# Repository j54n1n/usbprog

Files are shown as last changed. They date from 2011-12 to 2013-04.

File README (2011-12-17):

usbprog is a developer kit for atmels avr controller

	its supports:
		- an ISP Interface (AVRISP mkII Klon)
		- a JTAG Interface (JTAGICE mkII Klon)
		- a seriell Interface (RS232 with an GNU/Linux kernelmodule to use it as /dev/ttyUSBx)

Folders:

avarice_corner
++++++++++++++
Server for the connection between GDB and the jtag interface of the target controller.

avrdude_corner
++++++++++++++
Here is a patched Version of avrdude for usbprog

avrupdate
+++++++++

board
+++++
Schematic, Layout, Partlist

firmware
++++++++
Actual firmware of usbprog

ownflashtool
++++++++++++
I used this tool only for testing

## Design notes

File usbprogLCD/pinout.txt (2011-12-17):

usbprog_lcd
===========

- connect an alphanumeric LCD with HD44780 controller to USBprog
- usbprog 3.0 required!

LCD signal    usbprog pin
-------------------------
GND           10
VCC           2
RS            8 (PB2)
R/W           6 (PB1)
E             4 (PB3)
DB4           3 (PB4)
DB5           1 (PB5)
DB6           9 (PB6)
DB7           7 (PB7)

LCD contrast voltage pin V0:

         VCC
          |
          |
         ---
         | |_
         | /
 V0 _____|/| 10k
         | |
         | |
         ---
          |
          |
         GND

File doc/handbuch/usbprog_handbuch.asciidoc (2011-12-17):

// vim: set sw=2 ts=2 ft=asciidoc spelllang=de_de spell:

USBprog Handbuch
================
:Author: http://www.embedded-projects.net/usbprog/
:Revision: 0.2
:Date: 13. Januar 2008

Im folgenden Handbuch wird die Inbetriebnahme und der Einsatz von USBprog beschrieben.

An dieser Stelle möchte ich mich bei den viele Helfern rund um USBprog bedanken.
Ohne der Community wäre das Projekt nicht das, was es mittlerweile ist. 

Die meisten Texte aus diesem Handbuch stammen von Benedikt Sauter. Es haben unteranderem
Texte für diese Handbuch geschrieben: Robert Schilling, Bernhard Walle und Sven Lütke.

*Kontakt*

Embedded Projects Shop

Inh. Dipl.-Inf. (FH) Benedikt Sauter

Kettengäßchen 6

D-86152 Augsburg

mailto:shop@embedded-projects.net[shop@embedded-projects.net],

http://www.embedded-projects.net[http://www.embedded-projects.net]

*Support*

Support gibt es im http://forum.embedded-projects.net/[Forum]
oder per E-Mail (mailto:sauter@ixbat.de[sauter@ixbat.de]).

*Lizenz*

Dieses Handbuch wurde unter der freien Lizenz GFDL veröffentlicht. Dies bedeutet
jeder hat das Recht den Text zu bearbeiten, muss ihn jedoch ebenfalls wieder
unter der freien Lizenz GFDL veröffentlichen.

Copyright © 2007-2008 mailto:sauter@ixbat.de[Benedikt Sauter], 
Robert Schilling, mailto:bernhard.walle@gmx.de[Bernhard Walle], Sven Lütke

  Permission is granted to copy, distribute and/or modify this document
  under the terms of the GNU Free Documentation License, Version 1.2
  or any later version published by the Free Software Foundation;
  with no Invariant Sections, no Front-Cover Texts, and no Back-Cover
  Texts.  A copy of the license is included in the section entitled "GNU
  Free Documentation License".

Einsatzgebiet und Funktionsumfang
---------------------------------

Was ist USBprog?
~~~~~~~~~~~~~~~~

usbprog ist ein freier Programmieradapter. Über USB kann man bequem verschiedene Firmwareversionen
aus einem "Firmware-Archiv" einspielen. Der Adapter kann aktuell für das Programmieren 
und Debuggen von AVR- und ARM-Prozessoren, als USB-zu-RS232-Wandler, als JTAG-Schnittstelle oder als 
einfacher I/O-Port (10 Leitungen) eingesetzt werden.

Wer braucht usbprog?
~~~~~~~~~~~~~~~~~~~~

Hardware- und Softwareentwickler, die unter Windows, Linux & Co. arbeiten.

Was ist das Besondere an dem Konzept von usbprog?
~~~~~~~~~~~~~~~~~~~~~~~~~~~~~~~~~~~~~~~~~~~~~~~~~

Mit der Zeit soll ein immer größerer Pool an Firmwareversionen enstehen. Idealerweise kann man dann 
als Besitzer von usbprog, wenn man einen neuen Baustein bekommt, mit dem man arbeiten soll, in den 
Online-Pool schauen und suchen, ob es eine passende Firmware zum Programmieren oder Ansteuern 
von diesem Baustein gibt.

Sollte es gerade keine passende Firmware für den benötigten Baustein geben, so sollte man nicht 
überstürzt hohe Einkaufspreise für Adapter auf sich nehmen, sondern zuerst lieber anfragen, 
ob es lohnenswert ist, hier eine neue Firmware für usbprog zu schreiben, um somit in den Firmware-Pool 
zu investieren. Oft ist dies relativ schnell geschehen, da man auf bestehenden Softwarewerkzeuge aufbauen 
kann. Wie im Falle vom AVRISP-mkII-Klon: Diesen kann man mit allen Anwendungen nutzen, die den originalen 
Adapter von Atmel unterstützen. Oder der Adapter für den OpenOCD: Es wurde ebenfalls binnen weniger Tage
entwickelt!

Da alles unter einer Open-Source-Lizenz steht, sollte das Projekt lange Zeit interessant bleiben!

Auszug aus der Firmwareliste
----------------------------

* AVR ISP Programmer (kompatibel zu AVRISP mkII)
* OpenOCD-Interface (ARM Debugging)
* Freier JTAG Adapter und Bibliothek 
* AT89 Programmer 
* SimplePort (10 I/O-Leitungen)
* USB-zu-RS232-Wandler (ohne Treiber!) 
* XSVF Player (Xilinx CPLD/FPGA)
* Logikanalysator

Montage und Aufbau der Hardware
-------------------------------

Die folgende Übersicht gibt einen groben Leitfaden für die Installation.

- Auspacken des Bausatzes (vormontierte Platine, 10-poliger Stecker, USB-Buchse, 2x4-polige Stiftleisten, 1x3-polige Stiftleiste, 3 Jumper)
- USBprog fertig montieren (löten)

Abhängig davon, ob ein bereits vorprogrammierter oder nicht-vorprogrammierter Adapter gekauft worden ist, 
gibt es zwei mögliche Wege:

- USBprog ist bereits vorprogrammiert
  . Benötigte Anwendung (z. B. AVR Studio für AVR-Mikrocontroller oder Yagarto für OpenOCD) installieren
  . USBprog Flashtool installieren
- USBprog ist noch nicht programmiert
  . VCC Jumper entfernen, falls externer AVR Programmierer keine Stromversorgung benötigt
  . Externen AVR Programmer anstecken
  . Reset Jumper stecken
  . usbprog_base.hex flashen
  . Fuse-Bits programmieren
  . Jumper entfernen
  . USBprog Tools installieren (inkl. Treiber)
  . Am PC anstecken -> Neues Gerät sollte erkannt werden (Treiber automatisch installieren)
  . Per Flashtool gewünschte Firmware einspielen

Dies war nur ein grober Leitfaden. In den weiteren Abschnitten werden die einzelnen Schritte
genauer beschrieben.

Löten der restlichen Bauteile
~~~~~~~~~~~~~~~~~~~~~~~~~~~~~

Der USBprog Adapter 3.0 ist anders als die vorherige Version bereits vormontiert. 
Die SMD-Bauteile sind bereits gelötet und nur die "groben" Bauteile müssen selbst angebracht werden. 

Der Adapter wurde so geplant, dass Anstelle der USB-B-Buchse auch ein USB-A-Stecker eingelötet werden kann.
Letzterer hat den Vorteil, dass USBprog in einem passendem Gehäuse als USB-Stick verwendet werden kann.

Folgende Schritte beim Löten sind somit zu erledigen:

* 10-polige Wannenbuchse einlöten
* USB-Buchse montieren und einlöten
* 2x4-polige Stiftleiste fixieren und einlöten
* 3-polige Stiftleiste fixieren und einlöten

In der Abbildung "USBprog Bausatz" sind nochmal alle Bauteile gezeigt.

.USBprog Bausatz
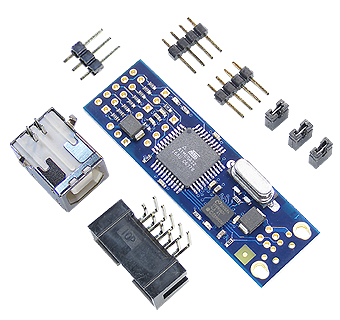
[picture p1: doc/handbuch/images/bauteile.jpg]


Nach den Lötarbeiten sollte USBprog nun wie folgt aussehen:

.USBprog fertig montiert
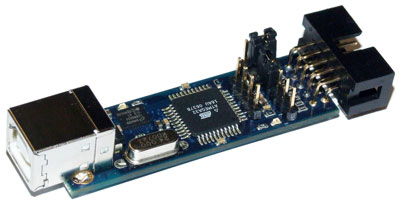
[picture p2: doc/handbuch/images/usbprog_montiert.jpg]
USBprog Bausatz


Anschlussmöglichkeiten und Stiftleisten von USBprog
~~~~~~~~~~~~~~~~~~~~~~~~~~~~~~~~~~~~~~~~~~~~~~~~~~~

.USBprog Übersicht
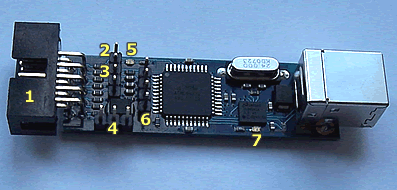
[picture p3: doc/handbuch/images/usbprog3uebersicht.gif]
USBprog Übersicht


. 8 IO-Ports (alternativ SPI-Port) + VCC und GND: PORTB vom ATmega 32
. Jumper kann als Schalter in einer Firmware verwendet werden: PA7 vom ATmega 32
. Reset Jumper Ansteuerung (gesteckt ansteuerbar vom ISP-Stecker)
. Einstellung der Spannungsversorgung (VCC)
. Aus der Firmware ansteuerbare LED: PA4 vom ATmega 32
. UART Anschluss + VCC und GND
. Power LED

Mit dem VCC Jumper kann eingestellt werden, wie der VCC-Pin am 10-poligen Stecker beschalten wird.
Es werden drei Konfigurationen angeboten.

. Ohne Verbindung
. 5 V direkt über USB
. 5 V per Schottky-Diode über USB

.VCC Konfiguration 1 (Ohne Verbindung)
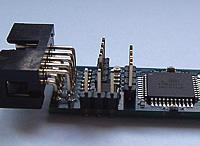
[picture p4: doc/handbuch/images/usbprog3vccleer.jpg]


.VCC Konfiguration 2 (5 V direkt über USB)
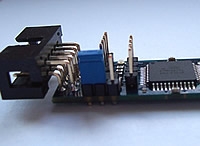
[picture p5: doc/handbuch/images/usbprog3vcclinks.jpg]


.VCC Konfiguration 3 (5 V per Schottky-Diode über USB)
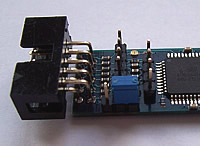
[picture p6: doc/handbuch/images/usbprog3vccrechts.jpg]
Konfiguration 3


Programmierung des Bootloaders
~~~~~~~~~~~~~~~~~~~~~~~~~~~~~~

Der USBprog wird ohne programmierten Bootloader von keinem Betriebssystem erkannt. Das hat den einfachen Grund, 
dass die Ansteuerung des USB-Bausteins in der Firmware des Bootloaders implementiert ist. Wenn der Bootloader
eben nicht im ATmega32 des USBprog ist, hat das Betriebssystem keine Chance, das Gerät zu erkennen.

Die Basis für USBprog ist daher der Bootloader, der es ermöglicht, später ohne externen AVR-Programmer
eine Firmware auf den USBprog aufzuspielen. Um den Bootloader auf den USBprog übertragen zu können,
wird ein externer AVR-Programmer benötigt. Im folgenden werden die bekanntesten Möglichkeiten beschrieben.

Die Datei usbprog_base.hex kann von der Internetseite heruntergeladen werden. 
Nun muss das erste und letzte Mal mit einem externen Programmierer der ATmega 32 auf der USBprog Platine programmiert werden. 
Dafür muss der Reset Jumper wie in der nachstehenden Abbildung gezeigt gesteckt werden. Jetzt kann das Programm normal eingespielt werden. Vielleicht verwundert die Dateigrösse von genau 32 KByte (als .bin). Dies kommt daher, dass der Bootloader am Ende vom Flash-Speicher geschrieben wird. Daher kann der Programmiervorgang etwas dauern.

.USBprog Reset Jumper für Programmierung des Bootloaders
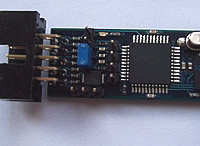
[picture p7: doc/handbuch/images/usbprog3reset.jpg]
USBprog Reset Jumper


Der Reset Jumper muss gesteckt sein, wenn der ATmega 32 extern programmiert werden soll.

Jetzt kann man sich mit einem normalen AVR-Programmiergerät mit dem USBprog verbinden. Die Belegung der 10-poligen ISP-Buchse entspricht der Standardbelegung von Atmel.

.USBprog Pinbelegung als AVR ISP-Buchse
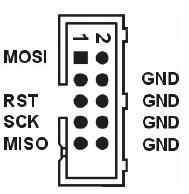
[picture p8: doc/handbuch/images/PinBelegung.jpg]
USBprog AVR ISP Buchse


*avrdude unter Linux und Windows*

Falls die Firmware mit einem AVRISP mkII (oder USBprog AVR-Programmer)
programmiert werden soll, muss als Parameter _-c avrispv2 -P usb_ angegeben werden.
Für ein einfaches Parallelportkabel reicht _-c bsd_.

* Firmware flashen: avrdude -p m32 -c avrispv2 -P usb -B 8 -U flash:w:usbprog_bootloader.hex
* lfuse programmieren: avrdude -p m32 -c avrispv2 -P usb -B 8 -U lfuse:w:0xe0
* hfuse programmieren: avrdude -p m32 -c avrispv2 -P usb -B 8 -U hfuse:w:0xd8

Wird ein einfaches Parallelportkabel verwendet, muss folgende Belegung gewählt werden:

.Parallelportkabel BSD (avrude -c bsd)
'--------------.---------------------------
Parallelport     Funktion
-------------------------------------------
Pin 7            AVR !Reset
Pin 8            AVR SCK (clock input)
Pin 9            AVR MOSI (instruction in)
Pin 10           AVR MISO (data out)
Pin 18           GND
-------------------------------------------

*AVR Studio*

Falls ein Programmiergerät zum Programmieren des Bootloaders des USBprog
eingesetzt wird, das vom AVR Studio unterstützt wird, können die Fuses wie in der folgenden
Abbildung gezeigt eingestellt werden. Als Zielprozessor muss der Typ "ATmega 32" angegeben werden.
Ebenso muss die ISP-Geschwindigkeit auf ca. 250 kHz gestellt werden,
um sicherzustellen, dass die ISP Schnittstelle mit max. 1/4 des CPU Taktes angesteuert wird.

.AVR Studio Fuse-Einstellung (Bootloader)
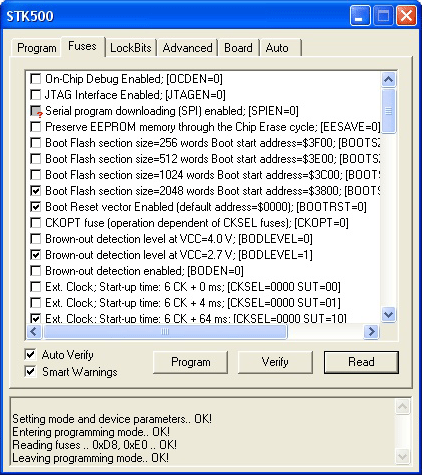
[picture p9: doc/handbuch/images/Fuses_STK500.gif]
AVR Studio Fuses


*PonyProg*

Wird ein PonyProg-kompatibles Programmiergerät für die Erstprogrammierung
des USBprog mit dem Bootloader verwendet, sieht die Fuse-Einstellung wie folgt aus:

.PonyProg Fuse Einstellung (Bootloader)
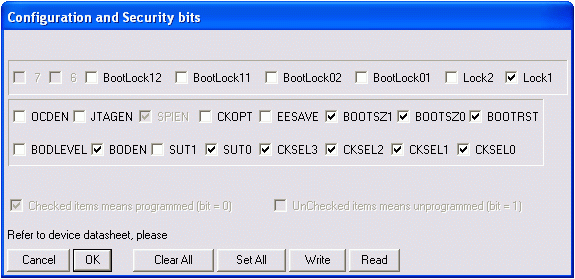
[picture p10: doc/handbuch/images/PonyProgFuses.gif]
PonyProg Fuses


*Tabelle*

.Fuse Bits
'-----.------------.------.--------------------------------------------------------
Nr.  	Fuse 	     Wert   Beschreibung 
-----------------------------------------------------------------------------------
1	 BODLEVEL    1      Brown-Out-Detection 
2	 BODEN	     0	    keine Brown-Out-Detection
3	 SUT0	     0 	    Startup-Time=6 CLK + 64 ms
4	 SUT1	     1	    Startup-Time=6 CLK + 64 ms
5	 CKSEL3..0   0000   externer Takt
6	 CKOPT	     1	    externer Takt
7	 OCDEN	     1	    On-Chip-Debug disable - wichtig wegen Port C (USBN9604)
8	 JTAGEN	     1	    JTAG aus
9	 SPIEN	     0	    SPI an
10	 EESAVE	     1	    Chip Erase löscht auch EEPROM
11	 BOOTSZ1..0  00	    Boot start address = $3800
12	 BOOTRST     0	    Boot Reset
-----------------------------------------------------------------------------------

Erster Funktionscheck
~~~~~~~~~~~~~~~~~~~~~

Nach dem Flashen des Bootloader und dem Einstellen der FUSE-Bits
kann USBprog bereits vom Betriebssystem erkannt werden.

Es empfiehlt sich, die Jumper in folgende Grundstellung zu bringen:

. Reset-Jumper entfernen. Der Jumper wird nur für das Programmieren des Bootloaders benötigt.
. Bootloader-Jumper entfernen. Nach dem Programmieren des Bootloaders befindet sich noch keine Firmware auf dem USBprog
und es wird automatisch der Bootloader gestartet.
. VCC-Jumper entfernen. Hiermit kann gesteuert werden, wie die nach außen geführte VCC-Leitung beschalten werden soll,
also ob die Zielschaltung über USBprog versorgt werden soll. Um sicherzustellen, dass es keinen Kurzschluss
gibt, sollte der VCC-Pin keinen Kontakt haben.

Mit dem Auge kann geprüft werden, ob der Bootloader starten kann. Dies kann am Blinkrhythmus der Status-LED
gesehen werden. Die LED blinkt im Rhythmus: kurz an - kurz aus - kurz an - lang aus.

Wenn die LED entsprechend blinkt, bedeutet dies nur, dass der ATmega 32 korrekt arbeitet. Ob die
USB-Schnittstelle korrekt arbeitet kann nur mit einem Computer überprüft werden.

Blinkt die LED trotz Einspielen des Bootloaders und Einstellen der Fuse-Bits nicht,
kann mit einem Oszilloskop oder Logikanalysator festgestellt werden, ob die Schaltung denn irgendetwas macht,
oder ob ein größeres Problem vorliegt.  Am einfachsten misst man dafür die
Frequenz am Taktausgang des USB-Bausteins, welcher als Taktquelle für den
ATmega 32 dient und an dieser Seite auch einfacher gemessen werden kann (da der
USB-Baustein von unten angelötet wurde und man daher nicht direkt an die
Pads kommt).

.Takteingang ATmega 32 (Pad 4 von oben gezählt am ATmega 32)
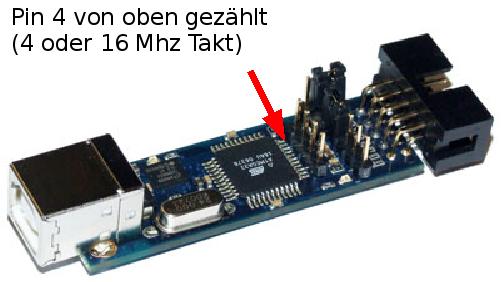
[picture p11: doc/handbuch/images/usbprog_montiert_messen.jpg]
Taktsignal


Befindet sich kein Bootloader im ATmega 32 oder ist die Kommunikation zwischen dem USB-Baustein und
dem ATmega 32 gestört, sollten dort 4 MHz anliegen. Ist der Bootloader aktiv so kann dies anhand der
anliegenden 16 MHz festgestellt werden. Das Umschalten der Taktgeschwindigkeit von 4 MHz auf 16 MHz klappt
nur dann, wenn die Verbindung zwischen USB-Baustein und ATmega 32 in Ordnung ist und der Bootloader
korrekt gestartet wurde.

*GNU/Linux*

Mit Hilfe des Kommandos lsusb aus den usbutils (über die Paketverwaltung muss ggf. das Paket _usbutils_ nachinstalliert
werden) kann geprüft werden, ob USBprog mit dem Bootloader vom Betriebssystem erkannt wird.

------------------------------------------
big:/home/bene$ lsusb 
...
Bus 002 Device 035: ID 1781:0c62  
...
------------------------------------------

Dies ist die Kennung der Bootloaders (0x1781 = Hersteller-ID, 0x0c62 = Produktnummer)

*Windows*

In Windows sollte der beim Einstecken eines neuen Gerätes typische Klang hörbar
sein, und der Treiberinstallationsassistent nach dem Ort des Treibers fragen.
An dieser Stelle sollte man abbrechen, falls noch nicht die USBprog-Tools
installiert wurden.

USBprog Flashtool
-----------------

Mit dem USBprog-Tool kann die Firmware des USBprog-Geräts einfach gewechselt werden. Es unterstützt

* das Herunterladen der Firmware von einem Online-Pool,
* einen Offline-Modus (Cache) zum Betrieb an PCs ohne Internet,
* das Hochladen von lokalen Firmwaredateien zum Testen,
* mehrere USBprog-Geräte an einem PC und
* das Anzeigen von Informationen über eine Firmware, inkl. der Pinbelegung.

Von USBprog gibt es sowohl eine GUI-Version als auch eine Kommandozeilen-Version. Die Kommandozeilen-Version 
verfügt über einen interaktiven Modus (wie eine Shell) und einen Batch-Modus, kann daher problemlos in Skripte, 
Makefiles o.ä. integriert werden.

Beide Versionen verwenden die gleichen Funktionen, um auf das Gerät zuzugreifen und um den Firmware-Cache zu verwalten. 
Dies wurde damit realisiert, dass diese Funktionen in einer Bibliothek gekapselt sind. Somit wird die Konsistenz beider 
Versionen gewahrt und die Entwicklung vereinfacht.

Sowohl die GUI-Version als auch die Kommandozeilen-Version laufen unter Microsoft Windows und Linux. 
Eine Portierung auf anderen Unix-artige Betriebssysteme sollte sehr einfach möglich sein, wenn auch den Autoren die Zeit fehlt, dies zu testen.

Da ein Bild bekanntlich mehr als tausend Worte sagt, hier ein Screenshot sowohl der GUI- als auch der Kommandozeilen-Version, um einen Eindruck der Applikation zu bekommen.
GUI-Version (unter Linux)

.USBprog GUI 
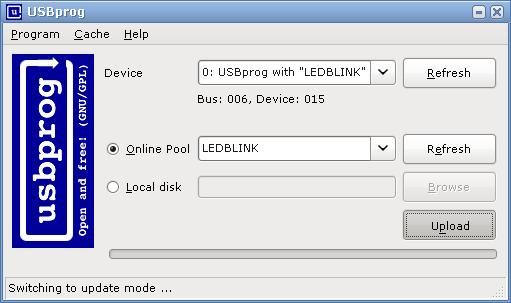
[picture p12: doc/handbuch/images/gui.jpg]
GUI


Kommandozeilenversion (unter Linux)

.USBprog Konsole
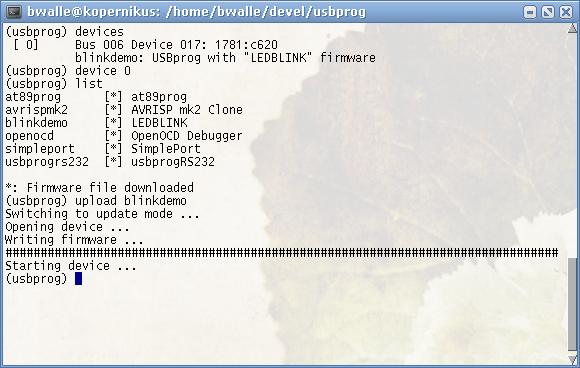
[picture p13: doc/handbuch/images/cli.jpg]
Konsole


Installation unter GNU/Linux
~~~~~~~~~~~~~~~~~~~~~~~~~~~~

Linux ist nicht gleich Linux. Das bedeutet die Installation ist stark abhängig von
der eingesetzen Distribution.

Installation des Programms
^^^^^^^^^^^^^^^^^^^^^^^^^^

Installation unter openSUSE und Fedora
++++++++++++++++++++++++++++++++++++++

Binärpakete für openSUSE und Fedora findet man im openSUSE-Buildservice im Repository "electronics".
Die URL lautet: http://download.opensuse.org/repositories/electronics/. Dort
findet man für verschiedene openSUSE- und und Fedora-Versionen jeweils ein Paketrepository.
Dies kann nun mit YaST bzw. zypper (openSUSE) oder und yum (Fedora) hinzugefügt
werden. Danach kann das entsprechende Paket installiert werden.

Beispiel für zypper unter openSUSE 10.3

-----------------------------------------------------------------------------------------
$ zypper ar -r \
 http://download.opensuse.org/repositories/electronics/openSUSE_10.3/electronics.repo
$ zypper ref
$ zypper install usbprog usbprog-gui
-----------------------------------------------------------------------------------------

Natürlich kann man auch einfach die RPM-Pakete manuell herunterladen und mit
rpm auf der Kommandozeile installieren. Außer den usbprog-Paketen (`usbprog`
für die Bibliothek und das Kommandozeilenprogramm, `usbprog-gui` für die
grafische Oberfläche und `usbprog-devel` zum Entwickeln eigener Programme auf
Basis der Bibliothek) sind keine Pakete aus dem Repository notwendig.

Wohl aber kann es nötig sein, andere Pakete aus der Distribution
nachzuinstallieren. Dies hängt mit der Auswahl der bereits installierten Pakete
ab, rpm bringt aber selbstverständlich eine Fehlermeldung, falls benötigte
Pakete nicht vorhanden sind. Die oben erwählten Paketverwaltungsprogramme
zypper und yum übernehmen dies automatisch und sollten daher bevorzugt
verwendet werden.

Installation unter Debian oder Ubuntu
+++++++++++++++++++++++++++++++++++++

TDB

Installation aus den Quellen heraus
+++++++++++++++++++++++++++++++++++

Falls keine Binärpakete vorhanden sind, kann auf jeder Distribution die
Installation aus dem Quellcode erfolgen.  Zunächst sollte sichergestellt
werden, dass das System folgende Abhängigkeiten erfüllt:

* libusb zum Zugriff auf das Gerät,
* libxml zum Parsen der Firmwarebeschreibungsdatei,
* libcurl zum Downloaden der Firmware,
* readline zum einfachen Editieren der Kommandozeile (optional),
* wxWidgets, falls die GUI-Version kompiliert werden soll und natürlich
* ein hinreichend neuer C\+\+-Compiler wie den g\+\+.

Nachdem dies sichergestellt wurde, erfolgt die Installation ganz üblich mit:

. Auspacken des Tarballs und Wechseln in das Verzeichnis,
. Ausführen von ./configure,
. make zum Kompilieren und schließlich
. make install zum Installieren der Dateien (als Administrator).

Zugriff auf USBprog als Benutzer
^^^^^^^^^^^^^^^^^^^^^^^^^^^^^^^^

Standardmäßig kann nur der Administrator unbeschränkt auf USB-Geräte zugreifen.
Damit dies auch dem einfachen Benutzer möglich wird, müssen udev und HAL
entsprechend konfiguriert werden, die jeweiligen Dateien unter /dev/bus/usb
auch für normale Benutzer schreibbar zu machen.

openSUSE
++++++++

Unter openSUSE reicht das Anlegen einer Datei /etc/hal/fdi/policy/20customized mit folgendem Inhalt:
-------------------------------------------------------------------------
<?xml version="1.0" encoding="utf-8"?>
 <deviceinfo version="0.2">
  <!-- USBprog in update mode or various demos -->
   <device>
     <match key="info.bus" string="usb_device">
       <match key="usb_device.vendor_id" int="0x1781">
         <match key="usb_device.product_id" int="0x0c62">
           <merge key="resmgr.class" type="string">scanner</merge>
         </match>
       </match>
     </match>
   </device>
  <!-- Atmel AVR ISP MKII -->
   <device>
     <match key="info.bus" string="usb_device">
       <match key="usb_device.vendor_id" int="0x03eb">
         <match key="usb_device.product_id" int="0x2104">
           <merge key="resmgr.class" type="string">scanner</merge>
         </match>
       </match>
     </match>
   </device>
 </deviceinfo>
-------------------------------------------------------------------------

Damit werden USBprog-Geräte wie Scanner behandelt, was entsprechend bedeutet,
dass der gerade (direkt, nicht über SSH) eingeloggte Benutzer auf das Gerät
zugreifen darf.

Andere Distributionen
+++++++++++++++++++++

Eine Möglichkeit ist dies über das udev System zu machen. Dafür müssen folgende
Schritte als root vollzogen werden:

* Neue Gruppe anlegen: _addgroup usbprog_
* Benutzer der Gruppe zuweisen: _adduser benutzer usbprog_ (unbedingt den Benutzer danach ein- und ausloggen)
* Öffnen und erweitern der Datei: /etc/udev/rules.d/80-usbprog.rules
* Neustarten von udev: /etc/init.d/udev restart

-------------------------------------------------------------------------------
ATTRS{idVendor}=="1781", ATTRS{idProduct}=="0c62", GROUP="usbprog", MODE="0660"
-------------------------------------------------------------------------------

Voraussetzung ist natürlich, dass udev installiert ist. In Debian geht dies per _apt-get install udev_.

Jetzt sollte der Zugriff mit jedem Benutzer in der Gruppe usbprog funktionieren. 

Installation unter Windows
~~~~~~~~~~~~~~~~~~~~~~~~~~

Die USBprog-Software läuft unter Windows 2000 und XP. Die DOS-basierten Windows-Versionen 95, 98 und ME werden nicht unterstützt.
Da ein Installer verwendet wird, ist die Installation unter Windows denkbar einfach:

. Laden Sie die Datei aktuelle USBprog-Version herunter.
. Führen Sie die Installationsdatei aus und folgen Sie den Anweisungen. Beachten Sie, dass das Treiberpacket zwingend notwendig ist.
. Beim Anstecken des USBprog sollte ihn Windows im “Updatemodus” erkennen und beginnt mit der Plug-&-Play-Treiberinstallation.
. Wählen Sie bei der Treiberinstallation die Option Software automatisch installieren.
. Nun kann USBprog mit Hilfe des Flashtools aktualisiert werden.

Achtung: 
	
Wechseln in den Update-Modus!
Unter Windows sollte vor dem Wechseln immer manuell in den Update-Modus gebracht werden! Mehr dazu gibt es im Kapitel der Bootloader.

Installation unter MacOS
~~~~~~~~~~~~~~~~~~~~~~~~~

folgt (bitte im Forum nachfragen)

Bootloader (Konzept und Bedienungshinweise)
-------------------------------------------

Der Bootloader bietet die Plattform für das einfache Austauschen der Firmware.
Da es mit der ersten Version des Bootloaders unter Windows immer wieder
Probleme gab, wurde der Bootloader weiterentwickelt.

.USBprog Bootloader
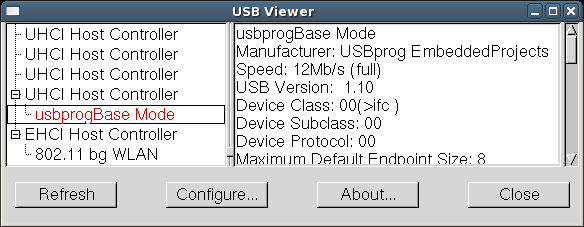
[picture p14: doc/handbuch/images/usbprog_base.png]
USBprog Bootloader


Ursprünglich sollte der Bootloader einfach bequem per PC-Programm aktiviert werden können. Unter GNU/Linux klappt das auch einwandfrei. Mit Windows gibt es leider viele Probleme. Das liegt wohl am Treiberstack von Windows. Unter GNU/Linux kann man beispielsweise mit der Bibliothek libusb ohne extra Treiberinstallation auf jedes angeschlossene USB-Gerät zugreifen. In Windows muss man, wenn man mit der Bibliothek libusb arbeitet, dennoch einen Treiber für jedes Gerät unter der libusb installieren. Dies ist eine beliebte Quelle für Fehler. Oft erkennt Windows nicht, welchen Treiber es laden muss, wenn während des Betriebs die Firmware und somit die Bezeichnung für das USB-Gerät gewechselt hat. Aus diesem Grund kann man jetzt den Bootloader manuell per Jumper starten. Dadurch kommt es zu diesem Problem nicht mehr, dass während des Betriebs eines Geräts die Kennung wechselt und Windows einen Treiber umladen muss. Im nächsten Abschnitt wird erklärt, wie der Bootloader verwendet wird.

.USBprog Bootloader Jumper (Bootloader Start-Jumper)
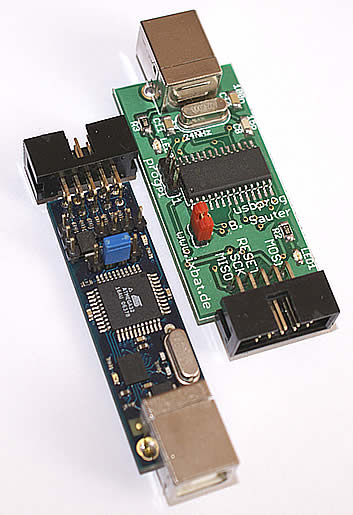
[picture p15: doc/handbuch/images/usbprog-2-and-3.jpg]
USBprog Bootloader Jumper


Der Bootloader kann jetzt mittels eines Jumpers gestartet werden. Ist beim Anstecken von USBprog ein Jumper zwischen TX und RX, wird der Bootloader gestartet. Wenn der Bootloader aktiv ist, blinkt die Leuchtdiode in einem bestimmten Rhythmus:  lang aus - kurz an - kurz aus - kurz an - kurz aus - lang aus.

Nach dem der Bootloader gestartet wurde, kann entweder mit dem grafischen oder mit dem Konsolenprogramm die Firmware gewechselt werden. Der Jumper sollte danach wieder entfernt werden, da sonst immer erst der Bootloader und nicht die frisch eingespielte Firmware startet. 

*Linux:*

Unter Linux kann der Bootloader weiterhin ohne den Jumper, also per USB, gestartet werden.

*Windows:*

Mit einigen Windowsinstallationen kann ebenfalls ohne Jumper, also per USB, der Bootloader gestartet werden (mittels des Flashtools). Aber bei vielen Windowsversionen bereitet dies nur Probleme. Bei diesen Versionen sollte deshalb immer so vorgegangen werden:

* erst Jumper setzen
* dann USBprog anstecken
* mit dem Flashtool eine Firmware auswählen und übertragen
* USBprog abstecken
* Jumper entfernen
* USBprog anstecken

.Hinweis UART-Anschluss und Bootloader
**************************************************************************************************
Die Leitungen TX und RX können dennoch weiterhin in Firmwares (wie z. B. im USB-zu-RS232-Wandler) 
verwendet werden. Beim Starten sind die beiden Leitungen als UART aktiv, das heißt mit dem Setzen 
des Jumpers baut man sich sozusagen eine Nullmodemverbindung. Der Bootloader überträgt ein 
bestimmtes Zeichen und prüft, ob er das auch wieder empfangen hat. Wenn dies der Fall ist, wird der 
Bootloadermodus aktiviert.
**************************************************************************************************

Firmware wechseln 
-----------------

Nach der Installation sollte das Gerät zunächst getestet werden. Hierzu bietet sich die “blinkdemo” Firmware an. Die Bedienung der GUI-Version sollte hinreichend selbsterklärend sein. Gestartet wird die Software unter Windows über das entsprechende Icon, unter Linux über die Programmdatei usbprog-gui.
Kommandozeilenversion

. Starten Sie die Kommandozeilenversion in einem Terminal mit dem Aufruf von usbprog.
. Das Programm lädt nun online eine Indexdatei herunter. Lassen Sie sich mit list eine Liste aller verfügbaren Firmwaredateien anzeigen.
. Laden Sie mit download blinkdemo die oben erwähnte “blinkdemo” Firmware herunter.
. Zeigen Sie sich mit devices alle verfügbaren USBprog-Geräte an. Mindestens ein Gerät sollte in der Liste enthalten sein. Falls das USBprog-Device bereits im Updatemodus ist, sollte dies in der Liste bereits mit einem Stern markiert sein. Andernfalls geben Sie manuell mit device 0 an, dass das erste Gerät als Updategerät verwendet werden soll.
. Laden Sie nun mit upload blinkdemo die “blinkdemo” Firmware auf das Gerät. Die Firmware sollte automatisch starten.

*Hilfe*

Das Kommandozeilenprogramm gibt mit dem Kommando help eine Liste aller verfügbaren Kommandos aus. Mit helpcmd Kommando kann man sich spezifische Hilfe zu einem Kommando ausgeben lassen.

Unter Linux sind zu beiden Programmen (also usbprog und usbprog-gui) Manpages installiert. Diese erhalten ebenfalls eine Kurzzusammenfassung der entsprechenden Befehle und Optionen.

Beliebte Fehlerquellen
----------------------

* Schlechte Lötstellen an der USB-Buchse
* Falsche Konfiguration der FUSE-Bits
* Firmware falsch in den Flash des Mikrocontrollers übertragen
* altes Flashtool mit neuem Bootloader
* falsche ISP-Geschwindigkeit eingestellt (max. 1/4 des CPU Taktes)
* 24 MHz Grundtonquarz
* Reset Jumper fälschlicherweise gesetzt oder nicht gesetzt

Anwendungen mit USBprog
-----------------------

Im folgenden sind die wichtigsten Firmwareversionen hier beschrieben. Da dieses Handbuch nicht immer
auf dem neusten Stand ist, empfiehlt es sich bei Problemen auf den Internetseiten von Embedded Projects
mögliche Hilfen zu suchen.

AVR ISP Programmer (STK500 kompatibel)
~~~~~~~~~~~~~~~~~~~~~~~~~~~~~~~~~~~~~~

Der AVR ISP Programmer wurde nach den freigegeben Datenblättern von Atmel entwickelt.
Daher kann er mit allen Anwendungen die den AVRISP mkII unterstützen genutzt werden.

Die bekanntesten Anwendungen sind:

* AVR Studio 4 (Windows)
* avrdude (GNU/Linux, Windows, MacOS)
* http://www.hpinfotech.ro/html/download.htm[CodeVisionAVR]

Im folgenden wird kurz erklärt was bei der Installation und Verwendung des AVR Studios
und avrdude zu beachten ist.

AVR Studio 4
^^^^^^^^^^^^

Das AVR Studio liefert eigene Treiber für den originalen AVR ISP Programmer mit.
Bei der Installation muss jedoch explizit angegeben werden, dass diese auch
installiert werden. Ist das AVR Studio bereits installiert, kann nachträglich
über die Systemsteuerung (Software -> Reparieren) der Treiber aktiviert werden.

Steckt man den USBprog mit der AVR Programmer Firmware an, so sollte Windows
automatisch den AVR Studio Treiber (Jungo) finden und aktivieren.

avrdude unter Windows
^^^^^^^^^^^^^^^^^^^^^

Das bekannte Programm avrdude aus der Linux-Welt kann ebenfalls in Windows genutzt werden.
Es befindet sich im Archiv von WinAVR. Das bedeutet, dass zuerst WinAVR aus dem Internet
heruntergeladen und installiert werden muss.

*Verwendung des AVR Studio Treibers*

Nachdem WinAVR Installiert ist, muss man dafür sorgen, das Windows einen Treiber für USBprog
mit dem AVR Programmer hat. Entweder verwendet man den originalen AVR Studio Treiber, dafür
muss man aber das AVR Studio wie im Absatz "AVR Studio 4" beschrieben installieren, oder man
installiert einen freien libusb-Treiber, der bereits im WinAVR Paket mitgeliefert wird.

*Verwendung des freien libusb-Treibers*

Alternativ zum originalen Treiber kann auch der freie libusb Treiber installiert werden. Wenn
der Windows-Assistent sich öffnet, muss gewählt werden, dass der Pfad zum Treiber manuell angegeben wird.
Die Treiberdateien befinden sich nach der Installation von WinAVR im Verzeichnis `c:\WinAVR\utils\libusb`.

avrdude unter GNU/Linux
^^^^^^^^^^^^^^^^^^^^^^^

Entweder kann avrdude über die Paketverwaltung installiert werden oder es wird der klassische
Linux Installationsprozess über den Quellcode gewählt.

Installation per APT (Debian, Ubuntu und Derivate) (als root ausführen)
+++++++++++++++++++++++++++++++++++++++++++++++++++++++++++++++++++++++

--------------------------------------------------------------------------
rechner:/root# apt-get install avrdude
Reading package lists... Done
Building dependency tree... Done
Suggested packages:
  avrdude-doc
The following NEW packages will be installed:
  avrdude
0 upgraded, 1 newly installed, 0 to remove and 47 not upgraded.
Need to get 0B/154kB of archives.
After unpacking 700kB of additional disk space will be used.
Selecting previously deselected package avrdude.
(Reading database ... 66442 files and directories currently installed.)
Unpacking avrdude (from .../avrdude_5.2-2_i386.deb) ...
Setting up avrdude (5.2-2) ...
--------------------------------------------------------------------------

Klassische Linux Installation

Für die Installation muss das neuste Quelltextarchiv zuvor heruntergeladen werden.
Die aktuelle Version kann von http://download.savannah.gnu.org/releases/avrdude/
heruntergeladen werden.

--------------------------------------------------------------------------
sauter:/root# cd /usr/src/
sauter:/usr/src# wget -q http://download.savannah.gnu.org/releases/avrdude/avrdude-5.5.tar.gz
sauter:/usr/src# tar xzf avrdude-5.5.tar.gz 
sauter:/usr/src# cd avrdude-5.5
sauter:/usr/src/avrdude-5.5# ./configure 
....
config.status: creating doc/Makefile
config.status: creating windows/Makefile
config.status: creating avrdude.spec
config.status: creating Makefile
config.status: creating avrdude.conf.tmp
config.status: creating ac_cfg.h
config.status: executing depfiles commands
sauter:/usr/src/avrdude-5.5# 
--------------------------------------------------------------------------

An dieser Stelle kann es zu Fehler kommen, wenn die Bibliothek libusb
nicht installiert ist. Auf einem Debian-basierten System können
per APT die fehlenden Komponenten nachinstalliert werden. Ebenso werden
die Programme bison, flex und g++ für die Übersetzung des Quelltextes benötigt.

------------------------------------------------------------------------------------
rechner:/usr/src/avrdude-5.5# apt-get install libusb-0.1-4 libusb-dev bison flex g++
------------------------------------------------------------------------------------

Der letzte Befehl muss zwingend als root ausgeführt werden.

--------------------------------------------------------------------------
sauter:/usr/src/avrdude-5.5# make
...
sauter:/usr/src/avrdude-5.5# make install 
--------------------------------------------------------------------------

avrdude Bedienhinweise
^^^^^^^^^^^^^^^^^^^^^^

Ein Aufruf um die Signatur eines ATmega 32 auszulesen sieht wie folgt aus:
-----------------------------------
avrdude -p m32 -c avrispv2 -P usb
-----------------------------------

Beliebte Fehlerquellen bei AVR ISP Programmer
^^^^^^^^^^^^^^^^^^^^^^^^^^^^^^^^^^^^^^^^^^^^^

* VCC-Jumper falsch gesteckt
* Reset-Jumper gesteckt obwohl er entfernt sein muss
* Falsche ISP-Geschwindigkeit (max. 1/4 des CPU-Takts):
  . Angabe der richtigen ISP-Geschwindigkeit mit avrdude mit dem Parameter -B 8 (125 kHz) oder -B 1 (1MHz)
  . Angabe der richtigen ISP-Geschwindigkeit mit dem AVR Studio 4 über das "Register Board" (und "Write" nicht vergessen)

OpenOCD ARM7/ARM9 Debugger
~~~~~~~~~~~~~~~~~~~~~~~~~~

Mit der OpenOCD-Firmware für den USBprog-Adapter lassen sich viele ARM-basierte Mikrocontroller im eingebauten 
Zustand (in-circuit) programmieren. Der Adapter ermöglicht Echtzeitdebugging, das Setzen von Breakpoints und 
Ausführen von Einzelschritten, also die ganze Funktionspalette, welche zur erfolgreichen Anwendungsentwicklung 
und zum effizienten Debugging benötigt werden. Angesteuert wird er über OpenOCD von Dominic Rath.

NEU: Im Testing-Zweig von Debian Sarge ist mittlerweile OpenOCD samt USBprog-Unterstützung integriert, d. h.
es kann einfach über die Paketverwaltung installiert werden!

Dieser Adapter ist relativ langsam! Aber die Geschwindigkeit reicht für die meisten einfachen Programmier- und 
Debugsessions völlig aus! Ein Singlestep auf der Telnetkonsole geht fast ohne Verzögerung. 

OpenOCD unter Linux
^^^^^^^^^^^^^^^^^^^

Debian (Testing)
++++++++++++++++

* `apt-get install openocd`

Aus dem Quelltext
+++++++++++++++++

* Quelltextarchiv herunterladen mit Subversion:
  `svn checkout http://svn.berlios.de/svnroot/repos/openocd/trunk`
* Kompilierung vorbereiten: `./configure --enable-usbprog`
* Kompilieren: `make`
* Installieren in das Dateisystem: `make install`

OpenOCD unter Windows 
^^^^^^^^^^^^^^^^^^^^^

Für Windows pflegt Michael Fischer eine Installationversion von OpenOCD. Diese ist über die Homepage http://www.yagarto.de/ erreichbar. Da USBprog noch relativ frisch ist, gibt es erstmal hier auf meiner Seite ausschließlich eine Yagarto OpenOCD USBprog Version. Die Datei muss einfach heruntergeladen und installiert werden.

Entweder kann man anschließend openocd von einer Shell aus starten oder in eine Entwicklungsumgebung (z. B. Eclipse) integrieren.
 
Arbeiten mit dem OpenOCD Debugger
^^^^^^^^^^^^^^^^^^^^^^^^^^^^^^^^^

*GNU/Linux*

Vor etwas längerer Zeit habe ich mal ein kleines Demo hier zusammengeschrieben. 
Ich denke mal es sollte als Leitfaden ausreichend sein. LPC2103(ARM7) mit OpenOCD unter Linux entwickeln

*Windows*

Da ich selber aus der Linux Ecke komme verweise ich direkt auf die Seiten von Michael Fischer. 
Hier wird beschrieben wie man unter Windows mit OpenOCD und dem GCC entwickeln kann: http://www.yagarto.de/howto.html

SimplePort
~~~~~~~~~~

Mit dieser Firmware können ganz einfach die 10 nach außen geführten Leitungen als Ein- und Ausgabeleitungen verwendet werden. Dazu gibt es eine kleine Bibliotheken in C, Python und Java die unter Windows, Linux und in MacOS einsetzbar sind.

Für erste Tests kann man die Leitung 11 als Ausgang verwenden. Hierbei handelt es sich um die LED. So könnte ein C-Beispiel (C99) aussehen:

-----------------------------------------------------------
  struct simpleport *sp_handle;

  sp_handle = simpleport_open();
  if (!sp_handle)
      return;
  
  simpleport_set_pin_dir(sp_handle, 11, 1);

  for (int i = 0; i < 4; i++) {
    simpleport_set_pin(sp_handle, 11, 1); // LED an
    sleep(1);
    simpleport_set_pin(sp_handle, 11, 0); // LED aus
    sleep(1);
  }

  simpleport_close(sp_handle);
-----------------------------------------------------------

Im Downloadbereich gibt es Beispiele, in denen gezeigt wird, wie die Bibliotheken in den verschiedenen Sprachen eingesetzt werden können.

Die verschiedenen Ansteuerungen aus den einzelnen Sprachen wie Java und Python wurden mit SWIG realisiert. Jederzeit können ohne großen Aufwand weitere Anbindungen erzeugt werden.  SWIG kann aktuell Anbindungen für die folgenden Sprachen erzeugen: Allegro CL, C#, Chicken, Guile, Java, Modula-3, Mzscheme, OCAML, Perl, PHP, Python, Ruby, Tcl.

Anschlussbelegung
^^^^^^^^^^^^^^^^^
10-polige Stecker

'-----'-------------'----------
Pin    Bezeichnung   Aufrufname
-------------------------------
1      IO1	     1
2      VCC	     
3      IO2	     2 
4      IO3	     3 
5      IO4	     4 
6      IO5	     5 
7      IO6	     6 
8      IO7	     7 
9      IO8	     8
10     GND	     
1-0    IO9  (JP3     9
1-1    IO10 (JP3)    10
LED    IO11          11
-------------------------------

Auf der Platine befindet sich zusätzlich eine rote LED. Diese kann, wenn IO11 als Ausgang konfiguriert ist, angesteuert werden.

Bibliothek in C
^^^^^^^^^^^^^^^

Verbindung mit SimplePort aufbauen:

_struct simpleport* simpleport_open();_

Verbindung beenden: 

_void simpleport_close(struct simpleport *simpleport);_

Datenrichtung der Signale definieren (IO 1 .. IO 8), 1 = Ausgang, 0 = Eingang:

_void simpleport_set_direction(struct simpleport *simpleport, unsigned char direction);_

Bsp.: IO 1 - IO 4 = Taster und IO 5 - IO 8 = LED:
(als Hexzahl ist das: 0x0F)

Mit der Funktion können nur die Datenrichtungen für IO 1 bis IO 8 angegeben werden. Für IO 9 bis IO 11 
müssen diese mit der Funktion

_void simpleport_set_pin_dir(struct simpleport *simpleport,int pin, int dir);_

einzeln angegeben werden.

Datenrichtung einer einzelnen Leitung (auch IO 9 bis IO 11), 1=Ausgang, 0=Eingang:

_void simpleport_set_pin_dir(struct simpleport *simpleport,int pin, int dir);_

Port setzen (IO 1 bis IO 8):

_void simpleport_set_port(struct simpleport *simpleport, unsigned char value);_

Port lesen (IO 1 bis IO 8): 

_unsigned char simpleport_get_port(struct simpleport *simpleport);_

Einzelne Leitung setzen (IO 1 bis IO 11):

_void simpleport_set_pin(struct simpleport *simpleport, int pin, int value);_

Eine einzelne Leitung lesen (IO 1 bis IO 11):

_int simpleport_get_pin(struct simpleport *simpleport, int pin);_

Beispiel in C
^^^^^^^^^^^^^

--------------------------------------------------------------
#include <stdio.h>
#include <stdlib.h>
#include "simpleport.h"
  
int main(int argc, char *argv)
{
  struct simpleport *sp_handle;

  sp_handle = simpleport_open();
  
  if (!sp_handle) {
    fprintf(stderr, "unable to open device\n");
    return EXIT_ERROR;
  }
  
  simpleport_set_direction(sp_handle, 0xFF);
  
  while (1) {
    simpleport_set_port(sp_handle, 0xFF);
    simpleport_set_port(sp_handle, 0x00);
  }

  simpleport_close(sp_handle);

  return EXIT_SUCCESS;
}
--------------------------------------------------------------    

Beispiel in Java 
^^^^^^^^^^^^^^^^

--------------------------------------------------------------
class Demo
{
  public static void main(String[] args) {
    try {
      // tell the system to load the shared library into memory
      System.load("/lib/_simpleport.so");
      // the functions of '_simpleport.so' are accessed over the java-class
      // 'simpleport', that was created by SWIG.
      // 'simpleport_open()' returns a instance of 'SWIGTYPE_p_simpleport' if
      // a suitable hardware was found.
  
      SWIGTYPE_p_simpleport sp_handle = simpleport.simpleport_open();
      // set the port-direction to 'write'
      simpleport.simpleport_set_direction(sp_handle, (short) 0xFF);
      System.out.println("... blink!");
  
      // periodically set entire port to '00000000' and '11111111'
      while (true){
        simpleport.simpleport_set_port(sp_handle, (short)0xFF, (short)0xFF);
        Thread.sleep(1000);
        simpleport.simpleport_set_port(sp_handle, (short)0x00, (short)0xFF);
        Thread.sleep(1000);
      }
    } catch (Exception e) {
      e.printStackTrace();
    }
  }
}
--------------------------------------------------------------    

Beispiel in Python 
^^^^^^^^^^^^^^^^^^
--------------------------------------------------------------    
import simpleport
import time
  
if __name__ == "__main__":
    # call simpleport_open() to retrive a handle
    sp_handle = simpleport.simpleport_open()
  
    # periodacally set entire port to '11111111' and '00000000'
    while 1:
        simpleport.simpleport_set_port(sp_handle, 0xFF, 0xFF)
        time.sleep(1)
        simpleport.simpleport_set_port(sp_handle, 0x00, 0xFF)
        time.sleep(1)
  
    # close handle (never reached in this case)
    simpleport.simpleport_close(sphand)
--------------------------------------------------------------        

SimplePort RS232
~~~~~~~~~~~~~~~~

Mit SimplePortRS232 kann können einfach und bequem die IO-Pins von USBprog
über ein Terminal oder Bibliotheken für die serielle Schnittstelle angesteuert werden.

Das Gerät meldet sich in Windows als virtueller Comport und in GNU/Linux
als /dev/ttyACM0 an. Jetzt kann mit jeder Programmiersprache die ein
Interface für die serielle Schnittstelle anbietet gearbeitet werden.

Die Durchnummerierung der einzelnen Pins sieht wie folgt aus:

'-----'-------------'----------
Pin    Bezeichnung   Aufrufname
-------------------------------
1      IO1	     1
2      VCC	     
3      IO2	     2 
4      IO3	     3 
5      IO4	     4 
6      IO5	     5 
7      IO6	     6 
8      IO7	     7 
9      IO8	     8
10     GND	     
LED    IO11          B
-------------------------------

Kommandos für die Ansteuerung der Leitungen
^^^^^^^^^^^^^^^^^^^^^^^^^^^^^^^^^^^^^^^^^^^

Die Kommandos werden als ASCII-Zeichen übertragen. Das hat den Vorteil,
das die Funktionalität bereits mit einem einfachen Terminal überprüft werden kann.

*Datenrichtung einer einzelnen Leitung definieren*

Kommando: d<Aufrufname><Richtung>\*

* Aufrufname - (siehe Tabelle Pin/Bezeichnung/Aufrufname)
* Richtung - 1=Ausgang, 0=Eingang (mit internen Pullups)

Rückgabewert: keiner

Beispiel: dB1\* (Status LED als Ausgang), d10\* (IO1 als Eingang)

*Signale einer Ausgangsleitung setzen*

Kommando: p<Aufrufname><Wert>\*

* Aufrufname - (siehe Tabelle Pin/Bezeichnung/Aufrufname)
* Wert - 1 = 5V (high) , 0 = GND (low)

Rückgabewert: keiner

Beispiel Aufruf: pB1\* (Status LED an), pB0\* (Status LED aus)

*Signal an einer Eingansleitung lesen*

Kommando: i<Aufrufname>\*

* Aufrufname - (siehe Tabelle Pin/Bezeichnung/Aufrufname)

Rückgabewert: 2 Bytes abholen 

Als Rückgabewert müssen für die Funktion immer 2 Werte sofort
nach dem Ausführen des Kommandos abgeholt werden.
Die Antwort ist wie folgt zu lesen: i0 = 0V (low), i1 = 5V (high).

Beispiel Aufruf: i1\* (Abfrage Signal IO1)
Beispiel Antwort: i0 (Signale hatte den Wert low), i1 (Signal hatte den Wert high)

*Ersten 8 IO Leitungen auf einmal abfragen*

Kommando: g\*

Sollen zu einem Zeitpunkt mehrere Leitungen abgefragt werden,
um beispielsweise bei mehreren angeschlossenen Tastern eine Tastenkombination
zu einem Zeitpunkt zu ermitteln, kann dies mit der aktuellen Funktion geschehen.
Es werden beim Aufruf des Kommandos die Werte zum gleichen Zeitpunkt gemessen.

Rückgabewert: 8 Bytes  abholen 

Das Ergebnis ist eine Reihe von acht 0 und 1 Werten. Die ganz linke 
Zahl entspricht IO1 und ganz rechts IO8. Ist entsprechend eine 1 gesetzt 
war ein High am Signal angelegt, bei einer 0 entsprechend ein Low.

Beispiel Aufruf: g\* (IO1 - IO8 zu einem Zeitpunkt abfragen)
Beispiel Antwort: 10001000 (IO1 und IO5 waren high, der Rest low)

Beispiel in Python
^^^^^^^^^^^^^^^^^^

Das Paket serial für Python muss zuvor installiert werden. In Debian
reich ein einfaches _apt-get install python-serial_.

------------------------------------------------------
import serial
import time

ser = serial.Serial('/dev/ttyACM0', 19200, timeout=1)

ser.write("*")
ser.write("*dB1*")

while(1):
  ser.write("pB0*")
  time.sleep(1)
  ser.write("pB1*")
  time.sleep(1)
------------------------------------------------------

Einsatz in C#
^^^^^^^^^^^^^
-------------------------------------

using System;
using System.Collections.Generic;
using System.Text;
using System.IO.Ports;
using System.Threading;

namespace Test1 {
    class Program {	
        static void Main(string[] args) {			
		// open comport: name (COM16) depends on your system
		SerialPort USBProg = new SerialPort("COM16", 9600, 
						Parity.None, 8, StopBits.One);
		USBProg.Open();
			
		//set direction of Pin 11 (B)
		USBProg.Write("dB1*");

		char[] buffer = new char[255];
		for (int i = 0; i < 5; i++) {
			//disable LED
			USBProg.Write("pB0*");
			Console.Write("Answer: ");
			Console.WriteLine(USBProg.ReadExisting());
			Thread.Sleep(500);
			//enable LED
			USBProg.Write("pB1*");
			//sensorStream.Read(buffer,0,2);
			Console.Write("Answer: ");
			Console.WriteLine(USBProg.ReadExisting());
			Thread.Sleep(500);
		}
		//close comport
		USBProg.Close();
			
		//keep console open
		Console.Read();
        }
    }
} 
-------------------------------------

TDB

USB-zu-RS232-Wandler
~~~~~~~~~~~~~~~~~~~~

Mit dieser Firmware kann man USBprog als einfachen RS232-Wandler in allen bekannten Betriebssystemen nutzen. 
Er arbeitet mit den Standardtreibern vom Betriebssystem. 

Um ein RS232-Gerät ansteuern zu können, muss man sich nur einen Adapter von JP2 auf einen entsprechenden Stecker (evtl. 9 polig SUB-D) bauen. 

Status
^^^^^^

* Mit einer festeingestellten Baudrate (fest in der Firmware) von 9600 8N1 getestet und einsatzfähig unter Linux und Windows XP.
* Dass man zwischen verschiedenen Baudraten hin- und herschalten kann ist nicht mehr viel Aufwand. Wenn das jemand dringend braucht, schreibt einfach eine Mail, dann kann ich das dann schnell machen.

Linux
^^^^^
cdc-acm als Modul oder fest im Kernel (`/dev/ttyACMx`)

MacOS
^^^^^
Das Gerät sollte als `/dev/cu.usbmodem***` erscheinen. Mit MacOS wurde noch nicht getestet, aber es sollte eigentlich funktionieren. Ansonsten bitte als Bug im Forum oder per E-Mail melden!

AT89 Programmer
~~~~~~~~~~~~~~~

Mit der at89prog-Firmware kann mit dem USBprog-Adapter der AT89S8252 programmiert, gelöscht und zurückgesetzt werden. 
Falls Bedarf an anderen Controllern der AT89-Familie besteht, bitte melden! Zu der Firmware gibt 
es ein kleines Konsolenprogramm, über das man den Adapter ansteuern kann. Wie dies genau zu verwenden ist, 
ist in dem Abschnitt "Hilfe für at89prog" beschrieben.

Status
^^^^^^

Die Firmware wurde mit dem AT89S8252 auf Windows und Linux erfolgreich
getestet.  Da es noch wenig Feedback von Benutzern gibt, kann der aktuelle
Status als "Beta-Status" bezeichnet werden.  Aktuell kann man mit der Firmware
eine .bin-Datei in den Flashspeicher übertragen, den Flash löschen und den AT89
zurücksetzen. Bei Bedarf an weiteren Funktionen einfach melden.  Die Struktur
steht, d. h. alles andere sollte schnell programmiert sein.

*GNU/Linux*

* Programm löschen: `./at89prog -e`
* Programm herunterladen: `./at89prog -u /home/user/test1.BIN`
* CPU Reset: `./at89prog -r`

*Windows*
* Programm löschen `at89prog.exe -e`
* Programm heraufladen `at89prog.exe -u c:\test1.BIN`
* CPU Reset: `at89prog.exe -r`

JTAG-Adapter
~~~~~~~~~~~~

Der universale JTAG-Adapter dient als Basis für die JTAG-Kommunikation. Die Bibliothek für den USB-JTAG-Adapter kann einfach in andere Projekte integriert werden. 

----------------------------------------------------------------------------------------------------------------
/* low level functions */
  void usbprog_jtag_read_tdo(struct usbprog_jtag *usbprog_jtag, char * buffer, int size);
  void usbprog_jtag_write_tdi(struct usbprog_jtag *usbprog_jtag, char * buffer, int size);
  void usbprog_jtag_write_and_read(struct usbprog_jtag *usbprog_jtag, char * buffer, int size);
  void usbprog_jtag_write_tms(struct usbprog_jtag *usbprog_jtag, char tms_scan);
  
/* single io function! An emulated JTAG connection is very slow!!! */
  void usbprog_jtag_set_direction(struct usbprog_jtag *usbprog_jtag, unsigned char direction);
  void usbprog_jtag_write_slice(struct usbprog_jtag *usbprog_jtag, unsigned char value);
  unsigned char usbprog_jtag_get_port(struct usbprog_jtag *usbprog_jtag);
  void usbprog_jtag_set_bit(struct usbprog_jtag *usbprog_jtag, int bit, int value);
  int usbprog_jtag_get_bit(struct usbprog_jtag *usbprog_jtag, int bit);

/* basic jtag tap functions */
  void usbprog_jtag_tap_goto_reset(struct usbprog_jtag *usbprog_jtag);
  void usbprog_jtag_tap_goto_capture_dr(struct usbprog_jtag *usbprog_jtag);
  void usbprog_jtag_tap_goto_capture_ir(struct usbprog_jtag *usbprog_jtag);
  
  void usbprog_jtag_tap_shift_register(struct usbprog_jtag *usbprog_jtag, char * in, char *out, int size);
----------------------------------------------------------------------------------------------------------------

XSVF-Player (Xilinx CPLDs und FPGAs programmieren)
~~~~~~~~~~~~~~~~~~~~~~~~~~~~~~~~~~~~~~~~~~~~~~~~~~

XSVF-Dateien stellen ein standardisiertes Format dar, um prinzipiell beliebige JTAG-Operationen zu beschreiben. Mit dieser Firmware für USBprog ist es möglich, solche XSVF-Dateien "abzuspielen", d. h. die enthaltenen JTAG-Operationen über den USBprog-Adapter auszuführen. Damit kann man beispielsweise CPLDs, FPGAs oder Mikrocontroller mit JTAG-Schnittstelle programmieren, löschen, testen usw. Voraussetzung dafür ist, dass man eine Software hat, die entsprechende XSVF-Dateien für das Target-Device erstellen kann.

*Status*

Der XSVF-Player funktioniert für den Fall, dass keine einzelne XSVF-Instruktion länger als 64 Bytes ist. Getestet wurde unter Linux (openSUSE 10.3 x86_64, Debian Sarge) mit einem Xilinx XC9572 CPLD sowie mit einem XC9572XL CPLD.

Anschlussbelegung 
^^^^^^^^^^^^^^^^^

. TDI
. VCC
. leer
. leer
. TMS
. leer
. TCK
. leer
. TDO
. GND

XSVF-Player unter Linux
^^^^^^^^^^^^^^^^^^^^^^^

Quelltextarchiv herunterladen mit Subversion:

--------------------------------------------------------------------------
svn checkout http://svn.berlios.de/svnroot/repos/usbprog/trunk/usbprogXSVF
--------------------------------------------------------------------------

Kommandozeilen-Tool kompilieren:

--------------------------------------------------------------------------
cd lib
make
--------------------------------------------------------------------------

Benutzung:

--------------------------------------------------------------------------
./xsvfplayer <XSVF-Dateiname>
--------------------------------------------------------------------------

XSVF-Dateien erstellen mit Xilinx ISE 9.2i WebPack
^^^^^^^^^^^^^^^^^^^^^^^^^^^^^^^^^^^^^^^^^^^^^^^^^^

Um XSVF-Dateien zu erstellen, mit denen ein Xilinx CPLD oder FPGA konfiguriert werden kann, kann man folgendermaßen vorgehen:

In der ISE-Projektansicht die Top-Entity auswählen und dann "Implement Design" → "Optional Implementation Tools" → "Generate SVF/XSVF/STAPL File" ausführen. Es öffnet sich ein neues Fenster, dort "Prepare a Boundary-Scan File" aktivieren und als Format "XSVF" auswählen. Auf "Finish" klicken. Dann der zu erzeugenden XSVF-Datei einen Namen geben und im nächsten Fenster "OK" klicken. In dem sich danach öffnenden Fenster ("Add Device") die Datei mit gleichem Namen wie die Top-Entity und Endung .jed im Projektordner auswählen. Anschließend im Hauptfenster Rechtsklick auf das CPLD- oder FPGA-Symbol in der JTAG-Chain und auf "Program" klicken, mit "Ok" bestätigen. Zum Schluss auf "Output" → "XSVF File" → "Stop Writing to XSVF File" und fertig ist das XSVF.

Alternativ zum "Program"-Schritt kann man natürlich auch beliebige andere JTAG-Operationen ausführen und in der XSVF-Datei aufzeichnen.

Interessante und hilfreiche Linkadressen:

* http://www.ethernut.de/en/xsvfexec/index.html[Fertige Routinen]
* http://www.xilinx.com/bvdocs/appnotes/xapp058.pdf[Beschreibung des XSVF Formats]
* http://www.xilinx.com/bvdocs/publications/ds300.pdf[Platform Cable USB]

Logik Analsator (250 kHz, 8 Signale, Trigger)
~~~~~~~~~~~~~~~~~~~~~~~~~~~~~~~~~~~~~~~~~~~~~

* 8 Kanäle
* Online-Modus (Daten werden direkt während der Messung übertragen)
* Speicher-Modus (es werden intern bis zu 1000 Messungen aufgezeichnet)
* Snapshot-Modus (für langsame gezielte Aufzeichnungen z. B. Counter, Logiktests, etc.)
* einstellbare Abtastrate von 5 μs bis 100 ms (max. 250 kHz)
* einstellbare Trigger (Flanke an einer Leitung, Muster auf allen Leitungen)
* einfache Konsolenanwendung zum Aufzeichnen für Linux und Windows
* als Ausgabeformat werden vcd-Dateien erzeugt. Diese kann man mit vielen Tools bearbeiten, z. B. GTKWave)

.GTKWave
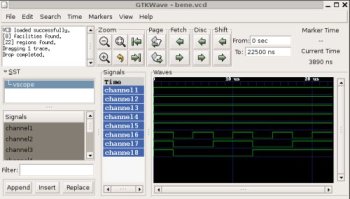
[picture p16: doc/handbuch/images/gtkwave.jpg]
GTKWave


Das Gerät wurde nicht als Profi-Logikanalysator, sondern für einfache und relativ langsame Messungen (bis 250 kHz) geplant. Interessant ist dieses Gerät für Bastler, die gerne mit kleinen Mikrocontrollern arbeiten und ab und an gerne in eine UART, SPI oder I2C Verbindung schauen möchte, oder einfach nur für Versuche oder den Schulunterricht.

Das Projekt besteht aus drei Teilen:

. Der _Hardware,_ die Bestandteil dieses Projektes ist (die Pläne dazu stehen im Downloadbereich zur Verfügung).
. Dem Programm _logic2vcd,_ um Messungen auf dem Gerät zu starten und zu steuern (gehört ebenfalls zu diesem Projekt). Dieses Programm erzeugt sogenannte .vcd-Dateien.
. _GTKWave,_ das zum Analysieren analysiert werden kann. GTKWave ist nicht Bestandteil dieses Projektes aber ebenfalls ein Open-Source-Projekt. Beide Programme gibt es für Linux und Windows.

Status
^^^^^^

Der Logikadapter wurde ausgiebig getestet. Bis jetzt sind keine Fehler bekannt. Da ihn aber noch einfach zu wenige getestet haben würde ich ihn als Beta einstufen

Anschlussbelegung
^^^^^^^^^^^^^^^^^

. Kanal 6
. VCC
. Kanal 5
. Kanal 4
. Kanal 1
. Kanal 3
. Kanal 8
. Kanal 2
. Kanal 7
. GND

Links
^^^^^

GTKWave: http://home.nc.rr.com/gtkwave[Homepage], http://www.dspia.com/gtkwave.html[Download].

Aufzeichnung von Messungen mit logic2vcd
^^^^^^^^^^^^^^^^^^^^^^^^^^^^^^^^^^^^^^^^

Das Programm logic2vcd dient der Steuerung der Messung mit Hilfe der Hardware. Man startet das Programm mit den entsprechenden Kommandozeilenargumenten, und bekommt als Resultat eine .vcd-Datei. Dieses Format kommt aus der Hardware-Entwicklung. Es dient normalerweise dazu um Logikschaltungen nach einer Simulation analysieren zu können. Der Vorteil dieses Dateiformates ist, dass es bereits einige Programme zum be- und verarbeiten gibt (u. a. GTKWave).

Einfache Online Messung:

-----------------------------------------------------
./logic2vcd -f messung.vcd -R online -s 1ms -n 1000
-----------------------------------------------------

Im Detail bedeutet dies:
----------------------------------------------------------------------
    -f Name der Datei in die die Werte geschrieben werden sollen
    -R (Recordtype) Aufnahmemodus = online
    -s Abtastrate (jede Millisekunde wird ein neuer Wert gelesen )
    -n Anzahl der Messungen
----------------------------------------------------------------------

Bei der Online-Messung werden so schnell wie möglich die Daten von der Hardware abgeholt, so dass es im Analysator zu keinem Stau kommt. Kommt es jedoch zwischenzeitlich zu kurzen Unterbrechungen, gehen Messdaten verloren. Dieses passiert bei hohen Abtastraten häufiger. Wenn es um hundertprozentige Genauigkeit geht, muss man auf den sogenannten internen Modus wechseln (siehe unten).

Online Messung mit Start-Trigger:

Bei der einfachen Messung beginnt die Aufzeichnung mit dem Starten des Kommandos. Da man so jedoch schwer den Bereich erwischt, den man wirklich aufzeichnen möchte, kann man einen Start-Trigger definieren. Erst wenn das Signal - wie im Trigger definiert - erkannt wird, beginnt die Aufzeichnung mit den entsprechenden Parametern.

------------------------------------------------------------------------
./logic2vcd -f messung.vcd -R online -s 1ms -n 1000 -T edge -c 1 -t 1
------------------------------------------------------------------------

Im Detail bedeutet dies:

----------------------------------------------------------------------------------------------
    -T Art des Triggers, entweder kann man die Flanke eines Kanals beobachten (edge)
        oder man kann den ganzen Port mit einem Muster vergleichen (pattern)
    -c Kanalnummer (1-8) funktioniert nur beim Edge-Trigger
    -t Der zu vergleichende Wert
        * bei Edge=1 für einen Übergang von low - high und eine 0 für high - low
        * bei Pattern das Hexmuster für den Port, wenn port 1,2 und 8 high sein sollen,
          dann muss als Wert 193 (Hex: C1, Binär: 1100 0001) angegeben werden
    -i  Wenn man bestimmte Kanäle beim Pattern Trigger ignorieren will, kann man
        diese hier angeben, genau gleich wie bei -t. Wenn man Kanal 1-4
        ignorieren möchte, muss man entsprechend 240 (Hex: 0xf0 und Binär 11110000) angeben.
----------------------------------------------------------------------------------------------

Die restlichen Parameter steuern wie auch bei der einfachen Messung die Aufzeichnung, die ab der erkannten Triggerbedingung startet.

Genauere interne Messung mit Start-Trigger: 

Im internen Modus werden maximal 1000 Messwerte in der Hardware aufgezeichnet. Danach stoppt die Messung und man kann die Messwerte abholen. 1000 Messwerte ist nicht gerade viel, aber dank der Trigger kann man sich gut an die entsprechenden Stelle in der Messung hinarbeiten.

Datenanalyse mit GTKWave
^^^^^^^^^^^^^^^^^^^^^^^^

Mit GTKWave kann man einfach Messungen analysieren. Gestartet wird das Programm direkt mit dem Dateinamen der Messung als Argument:

----------------------------
gtkwave messung.vcd
----------------------------

Als erstes muss auf vscope geklickt werden, um die Kanäle im Feld _Signals_ einzublenden. Anschließend kann man alle Kanäle maskieren, und muss sie dann nur noch einfügen. Wenn man oben auf die Lupe klickt wird die komplette Messung in dem Fenster angezeigt. Jetzt kann man sich mit den restlichen Knöpfen an die entsprechende Stelle hinarbeiten. 

Eigene Firmware entwickeln
--------------------------

Hier soll gezeigt werden, wie eigene Firmwares entwickelt werden können.

Schritt für Schritt 
~~~~~~~~~~~~~~~~~~~

. Herunterladen `skeleton`
. entpacken

USBprog für Entwickler
~~~~~~~~~~~~~~~~~~~~~~

Alle Quelltexte befinden sich im Versionsverwaltungssystem _Subversion_ bei Berlios. Berlios bietet für Open-Source Anwendungen eine Entwicklerplattform an.

Anonymous SVN Access via SVN

This project's BerliOS Developer SVN repository can be checked out through anonymous (svnserve) SVN with the following instruction set.

---------------------------------------------------------------------
svn checkout svn://svn.berlios.de/usbprog/trunk
---------------------------------------------------------------------

Anonymous SVN Access via HTTP

This project's BerliOS Developer SVN repository can be checked out through anonymous HTTP with the following instruction set.

---------------------------------------------------------------------
svn checkout http://svn.berlios.de/svnroot/repos/usbprog/trunk
---------------------------------------------------------------------

Developer SVN Access via SSH

Only project developers can access the SVN tree via this method. SSH2 must be installed on your client machine. Substitute developername with the proper value. Enter your site password when prompted.

---------------------------------------------------------------------
svn checkout \
svn+ssh://developername@svn.berlios.de/svnroot/repos/usbprog/trunk
---------------------------------------------------------------------

Developer SVN Access via HTTPS

Only project developers can access the SVN tree via this method. Substitute developername with the proper value. Enter your site password when prompted.

---------------------------------------------------------------------
svn checkout \
https://developername@svn.berlios.de/svnroot/repos/usbprog/trunk 
---------------------------------------------------------------------

Appendix A: Schaltplan
----------------------

Zu beachten ist, dass es zwei Platinen gibt. Die sogenannte Version 2.0 und 3.0. Alle Firmwares sind auf beiden 
einsetzbar. Der größte Unterschied ist, dass auf der Version 3.0 an der 10-poligen Buchse der komplette 
Port B anliegt. Die Reihenfolge der Pins ist leider etwas durcheinander, aber das ist dafür das er eben kompatibel 
zur Version 2.0 ist. Damit müssen wir wohl lange leben müssen. Mir ist klar, dass das nicht sehr schön ist, aber es 
ist fair den Leuten gegenüber, die Version 2.0 haben.

.Schaltplan USBprog 3.0
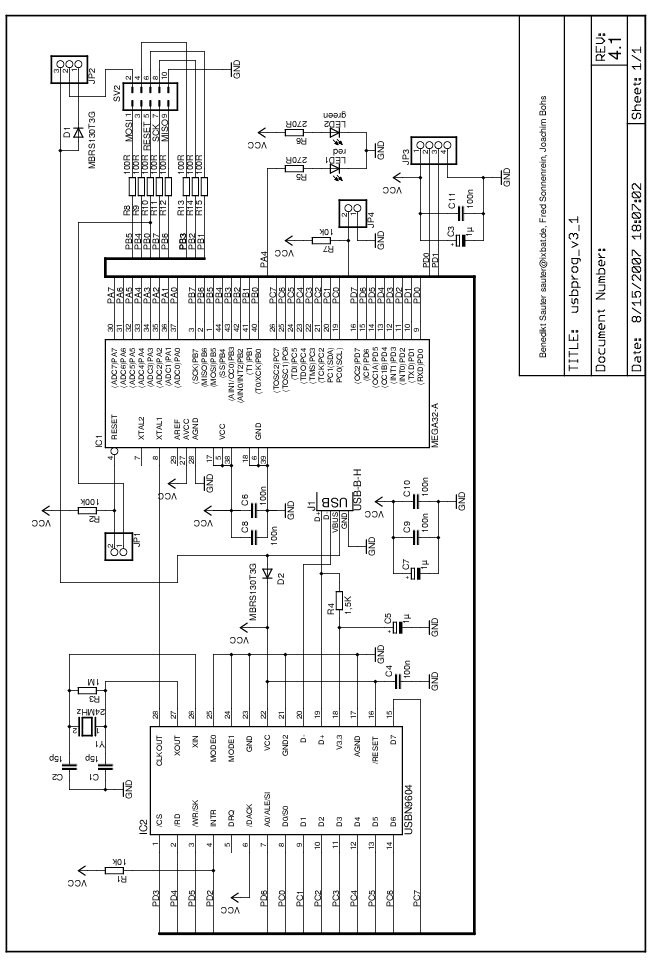
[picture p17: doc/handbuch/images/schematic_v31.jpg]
Schaltplan


Appendix B: Lizenzen
----------------------

Im folgenden sind die Lizenzen für alle Quelltexte rund um USBprog
und die Dokumentationen mit abgedruckt.

-----------------------------------------------------------------------------
                    GNU GENERAL PUBLIC LICENSE
                       Version 3, 29 June 2007

 Copyright (C) 2007 Free Software Foundation, Inc. <http://fsf.org/>
 Everyone is permitted to copy and distribute verbatim copies
 of this license document, but changing it is not allowed.

                            Preamble

  The GNU General Public License is a free, copyleft license for
software and other kinds of works.

  The licenses for most software and other practical works are designed
to take away your freedom to share and change the works.  By contrast,
the GNU General Public License is intended to guarantee your freedom to
share and change all versions of a program--to make sure it remains free
software for all its users.  We, the Free Software Foundation, use the
GNU General Public License for most of our software; it applies also to
any other work released this way by its authors.  You can apply it to
your programs, too.

  When we speak of free software, we are referring to freedom, not
price.  Our General Public Licenses are designed to make sure that you
have the freedom to distribute copies of free software (and charge for
them if you wish), that you receive source code or can get it if you
want it, that you can change the software or use pieces of it in new
free programs, and that you know you can do these things.

  To protect your rights, we need to prevent others from denying you
these rights or asking you to surrender the rights.  Therefore, you have
certain responsibilities if you distribute copies of the software, or if
you modify it: responsibilities to respect the freedom of others.

  For example, if you distribute copies of such a program, whether
gratis or for a fee, you must pass on to the recipients the same
freedoms that you received.  You must make sure that they, too, receive
or can get the source code.  And you must show them these terms so they
know their rights.

  Developers that use the GNU GPL protect your rights with two steps:
(1) assert copyright on the software, and (2) offer you this License
giving you legal permission to copy, distribute and/or modify it.

  For the developers' and authors' protection, the GPL clearly explains
that there is no warranty for this free software.  For both users' and
authors' sake, the GPL requires that modified versions be marked as
changed, so that their problems will not be attributed erroneously to
authors of previous versions.

  Some devices are designed to deny users access to install or run
modified versions of the software inside them, although the manufacturer
can do so.  This is fundamentally incompatible with the aim of
protecting users' freedom to change the software.  The systematic
pattern of such abuse occurs in the area of products for individuals to
use, which is precisely where it is most unacceptable.  Therefore, we
have designed this version of the GPL to prohibit the practice for those
products.  If such problems arise substantially in other domains, we
stand ready to extend this provision to those domains in future versions
of the GPL, as needed to protect the freedom of users.

  Finally, every program is threatened constantly by software patents.
States should not allow patents to restrict development and use of
software on general-purpose computers, but in those that do, we wish to
avoid the special danger that patents applied to a free program could
make it effectively proprietary.  To prevent this, the GPL assures that
patents cannot be used to render the program non-free.

  The precise terms and conditions for copying, distribution and
modification follow.

                       TERMS AND CONDITIONS

  0. Definitions.

  "This License" refers to version 3 of the GNU General Public License.

  "Copyright" also means copyright-like laws that apply to other kinds of
works, such as semiconductor masks.

  "The Program" refers to any copyrightable work licensed under this
License.  Each licensee is addressed as "you".  "Licensees" and
"recipients" may be individuals or organizations.

  To "modify" a work means to copy from or adapt all or part of the work
in a fashion requiring copyright permission, other than the making of an
exact copy.  The resulting work is called a "modified version" of the
earlier work or a work "based on" the earlier work.

  A "covered work" means either the unmodified Program or a work based
on the Program.

  To "propagate" a work means to do anything with it that, without
permission, would make you directly or secondarily liable for
infringement under applicable copyright law, except executing it on a
computer or modifying a private copy.  Propagation includes copying,
distribution (with or without modification), making available to the
public, and in some countries other activities as well.

  To "convey" a work means any kind of propagation that enables other
parties to make or receive copies.  Mere interaction with a user through
a computer network, with no transfer of a copy, is not conveying.

  An interactive user interface displays "Appropriate Legal Notices"
to the extent that it includes a convenient and prominently visible
feature that (1) displays an appropriate copyright notice, and (2)
tells the user that there is no warranty for the work (except to the
extent that warranties are provided), that licensees may convey the
work under this License, and how to view a copy of this License.  If
the interface presents a list of user commands or options, such as a
menu, a prominent item in the list meets this criterion.

  1. Source Code.

  The "source code" for a work means the preferred form of the work
for making modifications to it.  "Object code" means any non-source
form of a work.

  A "Standard Interface" means an interface that either is an official
standard defined by a recognized standards body, or, in the case of
interfaces specified for a particular programming language, one that
is widely used among developers working in that language.

  The "System Libraries" of an executable work include anything, other
than the work as a whole, that (a) is included in the normal form of
packaging a Major Component, but which is not part of that Major
Component, and (b) serves only to enable use of the work with that
Major Component, or to implement a Standard Interface for which an
implementation is available to the public in source code form.  A
"Major Component", in this context, means a major essential component
(kernel, window system, and so on) of the specific operating system
(if any) on which the executable work runs, or a compiler used to
produce the work, or an object code interpreter used to run it.

  The "Corresponding Source" for a work in object code form means all
the source code needed to generate, install, and (for an executable
work) run the object code and to modify the work, including scripts to
control those activities.  However, it does not include the work's
System Libraries, or general-purpose tools or generally available free
programs which are used unmodified in performing those activities but
which are not part of the work.  For example, Corresponding Source
includes interface definition files associated with source files for
the work, and the source code for shared libraries and dynamically
linked subprograms that the work is specifically designed to require,
such as by intimate data communication or control flow between those
subprograms and other parts of the work.

  The Corresponding Source need not include anything that users
can regenerate automatically from other parts of the Corresponding
Source.

  The Corresponding Source for a work in source code form is that
same work.

  2. Basic Permissions.

  All rights granted under this License are granted for the term of
copyright on the Program, and are irrevocable provided the stated
conditions are met.  This License explicitly affirms your unlimited
permission to run the unmodified Program.  The output from running a
covered work is covered by this License only if the output, given its
content, constitutes a covered work.  This License acknowledges your
rights of fair use or other equivalent, as provided by copyright law.

  You may make, run and propagate covered works that you do not
convey, without conditions so long as your license otherwise remains
in force.  You may convey covered works to others for the sole purpose
of having them make modifications exclusively for you, or provide you
with facilities for running those works, provided that you comply with
the terms of this License in conveying all material for which you do
not control copyright.  Those thus making or running the covered works
for you must do so exclusively on your behalf, under your direction
and control, on terms that prohibit them from making any copies of
your copyrighted material outside their relationship with you.

  Conveying under any other circumstances is permitted solely under
the conditions stated below.  Sublicensing is not allowed; section 10
makes it unnecessary.

  3. Protecting Users' Legal Rights From Anti-Circumvention Law.

  No covered work shall be deemed part of an effective technological
measure under any applicable law fulfilling obligations under article
11 of the WIPO copyright treaty adopted on 20 December 1996, or
similar laws prohibiting or restricting circumvention of such
measures.

  When you convey a covered work, you waive any legal power to forbid
circumvention of technological measures to the extent such circumvention
is effected by exercising rights under this License with respect to
the covered work, and you disclaim any intention to limit operation or
modification of the work as a means of enforcing, against the work's
users, your or third parties' legal rights to forbid circumvention of
technological measures.

  4. Conveying Verbatim Copies.

  You may convey verbatim copies of the Program's source code as you
receive it, in any medium, provided that you conspicuously and
appropriately publish on each copy an appropriate copyright notice;
keep intact all notices stating that this License and any
non-permissive terms added in accord with section 7 apply to the code;
keep intact all notices of the absence of any warranty; and give all
recipients a copy of this License along with the Program.

  You may charge any price or no price for each copy that you convey,
and you may offer support or warranty protection for a fee.

  5. Conveying Modified Source Versions.

  You may convey a work based on the Program, or the modifications to
produce it from the Program, in the form of source code under the
terms of section 4, provided that you also meet all of these conditions:

    a) The work must carry prominent notices stating that you modified
    it, and giving a relevant date.

    b) The work must carry prominent notices stating that it is
    released under this License and any conditions added under section
    7.  This requirement modifies the requirement in section 4 to
    "keep intact all notices".

    c) You must license the entire work, as a whole, under this
    License to anyone who comes into possession of a copy.  This
    License will therefore apply, along with any applicable section 7
    additional terms, to the whole of the work, and all its parts,
    regardless of how they are packaged.  This License gives no
    permission to license the work in any other way, but it does not
    invalidate such permission if you have separately received it.

    d) If the work has interactive user interfaces, each must display
    Appropriate Legal Notices; however, if the Program has interactive
    interfaces that do not display Appropriate Legal Notices, your
    work need not make them do so.

  A compilation of a covered work with other separate and independent
works, which are not by their nature extensions of the covered work,
and which are not combined with it such as to form a larger program,
in or on a volume of a storage or distribution medium, is called an
"aggregate" if the compilation and its resulting copyright are not
used to limit the access or legal rights of the compilation's users
beyond what the individual works permit.  Inclusion of a covered work
in an aggregate does not cause this License to apply to the other
parts of the aggregate.

  6. Conveying Non-Source Forms.

  You may convey a covered work in object code form under the terms
of sections 4 and 5, provided that you also convey the
machine-readable Corresponding Source under the terms of this License,
in one of these ways:

    a) Convey the object code in, or embodied in, a physical product
    (including a physical distribution medium), accompanied by the
    Corresponding Source fixed on a durable physical medium
    customarily used for software interchange.

    b) Convey the object code in, or embodied in, a physical product
    (including a physical distribution medium), accompanied by a
    written offer, valid for at least three years and valid for as
    long as you offer spare parts or customer support for that product
    model, to give anyone who possesses the object code either (1) a
    copy of the Corresponding Source for all the software in the
    product that is covered by this License, on a durable physical
    medium customarily used for software interchange, for a price no
    more than your reasonable cost of physically performing this
    conveying of source, or (2) access to copy the
    Corresponding Source from a network server at no charge.

    c) Convey individual copies of the object code with a copy of the
    written offer to provide the Corresponding Source.  This
    alternative is allowed only occasionally and noncommercially, and
    only if you received the object code with such an offer, in accord
    with subsection 6b.

    d) Convey the object code by offering access from a designated
    place (gratis or for a charge), and offer equivalent access to the
    Corresponding Source in the same way through the same place at no
    further charge.  You need not require recipients to copy the
    Corresponding Source along with the object code.  If the place to
    copy the object code is a network server, the Corresponding Source
    may be on a different server (operated by you or a third party)
    that supports equivalent copying facilities, provided you maintain
    clear directions next to the object code saying where to find the
    Corresponding Source.  Regardless of what server hosts the
    Corresponding Source, you remain obligated to ensure that it is
    available for as long as needed to satisfy these requirements.

    e) Convey the object code using peer-to-peer transmission, provided
    you inform other peers where the object code and Corresponding
    Source of the work are being offered to the general public at no
    charge under subsection 6d.

  A separable portion of the object code, whose source code is excluded
from the Corresponding Source as a System Library, need not be
included in conveying the object code work.

  A "User Product" is either (1) a "consumer product", which means any
tangible personal property which is normally used for personal, family,
or household purposes, or (2) anything designed or sold for incorporation
into a dwelling.  In determining whether a product is a consumer product,
doubtful cases shall be resolved in favor of coverage.  For a particular
product received by a particular user, "normally used" refers to a
typical or common use of that class of product, regardless of the status
of the particular user or of the way in which the particular user
actually uses, or expects or is expected to use, the product.  A product
is a consumer product regardless of whether the product has substantial
commercial, industrial or non-consumer uses, unless such uses represent
the only significant mode of use of the product.

  "Installation Information" for a User Product means any methods,
procedures, authorization keys, or other information required to install
and execute modified versions of a covered work in that User Product from
a modified version of its Corresponding Source.  The information must
suffice to ensure that the continued functioning of the modified object
code is in no case prevented or interfered with solely because
modification has been made.

  If you convey an object code work under this section in, or with, or
specifically for use in, a User Product, and the conveying occurs as
part of a transaction in which the right of possession and use of the
User Product is transferred to the recipient in perpetuity or for a
fixed term (regardless of how the transaction is characterized), the
Corresponding Source conveyed under this section must be accompanied
by the Installation Information.  But this requirement does not apply
if neither you nor any third party retains the ability to install
modified object code on the User Product (for example, the work has
been installed in ROM).

  The requirement to provide Installation Information does not include a
requirement to continue to provide support service, warranty, or updates
for a work that has been modified or installed by the recipient, or for
the User Product in which it has been modified or installed.  Access to a
network may be denied when the modification itself materially and
adversely affects the operation of the network or violates the rules and
protocols for communication across the network.

  Corresponding Source conveyed, and Installation Information provided,
in accord with this section must be in a format that is publicly
documented (and with an implementation available to the public in
source code form), and must require no special password or key for
unpacking, reading or copying.

  7. Additional Terms.

  "Additional permissions" are terms that supplement the terms of this
License by making exceptions from one or more of its conditions.
Additional permissions that are applicable to the entire Program shall
be treated as though they were included in this License, to the extent
that they are valid under applicable law.  If additional permissions
apply only to part of the Program, that part may be used separately
under those permissions, but the entire Program remains governed by
this License without regard to the additional permissions.

  When you convey a copy of a covered work, you may at your option
remove any additional permissions from that copy, or from any part of
it.  (Additional permissions may be written to require their own
removal in certain cases when you modify the work.)  You may place
additional permissions on material, added by you to a covered work,
for which you have or can give appropriate copyright permission.

  Notwithstanding any other provision of this License, for material you
add to a covered work, you may (if authorized by the copyright holders of
that material) supplement the terms of this License with terms:

    a) Disclaiming warranty or limiting liability differently from the
    terms of sections 15 and 16 of this License; or

    b) Requiring preservation of specified reasonable legal notices or
    author attributions in that material or in the Appropriate Legal
    Notices displayed by works containing it; or

    c) Prohibiting misrepresentation of the origin of that material, or
    requiring that modified versions of such material be marked in
    reasonable ways as different from the original version; or

    d) Limiting the use for publicity purposes of names of licensors or
    authors of the material; or

    e) Declining to grant rights under trademark law for use of some
    trade names, trademarks, or service marks; or

    f) Requiring indemnification of licensors and authors of that
    material by anyone who conveys the material (or modified versions of
    it) with contractual assumptions of liability to the recipient, for
    any liability that these contractual assumptions directly impose on
    those licensors and authors.

  All other non-permissive additional terms are considered "further
restrictions" within the meaning of section 10.  If the Program as you
received it, or any part of it, contains a notice stating that it is
governed by this License along with a term that is a further
restriction, you may remove that term.  If a license document contains
a further restriction but permits relicensing or conveying under this
License, you may add to a covered work material governed by the terms
of that license document, provided that the further restriction does
not survive such relicensing or conveying.

  If you add terms to a covered work in accord with this section, you
must place, in the relevant source files, a statement of the
additional terms that apply to those files, or a notice indicating
where to find the applicable terms.

  Additional terms, permissive or non-permissive, may be stated in the
form of a separately written license, or stated as exceptions;
the above requirements apply either way.

  8. Termination.

  You may not propagate or modify a covered work except as expressly
provided under this License.  Any attempt otherwise to propagate or
modify it is void, and will automatically terminate your rights under
this License (including any patent licenses granted under the third
paragraph of section 11).

  However, if you cease all violation of this License, then your
license from a particular copyright holder is reinstated (a)
provisionally, unless and until the copyright holder explicitly and
finally terminates your license, and (b) permanently, if the copyright
holder fails to notify you of the violation by some reasonable means
prior to 60 days after the cessation.

  Moreover, your license from a particular copyright holder is
reinstated permanently if the copyright holder notifies you of the
violation by some reasonable means, this is the first time you have
received notice of violation of this License (for any work) from that
copyright holder, and you cure the violation prior to 30 days after
your receipt of the notice.

  Termination of your rights under this section does not terminate the
licenses of parties who have received copies or rights from you under
this License.  If your rights have been terminated and not permanently
reinstated, you do not qualify to receive new licenses for the same
material under section 10.

  9. Acceptance Not Required for Having Copies.

  You are not required to accept this License in order to receive or
run a copy of the Program.  Ancillary propagation of a covered work
occurring solely as a consequence of using peer-to-peer transmission
to receive a copy likewise does not require acceptance.  However,
nothing other than this License grants you permission to propagate or
modify any covered work.  These actions infringe copyright if you do
not accept this License.  Therefore, by modifying or propagating a
covered work, you indicate your acceptance of this License to do so.

  10. Automatic Licensing of Downstream Recipients.

  Each time you convey a covered work, the recipient automatically
receives a license from the original licensors, to run, modify and
propagate that work, subject to this License.  You are not responsible
for enforcing compliance by third parties with this License.

  An "entity transaction" is a transaction transferring control of an
organization, or substantially all assets of one, or subdividing an
organization, or merging organizations.  If propagation of a covered
work results from an entity transaction, each party to that
transaction who receives a copy of the work also receives whatever
licenses to the work the party's predecessor in interest had or could
give under the previous paragraph, plus a right to possession of the
Corresponding Source of the work from the predecessor in interest, if
the predecessor has it or can get it with reasonable efforts.

  You may not impose any further restrictions on the exercise of the
rights granted or affirmed under this License.  For example, you may
not impose a license fee, royalty, or other charge for exercise of
rights granted under this License, and you may not initiate litigation
(including a cross-claim or counterclaim in a lawsuit) alleging that
any patent claim is infringed by making, using, selling, offering for
sale, or importing the Program or any portion of it.

  11. Patents.

  A "contributor" is a copyright holder who authorizes use under this
License of the Program or a work on which the Program is based.  The
work thus licensed is called the contributor's "contributor version".

  A contributor's "essential patent claims" are all patent claims
owned or controlled by the contributor, whether already acquired or
hereafter acquired, that would be infringed by some manner, permitted
by this License, of making, using, or selling its contributor version,
but do not include claims that would be infringed only as a
consequence of further modification of the contributor version.  For
purposes of this definition, "control" includes the right to grant
patent sublicenses in a manner consistent with the requirements of
this License.

  Each contributor grants you a non-exclusive, worldwide, royalty-free
patent license under the contributor's essential patent claims, to
make, use, sell, offer for sale, import and otherwise run, modify and
propagate the contents of its contributor version.

  In the following three paragraphs, a "patent license" is any express
agreement or commitment, however denominated, not to enforce a patent
(such as an express permission to practice a patent or covenant not to
sue for patent infringement).  To "grant" such a patent license to a
party means to make such an agreement or commitment not to enforce a
patent against the party.

  If you convey a covered work, knowingly relying on a patent license,
and the Corresponding Source of the work is not available for anyone
to copy, free of charge and under the terms of this License, through a
publicly available network server or other readily accessible means,
then you must either (1) cause the Corresponding Source to be so
available, or (2) arrange to deprive yourself of the benefit of the
patent license for this particular work, or (3) arrange, in a manner
consistent with the requirements of this License, to extend the patent
license to downstream recipients.  "Knowingly relying" means you have
actual knowledge that, but for the patent license, your conveying the
covered work in a country, or your recipient's use of the covered work
in a country, would infringe one or more identifiable patents in that
country that you have reason to believe are valid.

  If, pursuant to or in connection with a single transaction or
arrangement, you convey, or propagate by procuring conveyance of, a
covered work, and grant a patent license to some of the parties
receiving the covered work authorizing them to use, propagate, modify
or convey a specific copy of the covered work, then the patent license
you grant is automatically extended to all recipients of the covered
work and works based on it.

  A patent license is "discriminatory" if it does not include within
the scope of its coverage, prohibits the exercise of, or is
conditioned on the non-exercise of one or more of the rights that are
specifically granted under this License.  You may not convey a covered
work if you are a party to an arrangement with a third party that is
in the business of distributing software, under which you make payment
to the third party based on the extent of your activity of conveying
the work, and under which the third party grants, to any of the
parties who would receive the covered work from you, a discriminatory
patent license (a) in connection with copies of the covered work
conveyed by you (or copies made from those copies), or (b) primarily
for and in connection with specific products or compilations that
contain the covered work, unless you entered into that arrangement,
or that patent license was granted, prior to 28 March 2007.

  Nothing in this License shall be construed as excluding or limiting
any implied license or other defenses to infringement that may
otherwise be available to you under applicable patent law.

  12. No Surrender of Others' Freedom.

  If conditions are imposed on you (whether by court order, agreement or
otherwise) that contradict the conditions of this License, they do not
excuse you from the conditions of this License.  If you cannot convey a
covered work so as to satisfy simultaneously your obligations under this
License and any other pertinent obligations, then as a consequence you may
not convey it at all.  For example, if you agree to terms that obligate you
to collect a royalty for further conveying from those to whom you convey
the Program, the only way you could satisfy both those terms and this
License would be to refrain entirely from conveying the Program.

  13. Use with the GNU Affero General Public License.

  Notwithstanding any other provision of this License, you have
permission to link or combine any covered work with a work licensed
under version 3 of the GNU Affero General Public License into a single
combined work, and to convey the resulting work.  The terms of this
License will continue to apply to the part which is the covered work,
but the special requirements of the GNU Affero General Public License,
section 13, concerning interaction through a network will apply to the
combination as such.

  14. Revised Versions of this License.

  The Free Software Foundation may publish revised and/or new versions of
the GNU General Public License from time to time.  Such new versions will
be similar in spirit to the present version, but may differ in detail to
address new problems or concerns.

  Each version is given a distinguishing version number.  If the
Program specifies that a certain numbered version of the GNU General
Public License "or any later version" applies to it, you have the
option of following the terms and conditions either of that numbered
version or of any later version published by the Free Software
Foundation.  If the Program does not specify a version number of the
GNU General Public License, you may choose any version ever published
by the Free Software Foundation.

  If the Program specifies that a proxy can decide which future
versions of the GNU General Public License can be used, that proxy's
public statement of acceptance of a version permanently authorizes you
to choose that version for the Program.

  Later license versions may give you additional or different
permissions.  However, no additional obligations are imposed on any
author or copyright holder as a result of your choosing to follow a
later version.

  15. Disclaimer of Warranty.

  THERE IS NO WARRANTY FOR THE PROGRAM, TO THE EXTENT PERMITTED BY
APPLICABLE LAW.  EXCEPT WHEN OTHERWISE STATED IN WRITING THE COPYRIGHT
HOLDERS AND/OR OTHER PARTIES PROVIDE THE PROGRAM "AS IS" WITHOUT WARRANTY
OF ANY KIND, EITHER EXPRESSED OR IMPLIED, INCLUDING, BUT NOT LIMITED TO,
THE IMPLIED WARRANTIES OF MERCHANTABILITY AND FITNESS FOR A PARTICULAR
PURPOSE.  THE ENTIRE RISK AS TO THE QUALITY AND PERFORMANCE OF THE PROGRAM
IS WITH YOU.  SHOULD THE PROGRAM PROVE DEFECTIVE, YOU ASSUME THE COST OF
ALL NECESSARY SERVICING, REPAIR OR CORRECTION.

  16. Limitation of Liability.

  IN NO EVENT UNLESS REQUIRED BY APPLICABLE LAW OR AGREED TO IN WRITING
WILL ANY COPYRIGHT HOLDER, OR ANY OTHER PARTY WHO MODIFIES AND/OR CONVEYS
THE PROGRAM AS PERMITTED ABOVE, BE LIABLE TO YOU FOR DAMAGES, INCLUDING ANY
GENERAL, SPECIAL, INCIDENTAL OR CONSEQUENTIAL DAMAGES ARISING OUT OF THE
USE OR INABILITY TO USE THE PROGRAM (INCLUDING BUT NOT LIMITED TO LOSS OF
DATA OR DATA BEING RENDERED INACCURATE OR LOSSES SUSTAINED BY YOU OR THIRD
PARTIES OR A FAILURE OF THE PROGRAM TO OPERATE WITH ANY OTHER PROGRAMS),
EVEN IF SUCH HOLDER OR OTHER PARTY HAS BEEN ADVISED OF THE POSSIBILITY OF
SUCH DAMAGES.

  17. Interpretation of Sections 15 and 16.

  If the disclaimer of warranty and limitation of liability provided
above cannot be given local legal effect according to their terms,
reviewing courts shall apply local law that most closely approximates
an absolute waiver of all civil liability in connection with the
Program, unless a warranty or assumption of liability accompanies a
copy of the Program in return for a fee.

                     END OF TERMS AND CONDITIONS

            How to Apply These Terms to Your New Programs

  If you develop a new program, and you want it to be of the greatest
possible use to the public, the best way to achieve this is to make it
free software which everyone can redistribute and change under these terms.

  To do so, attach the following notices to the program.  It is safest
to attach them to the start of each source file to most effectively
state the exclusion of warranty; and each file should have at least
the "copyright" line and a pointer to where the full notice is found.

    <one line to give the program's name and a brief idea of what it does.>
    Copyright (C) <year>  <name of author>

    This program is free software: you can redistribute it and/or modify
    it under the terms of the GNU General Public License as published by
    the Free Software Foundation, either version 3 of the License, or
    (at your option) any later version.

    This program is distributed in the hope that it will be useful,
    but WITHOUT ANY WARRANTY; without even the implied warranty of
    MERCHANTABILITY or FITNESS FOR A PARTICULAR PURPOSE.  See the
    GNU General Public License for more details.

    You should have received a copy of the GNU General Public License
    along with this program.  If not, see <http://www.gnu.org/licenses/>.

Also add information on how to contact you by electronic and paper mail.

  If the program does terminal interaction, make it output a short
notice like this when it starts in an interactive mode:

    <program>  Copyright (C) <year>  <name of author>
    This program comes with ABSOLUTELY NO WARRANTY; for details type `show w'.
    This is free software, and you are welcome to redistribute it
    under certain conditions; type `show c' for details.

The hypothetical commands `show w' and `show c' should show the appropriate
parts of the General Public License.  Of course, your program's commands
might be different; for a GUI interface, you would use an "about box".

  You should also get your employer (if you work as a programmer) or school,
if any, to sign a "copyright disclaimer" for the program, if necessary.
For more information on this, and how to apply and follow the GNU GPL, see
<http://www.gnu.org/licenses/>.

  The GNU General Public License does not permit incorporating your program
into proprietary programs.  If your program is a subroutine library, you
may consider it more useful to permit linking proprietary applications with
the library.  If this is what you want to do, use the GNU Lesser General
Public License instead of this License.  But first, please read
<http://www.gnu.org/philosophy/why-not-lgpl.html>.

-----------------------------------------------------------------------------

-----------------------------------------------------------------------------
		GNU Free Documentation License
		  Version 1.2, November 2002

 Copyright (C) 2000,2001,2002  Free Software Foundation, Inc.
     51 Franklin St, Fifth Floor, Boston, MA  02110-1301  USA
 Everyone is permitted to copy and distribute verbatim copies
 of this license document, but changing it is not allowed.

0. PREAMBLE

The purpose of this License is to make a manual, textbook, or other
functional and useful document "free" in the sense of freedom: to
assure everyone the effective freedom to copy and redistribute it,
with or without modifying it, either commercially or noncommercially.
Secondarily, this License preserves for the author and publisher a way
to get credit for their work, while not being considered responsible
for modifications made by others.

This License is a kind of "copyleft", which means that derivative
works of the document must themselves be free in the same sense.  It
complements the GNU General Public License, which is a copyleft
license designed for free software.

We have designed this License in order to use it for manuals for free
software, because free software needs free documentation: a free
program should come with manuals providing the same freedoms that the
software does.  But this License is not limited to software manuals;
it can be used for any textual work, regardless of subject matter or
whether it is published as a printed book.  We recommend this License
principally for works whose purpose is instruction or reference.
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

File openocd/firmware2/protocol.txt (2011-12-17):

USBprog JTAG Interface
======================
:Author: Benedikt Sauter
:Email: sauter@ixbat.de

Operating Mode
--------------

To get the best performance for a JTAG connection over USB its necessary to create a 
special protocol. The problem is USB transfer packets only every millisecond. 
But in a millisecond max. 1023 Bytes can be transfered (with USB 1.1). On the other 
hand to this packet oriented bus, JTAG implementations are often work with bit slices 
for a JTAG TAP. To get a optimal connection for a JTAG device over USB a special 
buffer for command packets are created. In a buffer many small operations 
can be collected , transfered to USBprog, handled from USBprog to the JTAG interfaces 
and send back a batch of responses back.

Execute JTAG commands means now, create a JTAG command buffer, fill buffers width commands, 
if buffer is full enough or its necessary the packets transfered to USBprog.
All scan results are send back in a grouped packet.

USB Interface
-------------

* Endpoint Number 2 for outgoing packets (from pc to USBprog)
* Endpoint Number 0x82 for incomung packets (from USBprog to pc)
* Vendor Requests at Endpoint Number 0 for configuration

Send- or receive packets should be max. 320 Bytes large. With
this limit USBprog reaches the best performance.

Hardware Interface
------------------

Connect TDI of USBprog to TDI of the first JTAG TAP. If you use USBprog
in a JTAG chain TDO of the first device after USBprog must connected
to the next device's TDI signal (and so on). Last TDO of the JTAG chain
must be connect to TDO of USBprog.

JTAG transfer commands
----------------------

Following commands can be used to transfer JTAG chains from OpenOCD
or another JTAG chain generator with USBprog into the target.

Packets for transfer buffer are shown in the next table. The typical
packet structure is 

-----------------------------------------------------------------
[CMD][LEN (opt.)][DATAX...0 (opt.)] -> [RESPONSE_DATAX...0 (opt.)]
-----------------------------------------------------------------

* CMD is a command from table commands 
* LEN is Byte or Bit length for a data out, in or in and out packet
* DATAX....0 data out, in or in and out Bytes
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

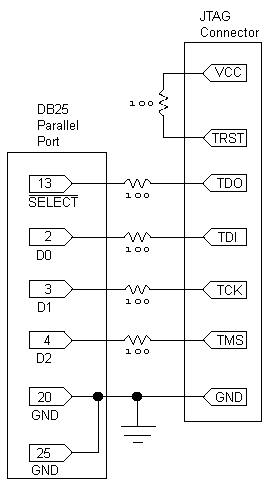
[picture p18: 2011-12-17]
usbprogJTAG/openwince/website/iPAQ-3600/images/interface.png

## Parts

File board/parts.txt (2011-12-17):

Stueckliste/Partlist usbprog

Part     Value          Device          Package      notice

C6       100n           C-EUC1206       C1206        (gelb markiert, yellow marked)
C8       15p            C-EUC1206       C1206        (blau markiert, blue marked) 
C9       15p            C-EUC1206       C1206        (blau markiert, blue marked)
C10      100n           C-EUC1206       C1206        (gelb markiert, yellow marked) 
C11      1µ             C-EUC1206       C1206        
IC1      MEGA32-A       MEGA32-A        TQFP44       
JP1      3 Pins         JP2E            JP2          
JP2      2 Pins         JP1E            JP1          jumper         1
LED1     (green)        LEDCHIP-LED0805 CHIP-LED0805 (schwarz markiert, black marked) 
LED2     (red)          LEDCHIP-LED0805 CHIP-LED0805 
M1       USBN9604       USBN9604        SO28-3       
Q1       24MHz          XTAL/S          QS          
R1       1M             R-EU_R1206      R1206        (1004) 
R2       270            R-EU_M1206      M1206        (2700) 
R3       270            R-EU_M1206      M1206        (2700)	 
R4       1,5K           R-EU_M1206      M1206        (1501) 
R5       100K           R-EU_R1206      R1206        (1003) 
R6       10k            R-EU_R1206      R1206        (1002) 
SV2                     ML10L           ML10L 
X1       USB Buchse B   PN61729         PN61729

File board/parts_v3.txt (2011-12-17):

Stueckliste/Partlist usbprog

Part     Value          Device          Package      notice

C6       100n           C-EUC1206       C1206        (gelb markiert, yellow marked)
C8       15p            C-EUC1206       C1206        (blau markiert, blue marked) 
C9       15p            C-EUC1206       C1206        (blau markiert, blue marked)
C10      100n           C-EUC1206       C1206        (gelb markiert, yellow marked) 
C11      1µ             C-EUC1206       C1206        
IC1      MEGA32-A       MEGA32-A        TQFP44       
JP1      3 Pins         JP2E            JP2          
JP2      2 Pins         JP1E            JP1          jumper         1
LED1     (green)        LEDCHIP-LED0805 CHIP-LED0805 (schwarz markiert, black marked) 
LED2     (red)          LEDCHIP-LED0805 CHIP-LED0805 
M1       USBN9604       USBN9604        SO28-3       
Q1       24MHz          XTAL/S          QS          
R1       1M             R-EU_R1206      R1206        (1004) 
R2       270            R-EU_M1206      M1206        (2700) 
R3       270            R-EU_M1206      M1206        (2700)	 
R4       1,5K           R-EU_M1206      M1206        (1501) 
R5       100K           R-EU_R1206      R1206        (1003) 
R6       10k            R-EU_R1206      R1206        (1002) 
SV2                     ML10L           ML10L 
X1       USB Buchse B   PN61729         PN61729      

> 3:TMBYV 10-40 1 0,30 0,30 Schottky 40V 1A
> MELF(SMD)

Der Typ TMBYV 10-40 hat das richtige Gehäuse für uns.

Kondensator nehmen: Best.Nr. 115-08R001 (neuen Kondensatoren)

Denk an die Dioden! Du kannst auch die MBRS120T3 von CSD
Best.Nr. 11151 verwenden (passen auch auf die Pads).

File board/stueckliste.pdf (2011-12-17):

Tabelle1

Seite 1

Item | Qty | Reference | VALUE | PCB DECAL | Part Name
1 | 1 | SV2 | WANNE_5X2_2.54MM | CON_WANNE_5X2_2.54MM | CON_HEADER5X2
2 | 1 | JP2 | Pinhead,3x1,RM2.54mm | CON_PINHEAD_3X1_2.54MM | CON_HEADER_3X1,Pinhead,3x1,RM2.54mm
3 | 1 | J1
4 | 1 | Y1 | 24MHz | Y_HC49/4HSMX | CRYSTAL_HC49SMD,24MHz
5 | 5 | C4 C6 C8-10 | 100n | 0603_C | C_KER,100n
6 | 1 | C24 | 100n | 0603_C | C_KER,100n,10%
7 | 2 | C1-2 | 15p | 0603_C | C_KER,15p
8 | 3 | C3 C5 C7 | 1u | 0603_C | C_KER,1u
9 | 1 | LED1 | LED,green | D_LED_0603 | D_LED,LED,green
10 | 1 | LED2 | LED,red | D_LED_0603 | D_LED,LED,red
11 | 2 | D1-2 | MBRS130T3G | | D_MBRS130T3G,MBRS130T3G
12 | 2 | JP1 JP4 | PINHEAD_2X1_2.54MM | CON_PINHEAD_2X1_2.54MM | HEADER_2X1
13 | 1 | JP3 | PINHEAD_4X1_2.54MM | CON_PINHEAD_4X1_2.54MM | HEADER_4X1
14 | 1 | REF1 | PASSER | PASSER_DOT_1MM | PASSER,PASSER
15 | 8 | R8-15 | 100R | 0603_R | R,100R
16 | 3 | R1-2 R7 | 10k | 0603_R | R,10k
17 | 1 | R3 | 1M | 0603_R | R,1M
18 | 1 | R4 | 1k5 | 0603_R | R,1k5
19 | 2 | R5-6 | 274R | 0603_R | R,274R,1%
20 | 1 | IC1 | ATmega32L-AU | | U_ATMEGA32-AU/MU,ATmega32L-AU
21 | 1 | IC2 | USBN9604SLB | U_USB9604SLB | U_USBN9604SLB,USBN9604SLB
Lumberg 241102 | CON_USBCON_B_LUMBERG-241102 | CON_USBCON_B_THT_LUMBERG_241102,Lumberg 241102

D_DO-214AA/SMB

U_QFP_VQ44_12X12_0.8MM

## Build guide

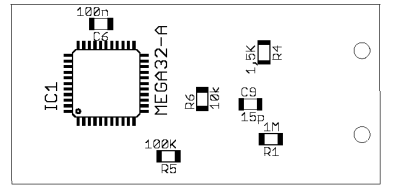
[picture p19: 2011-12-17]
board/bottom_print.png

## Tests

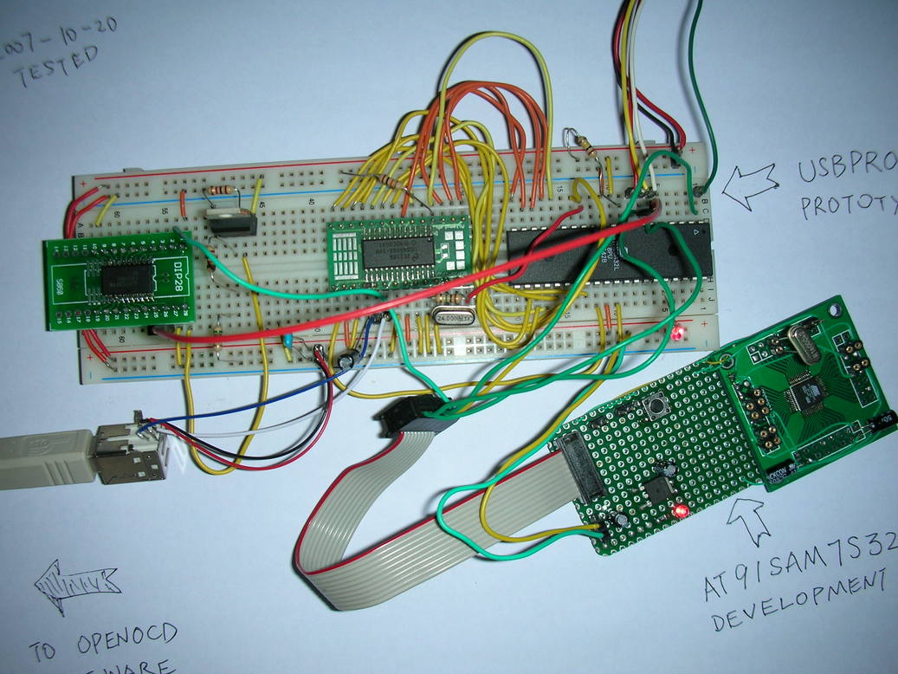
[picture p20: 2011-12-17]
misc/selfmade_usbprog/test0.jpg

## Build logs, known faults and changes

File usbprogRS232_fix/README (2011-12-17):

Read More

http://www.embedded-projects.net/index.php?page_id=160

This is a part of the project:

http://www.embedded-projects.net/usbprog

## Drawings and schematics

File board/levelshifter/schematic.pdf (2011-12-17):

A

A

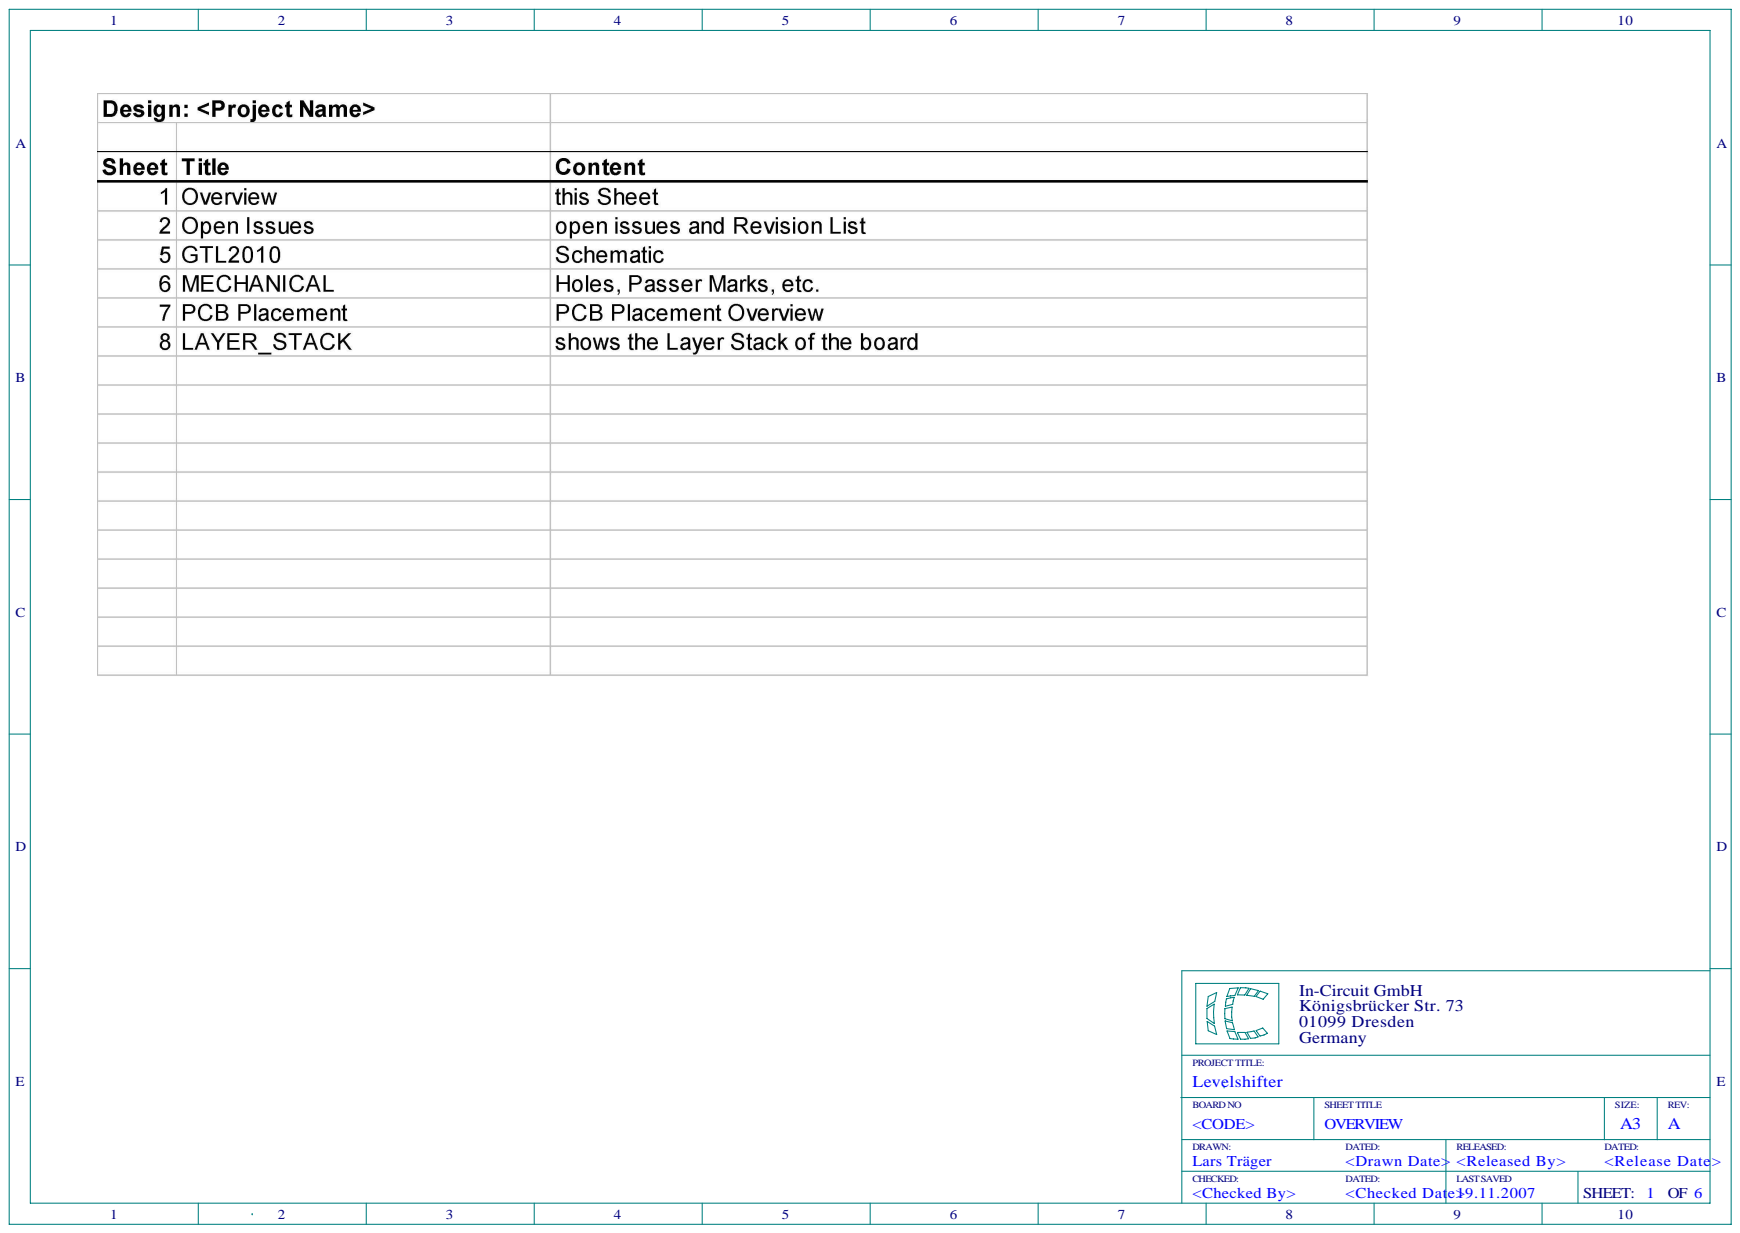
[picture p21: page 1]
Levelshifter; PROJECT TITLE:

In-Circuit GmbH
Königsbrücker Str. 73
01099 Dresden
Germany

BOARD NO <CODE> | SHEET TITLE OVERVIEW | SIZE: A3 | REV: A

DRAWN: DATED: Lars Träger <Drawn Date> <Released By> | RELEASED: DATED: <Release Date>

CHECKED: DATED: <Checked By> <Checked Date> | LAST SAVED 19.11.2007 | SHEET: OF

A

A

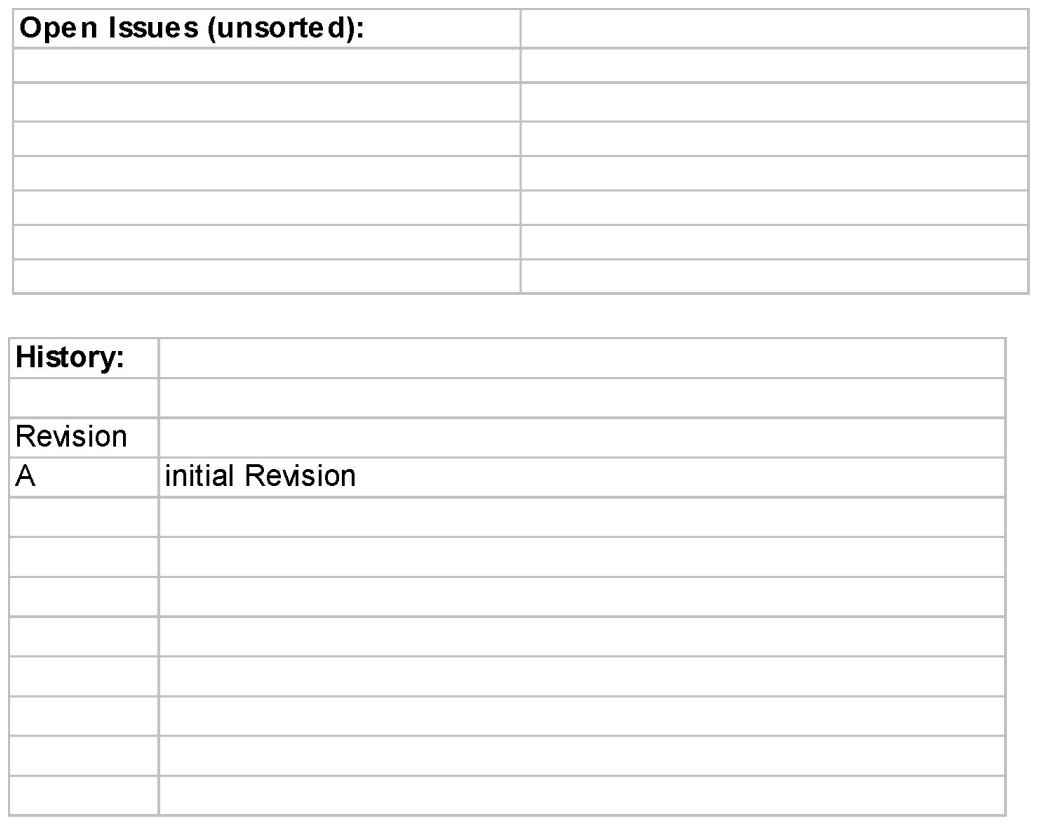
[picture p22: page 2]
Levelshifter; PROJECT TITLE:

In-Circuit GmbH
Königsbrücker Str. 73
D-01099 Dresden
Germany

BOARD NO <CODE> | SHEET TITLE OPEN_ISSUES | SIZE: A3 | REV: A

DRAWN: DATED: Lars Träger <Drawn Date> <Released By> | RELEASED: DATED: <Release Date>

A
A

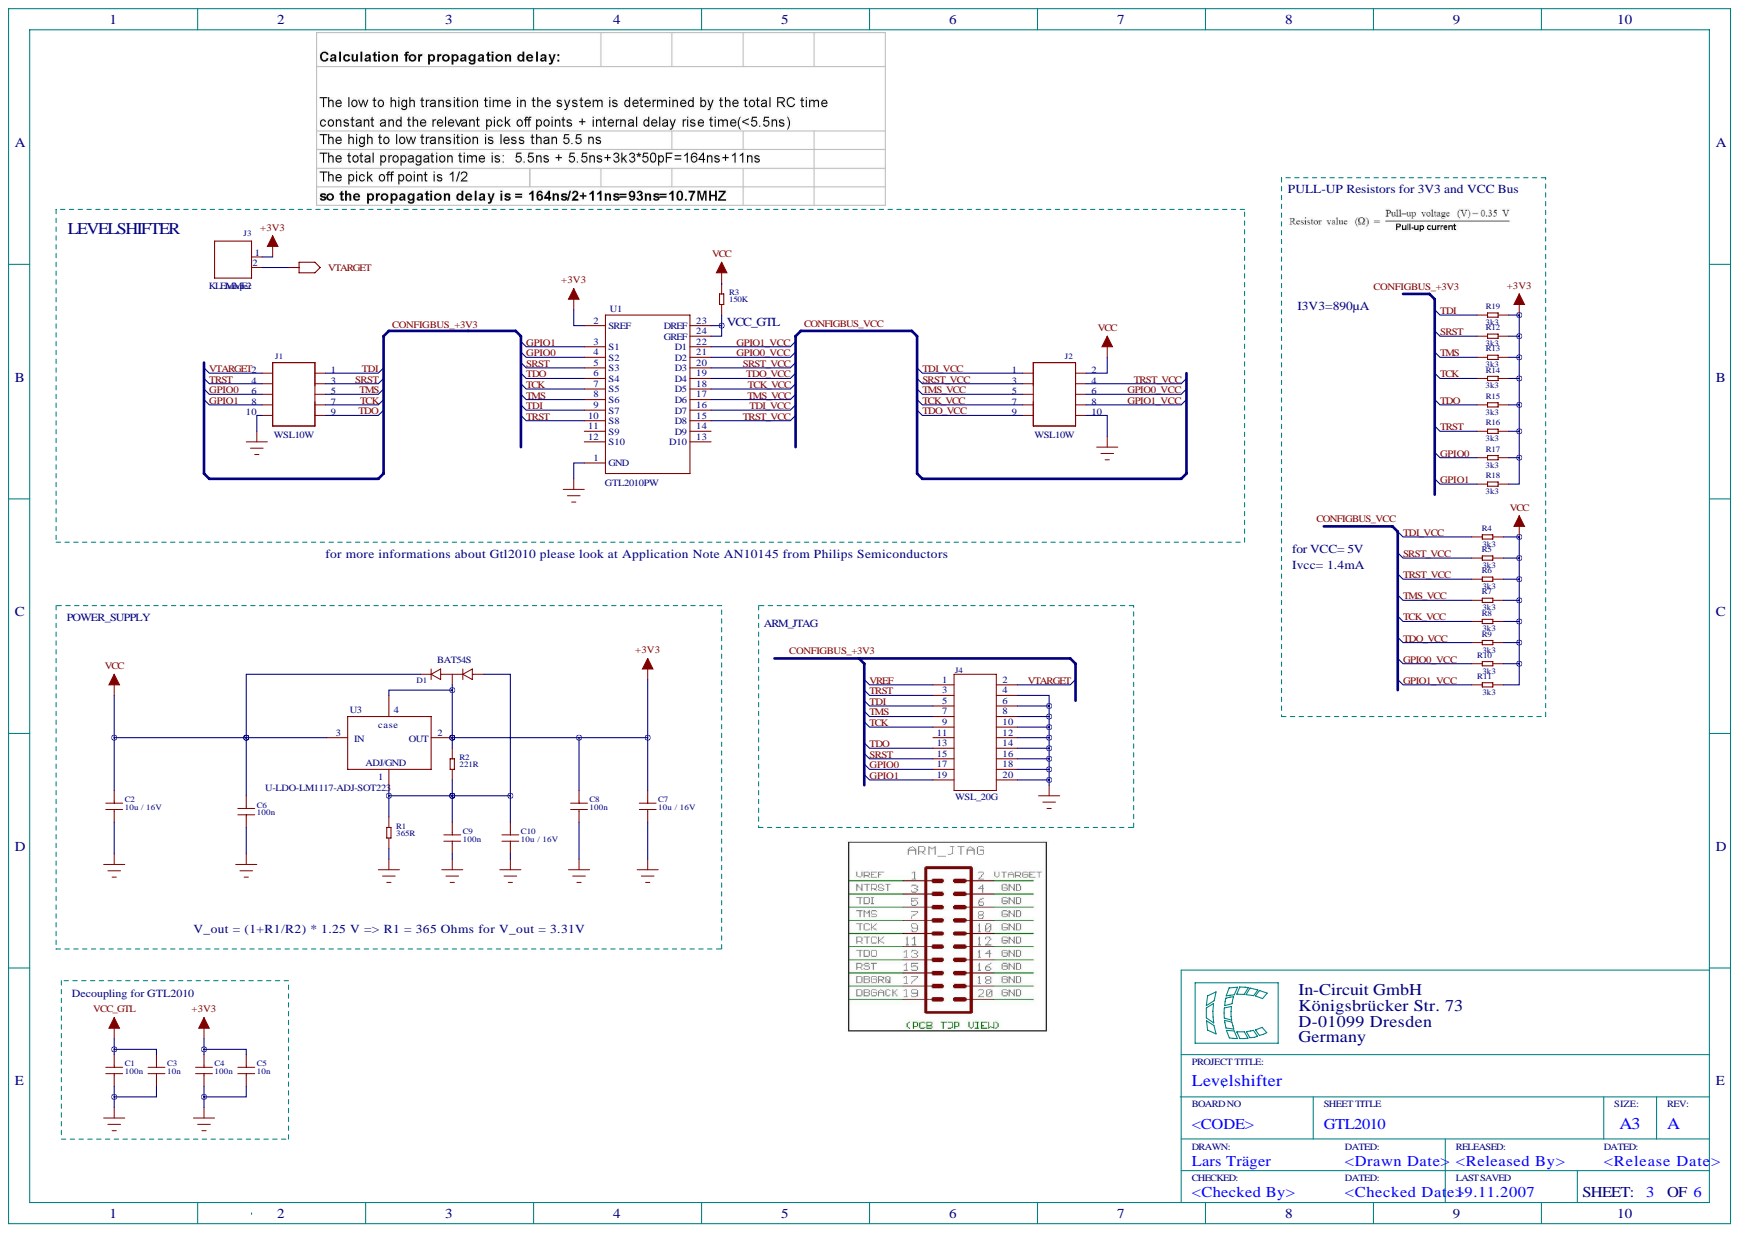
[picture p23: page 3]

PULL-UP Resistors for 3V3 and VCC Bus

Ivcc= 1.4mA for more informations about Gtl2010 please look at Application Note AN10145 from Philips Semiconductors

BOARD NO <CODE> | SHEET TITLE GTL2010 | SIZE: A3 | REV: A

DRAWN: DATED: Lars Träger <Drawn Date> <Released By> | RELEASED: DATED: <Release Date>

A

A

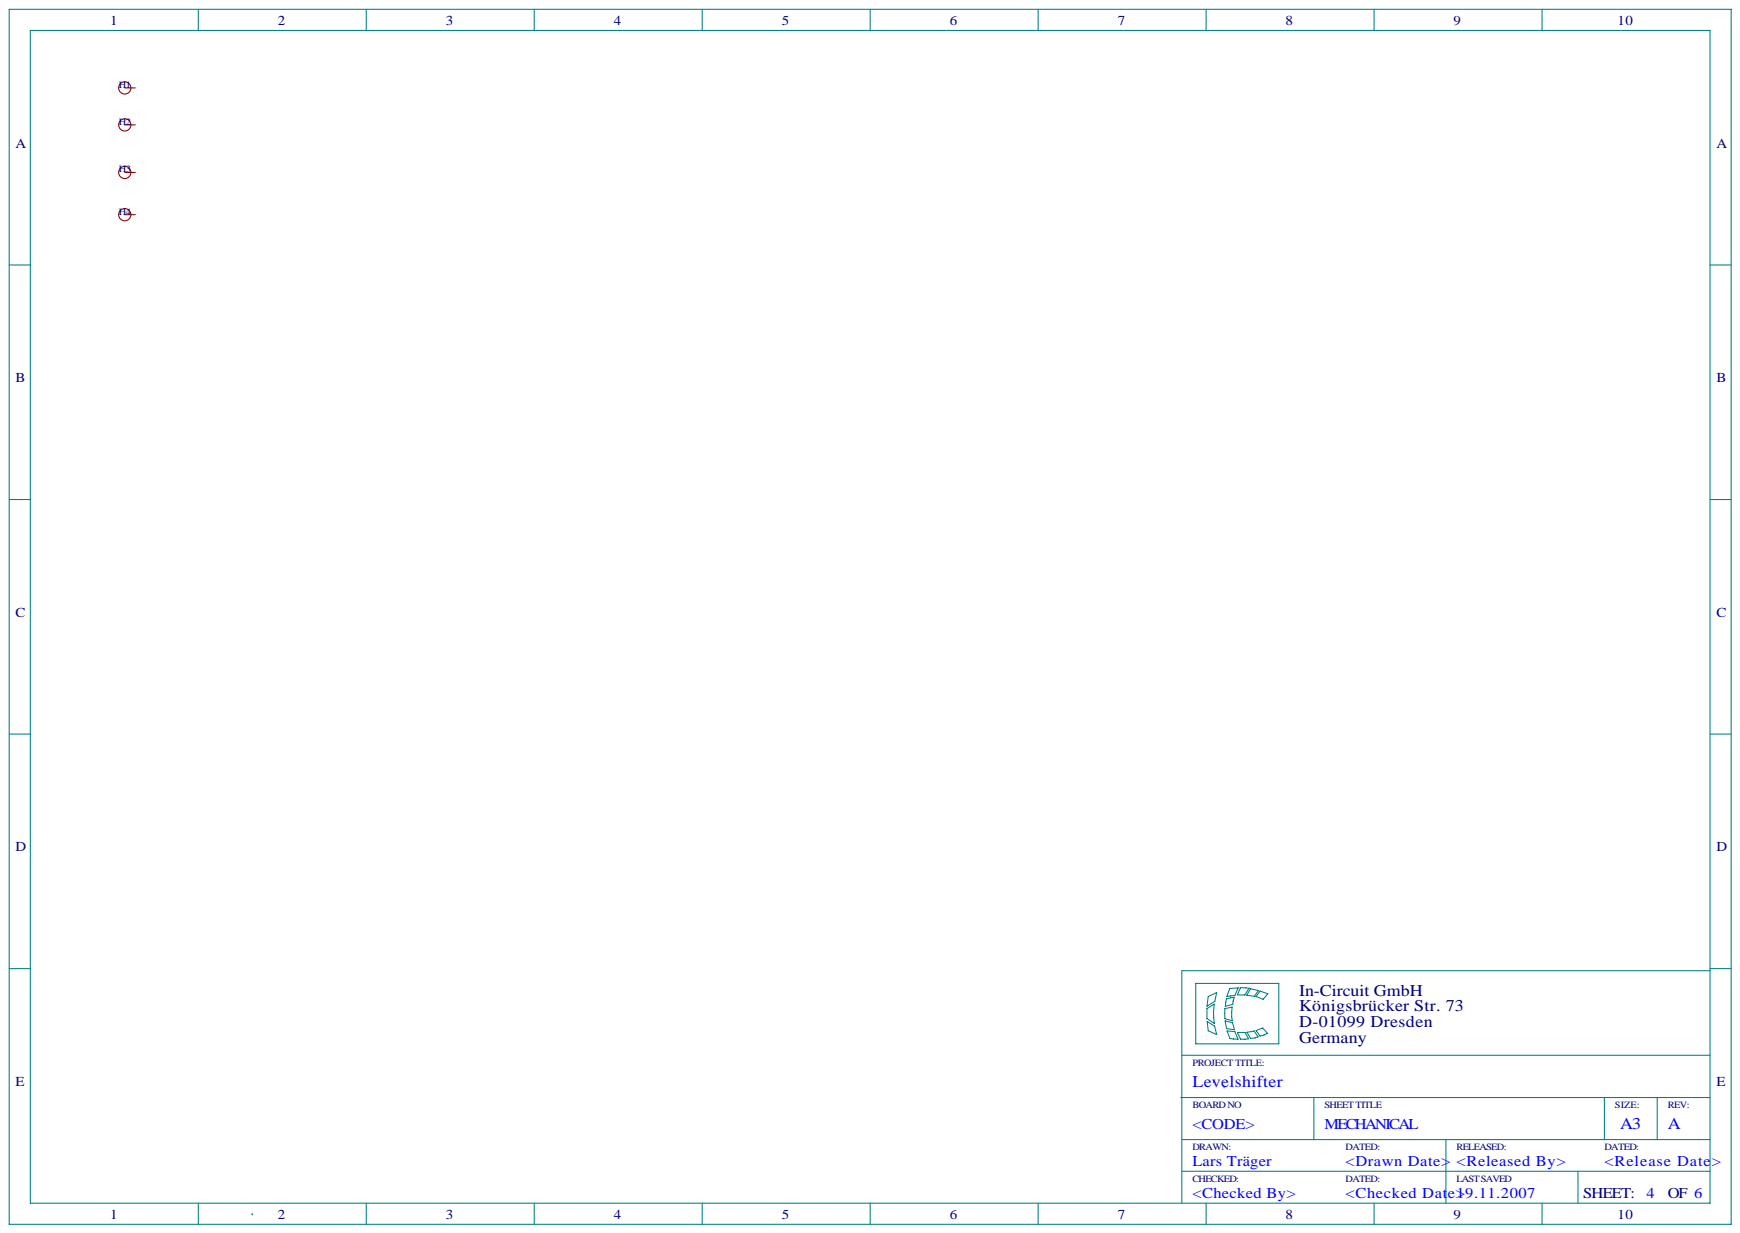
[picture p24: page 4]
Levelshifter; PROJECT TITLE:

In-Circuit GmbH
Königsbrücker Str. 73
D-01099 Dresden
Germany

BOARD NO <CODE> | SHEET TITLE MECHANICAL | SIZE: A3 | REV: A

DRAWN: DATED: Lars Träger <Drawn Date> <Released By> | RELEASED: DATED: <Release Date>

A

A

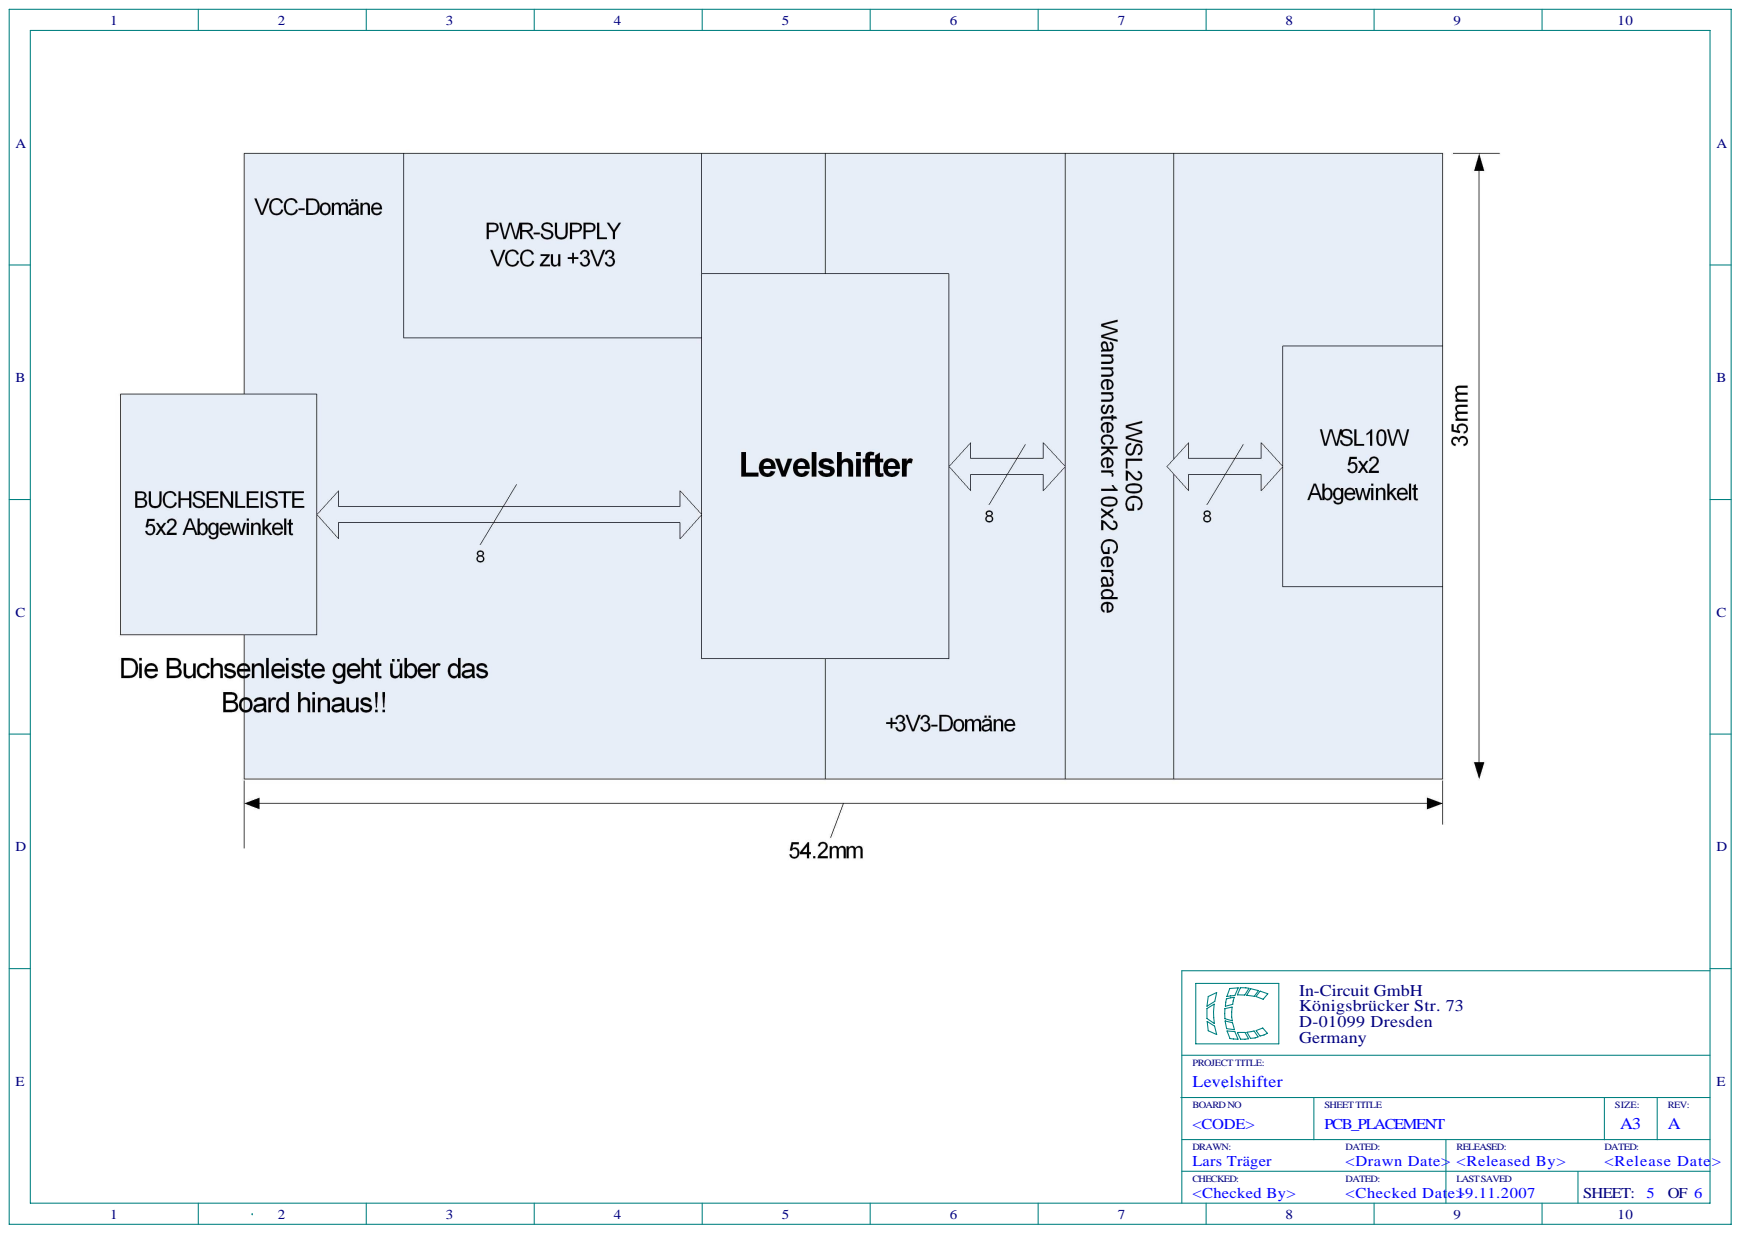
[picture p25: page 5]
Levelshifter; PROJECT TITLE:

In-Circuit GmbH
Königsbrücker Str. 73
D-01099 Dresden
Germany

BOARD NO <CODE> | SHEET TITLE PCB_PLACEMENT | SIZE: A3 | REV: A

DRAWN: DATED: Lars Träger <Drawn Date> <Released By> | RELEASED: DATED: <Release Date>

A

A

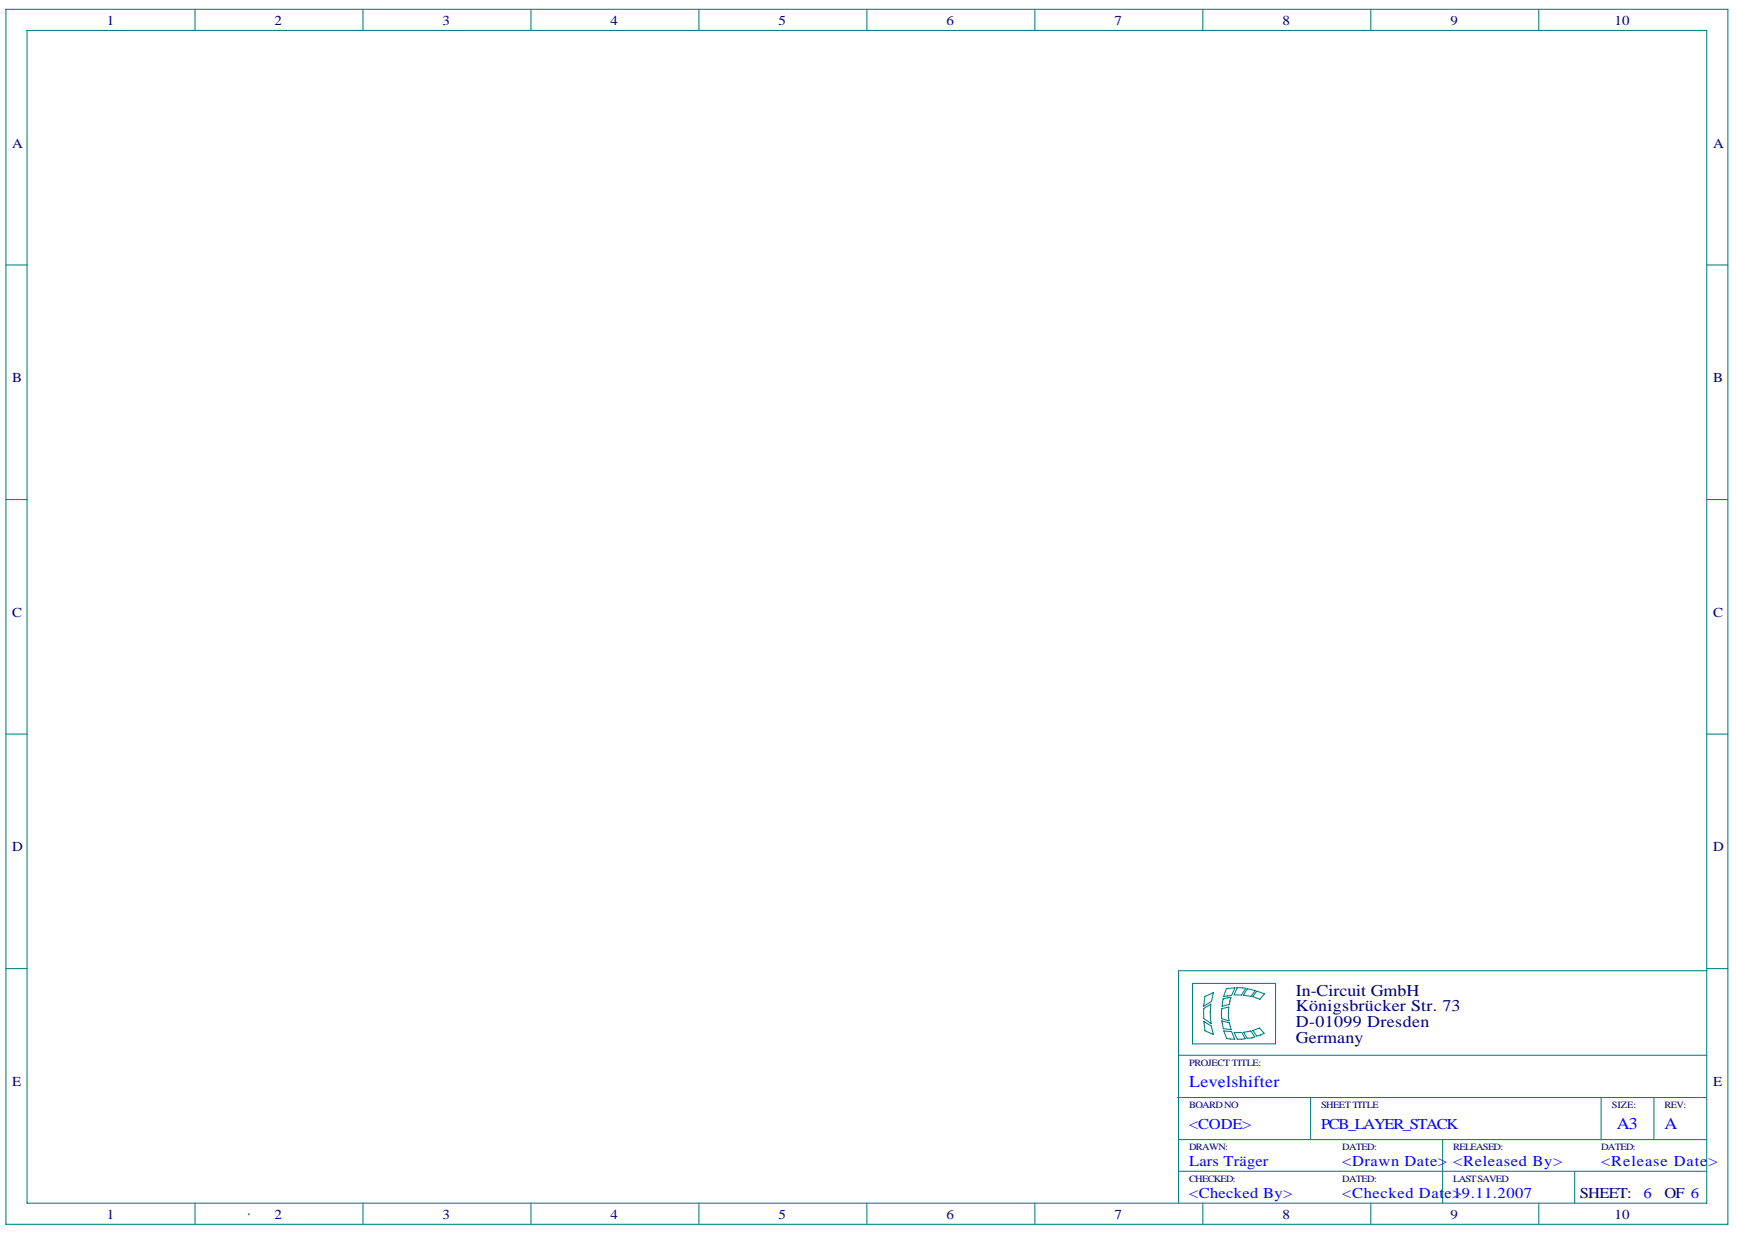
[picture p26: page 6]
Levelshifter; PROJECT TITLE:

In-Circuit GmbH
Königsbrücker Str. 73
D-01099 Dresden
Germany

BOARD NO <CODE> | SHEET TITLE PCB_LAYER_STACK | SIZE: A3 | REV: A

DRAWN: DATED: Lars Träger <Drawn Date> <Released By> | RELEASED: DATED: <Release Date>

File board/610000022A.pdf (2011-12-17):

A

A

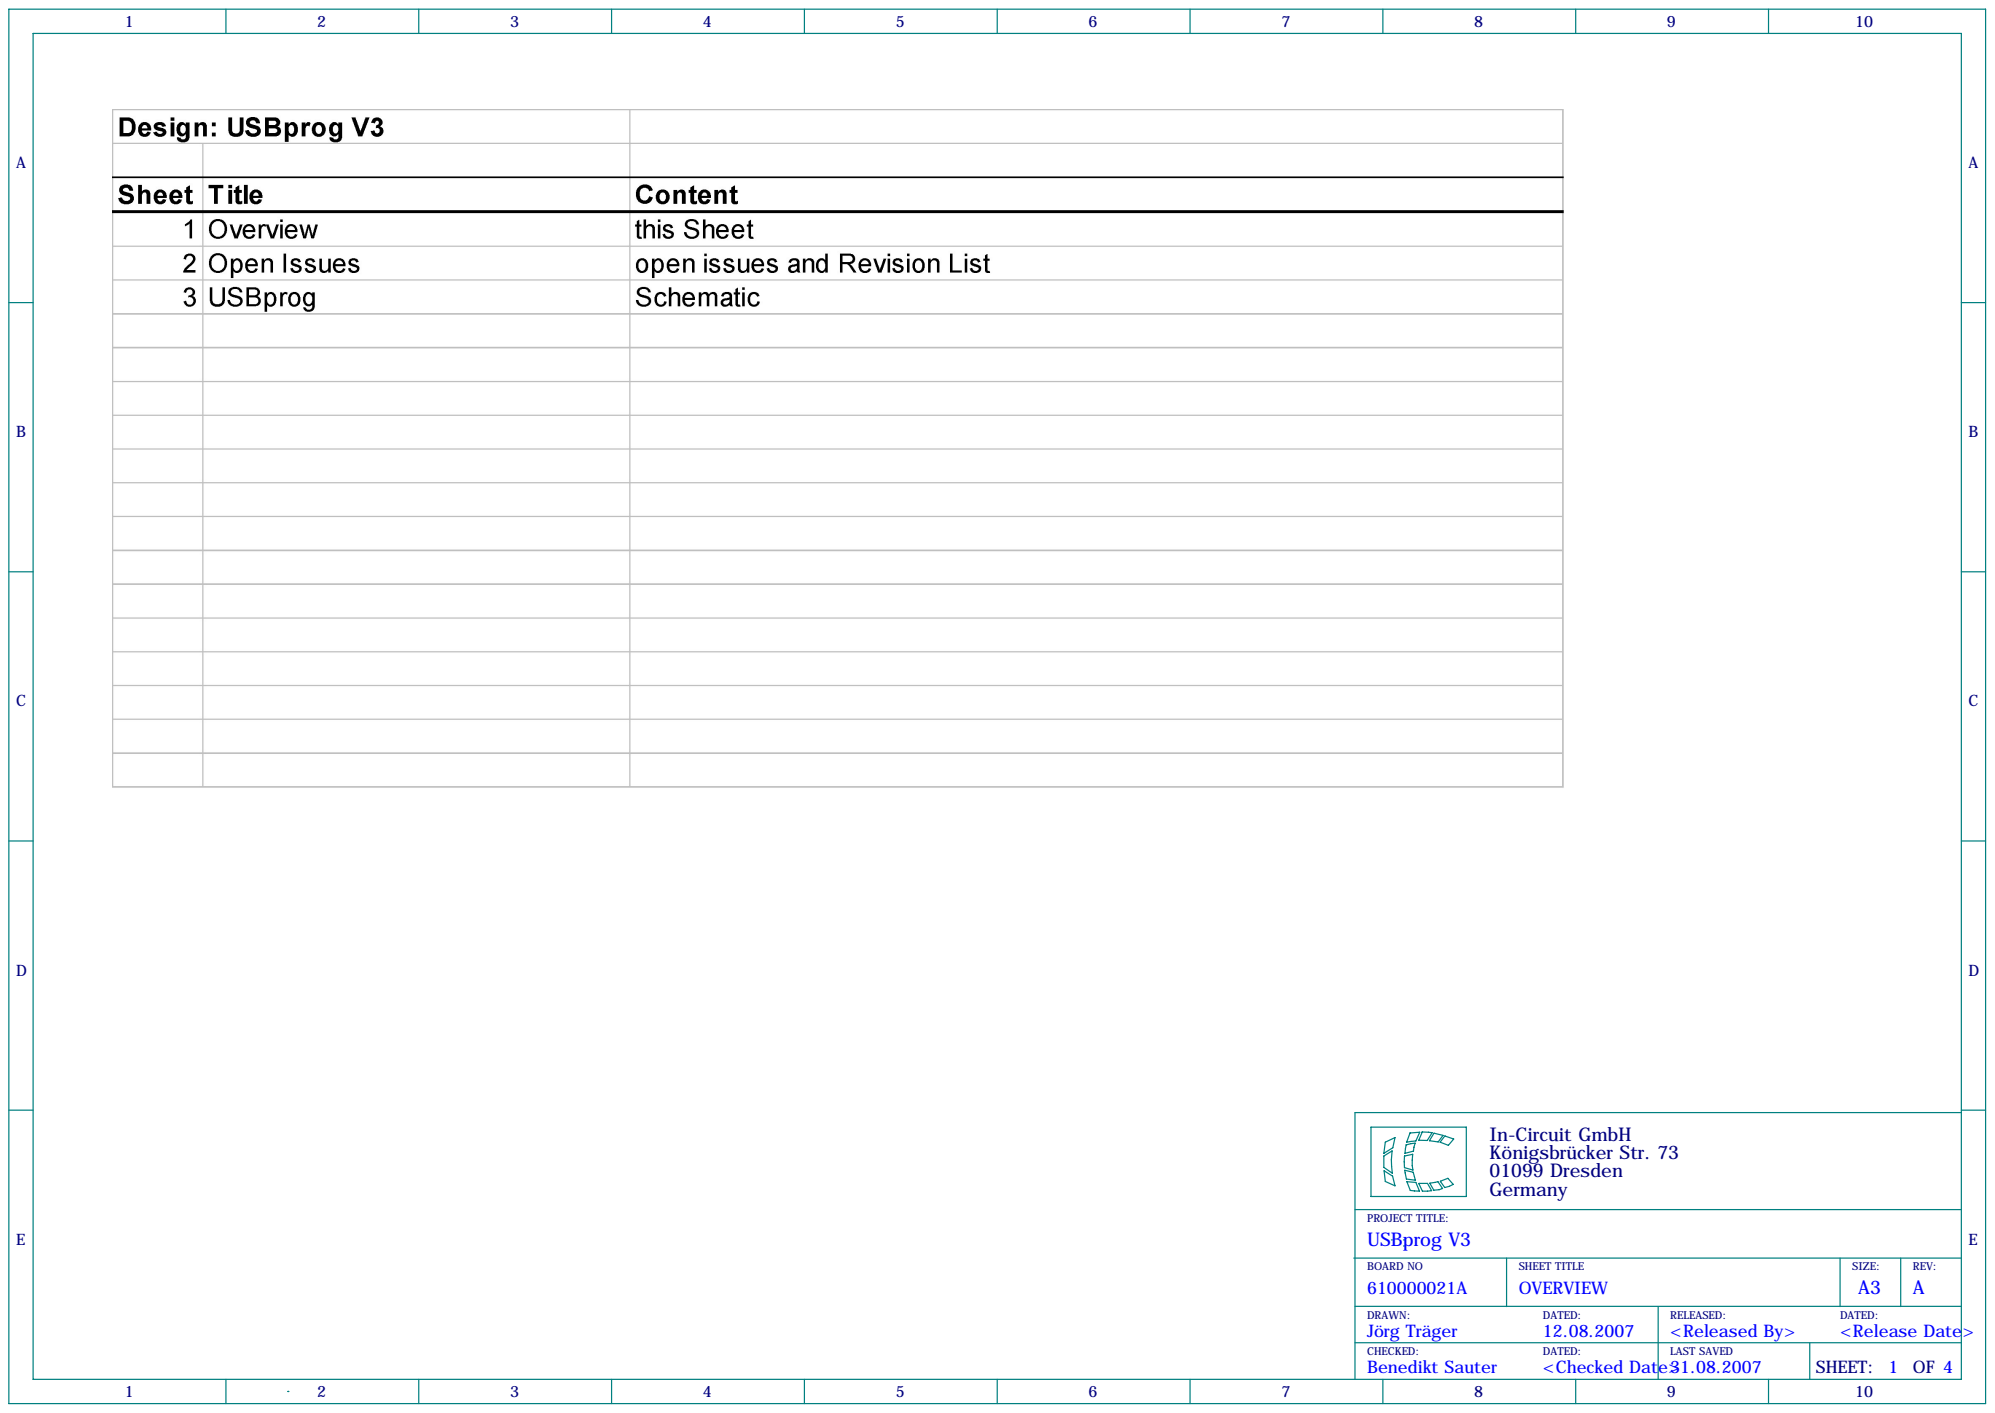
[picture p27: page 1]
USBprog V3; PROJECT TITLE:

In-Circuit GmbH
Königsbrücker Str. 73
01099 Dresden
Germany

BOARD NO 610000021A | SHEET TITLE OVERVIEW | SIZE: A3 | REV: A

DRAWN: DATED: Jörg Träger 12.08.2007 | RELEASED: DATED: <Released By> <Release Date>

CHECKED: DATED: Benedikt Sauter <Checked Date> | LAST SAVED 31.08.2007 | SHEET: OF

A

A

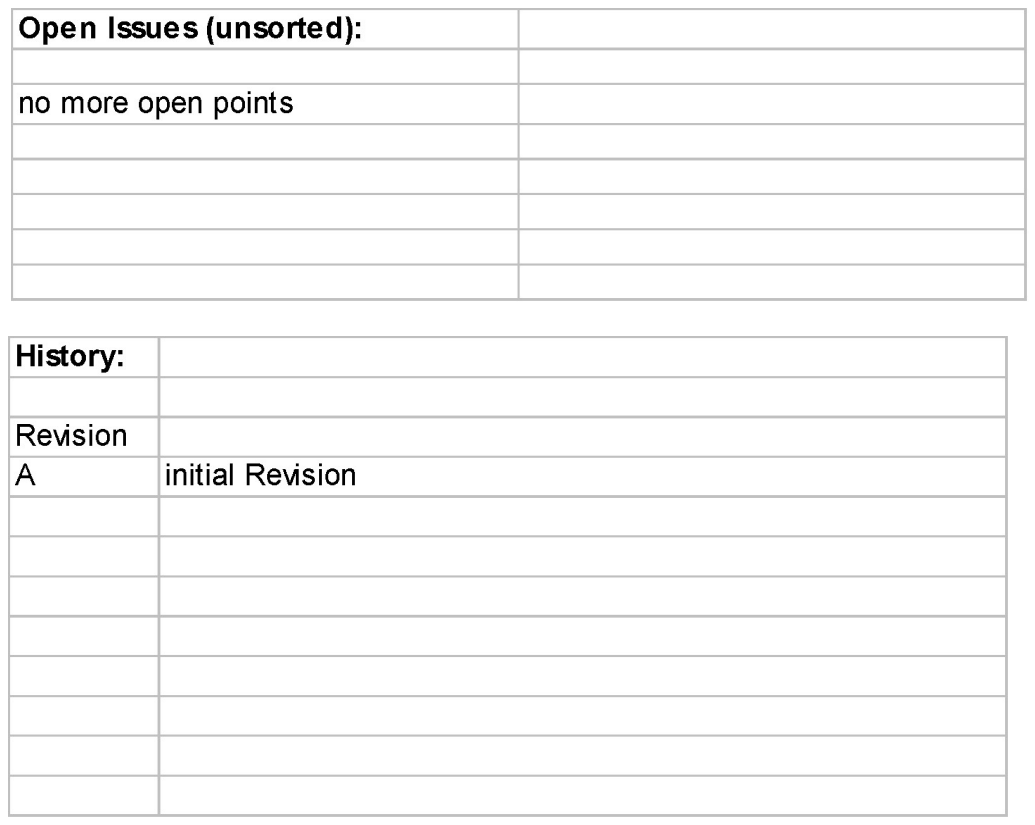
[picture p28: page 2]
OPEN_ISSUES; USBprog V3; BOARD NO; SIZE:; REV:; PROJECT TITLE:; SHEET TITLE

In-Circuit GmbH
Königsbrücker Str. 73
D-01099 Dresden
Germany

A

A

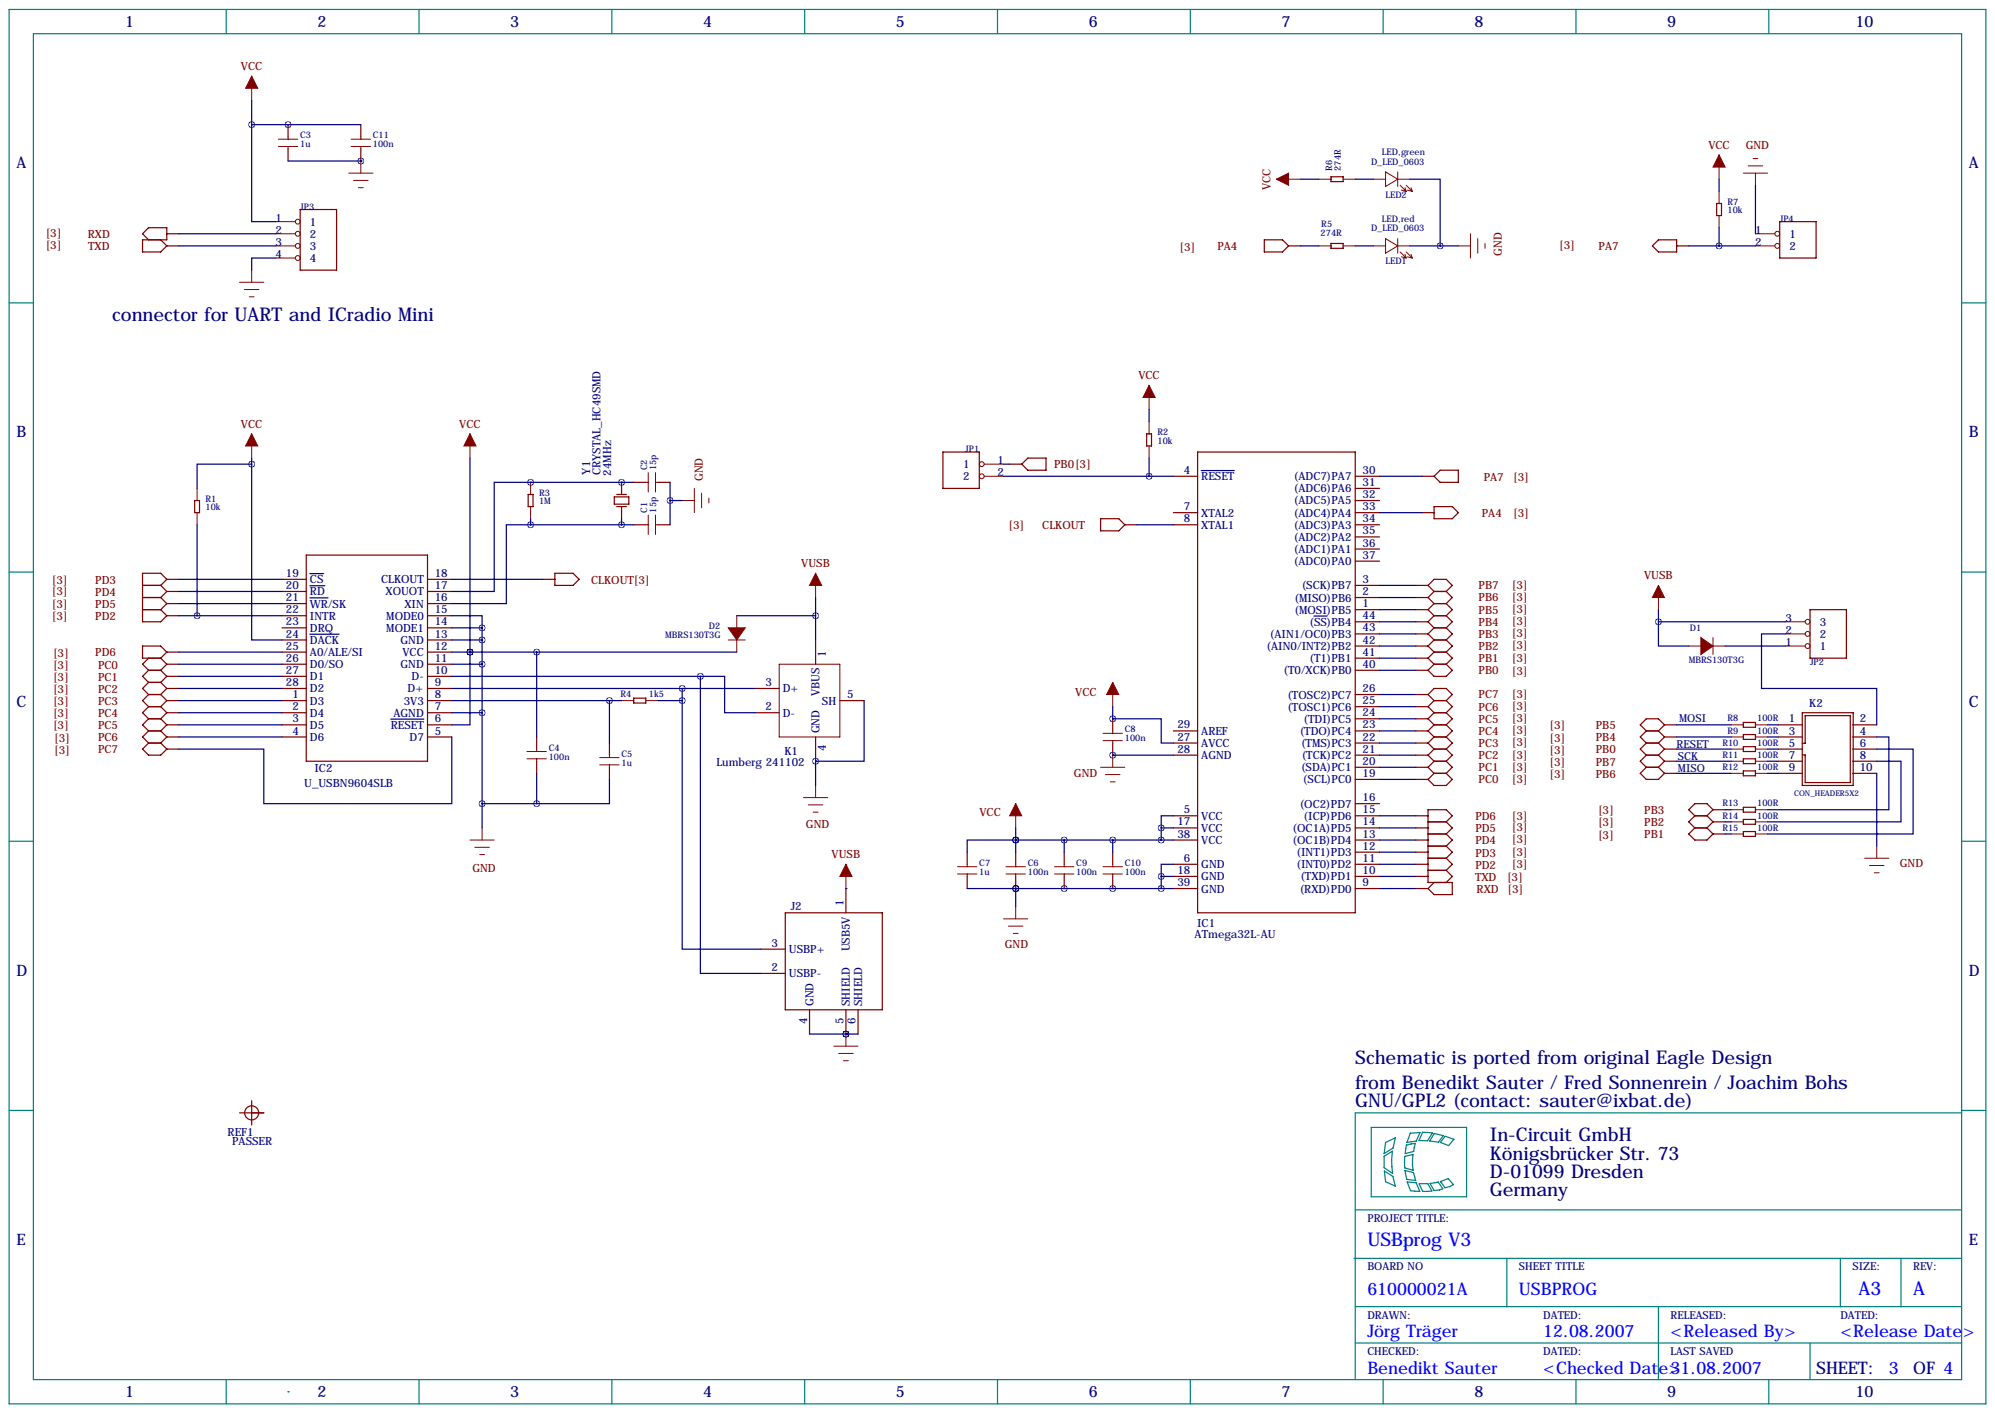
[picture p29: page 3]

connector for UART and ICradio Mini

14 MODE1
13 GND

D3 2 D4 3 D5 4 | 12 VCC

11 GND

Schematic is ported from original Eagle Design
from Benedikt Sauter / Fred Sonnenrein / Joachim Bohs
GNU/GPL2 (contact: sauter@ixbat.de)

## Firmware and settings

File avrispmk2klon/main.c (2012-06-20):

/*
* usbprog - A Downloader/Uploader for AVR device programmers
* Copyright (C) 2006 Benedikt Sauter
* Copyright (C) 2008 Hartmut Birr
*
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
* You should have received a copy of the GNU General Public License
* along with this program; if not, write to the Free Software
* Foundation, Inc., 59 Temple Place, Suite 330, Boston, MA  02111-1307  USA
*/

#include <stdlib.h>
#include <stdint.h>
#include <avr/io.h>
#include <avr/interrupt.h>
#include <inttypes.h>
#include <string.h>

#ifndef min
#define min(x, y)   ((x) < (y) ? (x) : (y))
#endif


//#define AT89MODE

//#define F_CPU 16000000
#include <util/delay.h>

#define DEBUG_ON 0

#include "wait.h"

#include "../usbprog_base/firmwarelib/avrupdate.h"

#if DEBUG_ON
#include "uart.h"
#endif

#include "usbn2mc.h"

/* command descriptions for mk2 */
#include "avr069.h"

#include <avr/pgmspace.h>

#include <avr/eeprom.h>

#include "uart.h"

#define NDEBUG
#include "debug.h"

#ifndef EEMEM
// alle Textstellen EEMEM im Quellcode durch __attribute__ ... ersetzen
#define EEMEM  __attribute__ ((section (".eeprom")))
#endif

uint8_t ee_sck_duration EEMEM = 1;
uint16_t sck_delay_value;

/**Structures to parse incoming packets more clearly
 */

struct cmd_enter_progmode_s {
  unsigned char id;
  unsigned char timeout;
  unsigned char stabdelay;
  unsigned char cmdexedelay;
  unsigned char synchloops;
  unsigned char bytedelay;
  unsigned char pollvalue;
  unsigned char pollindex;
  unsigned char cmd1;
  unsigned char cmd2;
  unsigned char cmd3;
  unsigned char cmd4;
};

struct cmd_spi_multi_s {
  unsigned char id;
  unsigned char numTx;
  unsigned char numRx;
  unsigned char rxStart;
  unsigned char txData[256]; //This can only be used if multiple-packet commands are supported
};

#define DDR_SPI     DDRB
#define SS PB4
#define MOSI  PB5
#define MISO  PB6
#define SCK   PB7
#define RESET_PIN   PB0
#define RESET_PORT  PORTB
#define LED_PIN     PA4
#define LED_PORT    PORTA

#define LED_on     (LED_PORT   |=  (1 << LED_PIN))   // red led
#define LED_off    (LED_PORT   &= ~(1 << LED_PIN))
#define RESET_high (RESET_PORT |=  (1 << RESET_PIN))
#define RESET_low  (RESET_PORT &= ~(1 << RESET_PIN)) // reset

/*** prototypes and global vars ***/
/* send a command back to pc */
void CommandAnswer(uint8_t length);
void QueueFirstAnswerByte(uint8_t);
void QueueAnswerByte(uint8_t);
void QueueLastAnswerByte(uint8_t);

volatile struct usbprog_t {
  char lastcmd;
  int longpackage;
  int cmdpackage;
  int datatogl;
  unsigned int sck_duration;
  uint16_t fill_pos;
  uint16_t send_pos;
  int avrstudio;
  int reset_pol;
  uint8_t ready_to_transmit: 1;
  uint8_t complete:     1;
} usbprog;

#define _BUF_LEN     300
#define _TMP_OFFSET  32
volatile char answer[_BUF_LEN];

struct pgmmode_t {
  uint16_t numbytes;
  uint8_t mode;
  uint8_t delay;
  uint8_t cmd1;
  uint8_t cmd2;
  uint8_t cmd3;
  uint8_t poll1;
  uint8_t poll2;
  uint32_t address;
  uint32_t pageaddress;
  uint8_t status;
  uint16_t poll_address;
  uint8_t poll_address_valid :1;
  uint8_t poll_address_odd   :1;
  uint8_t large_flash        :1;
  uint16_t ext_address;
} pgmmode;


unsigned short sck_lookup[]PROGMEM =
{
    0, 0, 0, 0, 2, 6, 14, 18, 20, 21, 23, 24, 26, 27, 29, 30, 32, 33, 36, 38,
    39, 41, 44, 45, 48, 50, 53, 56, 59, 62, 65, 68, 71, 75, 78, 83, 87, 92, 96,
    101, 105, 111, 116, 122, 128, 135, 141, 149, 156, 164, 171, 180, 189, 198,
    209, 218, 230, 240, 252, 264, 278, 291, 306, 321, 338, 354, 371, 390, 408,
    429, 450, 473, 495, 521, 546, 573, 602, 630, 662, 695, 729, 763, 803, 842,
    884, 927, 972, 1020, 1069, 1122, 1177, 1236, 1297, 1360, 1428, 1498, 1571,
    1648, 1729, 1814, 1904, 1998, 2096, 2198, 2307, 2419, 2539, 2664, 2795,
    2930, 3074, 3229, 3387, 3550, 3729, 3911, 4104, 4299, 4512, 4737, 4973,
    5206, 5462, 5728, 6022, 6307, 6620, 6942, 7297, 7660, 8030, 8401, 8847,
    9257, 9706, 10202, 10693, 11233, 11762, 12343, 12985, 13603, 14283, 14923,
    15623, 16391, 17239, 18016, 19045, 19998, 20962, 22000, 23092, 24211, 25410,
    26664, 27970, 29323, 30767, 32308, 33896, 35521, 37311, 39136
};

#define MAX_SCK_DURATION ((sizeof(sck_lookup)/sizeof(unsigned short))-1)



SIGNAL(SIG_INTERRUPT0)
{
  USBNInterrupt();
}

extern void (*avrupdate_jump_to_boot)( void ); 

void flashUartTxData(void);

/* id need for live update of firmware */
void USBNDecodeVendorRequest(DeviceRequest *req)
{
    DPRINT(PSTR("USBNDecodeVendorRequest()\n"));
    if(req->bRequest == STARTAVRUPDATE) {
        DPRINT(PSTR("avrupdate_jump_to_boot=%04x\n"), *avrupdate_jump_to_boot);
        cli();
#ifdef DEBUG
        flashUartTxData();
        _delay_ms(1);
#endif
        avrupdate_start();
    }
}

void USBNDecodeClassRequest(DeviceRequest *req)
{
    DPRINT(PSTR("USBNDecodeClassRequest()\n"));
    USBNWrite(EPC0,USBNRead(EPC0)|STALL);
}

void spi_init(void)
{
  usbprog.sck_duration = eeprom_read_byte(&ee_sck_duration);
  if(usbprog.sck_duration > MAX_SCK_DURATION)  // prevent error when EEPROM is erased
    usbprog.sck_duration = 0x03;  //  1MHz as default

  DPRINT(PSTR("spi_init(), usbprog.sck_duration = %u\n"), usbprog.sck_duration);

  PORTB   &=  ~((1 << SCK)|(1<<MISO)|(1<<MOSI)/*|(1<<RESET_PIN)*/);  // SCK have to be low in IDLE
  DDR_SPI &=~(1 << MISO);
  DDR_SPI = (1 << MOSI)|(1 << SCK)|(1 << RESET_PIN);
  // switches back to slave mode !
  DDR_SPI |= (1<<SS); // make SS an output for SPI master.

  SPCR = 0;
  SPSR = 0;

  //This delay value is also required in hardware SPI mode in spi_pulseclockonce
  sck_delay_value=pgm_read_word(&(sck_lookup[usbprog.sck_duration]));

    switch(usbprog.sck_duration)
    {
       case 0x00:  //08MHz
        SPCR = (1<<SPE)|(1<<MSTR);
        SPSR = (1<<SPI2X);
        break;

      case 0x01:  //04MHz
        SPCR = (1<<SPE)|(1<<MSTR);
        SPSR = 0x00;

        break;

      case 0x02:  //02MHz
        SPCR = (1<<SPE)|(1<<MSTR)|(1<<SPR0);
        SPSR = (1<<SPI2X);
        break;

      case 0x03:	//01MHz
        SPCR = (1<<SPE)|(1<<MSTR)|(1<<SPR0);
        SPSR = 0x00;
        break;

      case 0x04:  //500kHz
        SPCR = (1<<SPE)|(1<<MSTR)|(1<<SPR1);
        SPSR = (1<<SPI2X);
        break;

      case 0x05:  //250kHz
        SPCR = (1<<SPE)|(1<<MSTR)|(1<<SPR1);
        SPSR = 0x00;
        break;

      case 0x06:  //125kHz
        SPCR = (1<<SPE)|(1<<MSTR)|(1<<SPR0)|(1<<SPR1);
        SPSR = 0x00;
        break;

	  default:
        PORTB   &=  ~(1 << SCK);
        DDR_SPI &=~(1 << MISO);
        DDR_SPI = (1 << MOSI)|(1 << SCK)|(1 << RESET_PIN);
		break;
    }
}


void spi_idle(void)
{
  //DDR_SPI = 0x00;
  DDR_SPI &= ~( (1<<MOSI) | (1<<SCK) | (1<<RESET_PIN) ); // don't make SS an input !
  //PORTB = 0xFF;	// only temp for jar
  PORTB = 0x00; // holger klabunde: tri state without pullups
}

void spi_active(void)
{
  PORTB   &=  ~((1<<MISO)|(1 << MOSI)|(1 << SCK)|(1 << RESET_PIN));  // switch off unused Pullup resistors
  DDR_SPI &=~(1 << MISO);
  DDR_SPI |= (1 << MOSI)|(1 << SCK)|(1 << RESET_PIN);
}

/** Full-duplex SPI communication. For sck_duration<=6, use hardware SPI. For
 * >=6, use software spi.
 * From AT90S2313 datasheet, timing is:
 * set data, wait for 1/2 period, clock high, wait another
 * 1/2 period, read data, clock low. In other words: AVR clocks in on rising
 * edge, AVRISP clocks in on falling edge
 *
 * However, for AT89xx (AT89S51, chapter 21), there is a setup period from data
 * to sck high and also a hold period from sck low to data change. Therefore,
 * sck and mosi run 90 degree out of phase:
 * -Setup data, wait
 * -SCK high, wait
 * -Read data, wait
 * -SCK low, wait
 *
 * This guarantees compatibility with both AVR and AT89 controllers, when
 * soft SPI mode is used.
 */

unsigned char spi_inout(unsigned char data)
{
  unsigned char bitvalue,din=0;

  if(usbprog.sck_duration <= 6)
  {
    SPDR = data;
    while ( !(SPSR & (1 << SPIF)) ) ;
    return SPDR;
  }
  else    // software SPI with delay
  {
    for (bitvalue=128;bitvalue;bitvalue>>=1)
    {
      //set new data
      if(data & bitvalue)
        PORTB   |=  (1 << MOSI);
      else
        PORTB   &=  ~(1 << MOSI);

      //wait 1/4 period
      _delay_loop_2(sck_delay_value>>1);

      //set clock high
      PORTB   |=  (1 << SCK);

      //wait another 1/4 period
      _delay_loop_2(sck_delay_value>>1);

      //read in bit
      if( PINB & (1<<MISO)) {
        din|=bitvalue;
      }

      //wait another 1/4 period
      _delay_loop_2(sck_delay_value>>1);

      //clear clock
      PORTB   &=  ~(1 << SCK);

      //wait another 1/4 period
      _delay_loop_2(sck_delay_value>>1);

    }
    return din;
  }
}

/**According to the syncronisation protocol recommended by atmel, the SCLK must
 * be pulsed once every retry to try to get in sync. This can't be done in
 * hardware spi mode, so switch to software temporarily
 */

void spi_pulseclockonce(void) {
  unsigned char spcr_save,spsr_save;
  spcr_save=SPCR;
  spsr_save=SPSR;
  SPCR = 0;
  SPSR = 0;
  //pulse
  _delay_loop_2(sck_delay_value);
  PORTB   |=  (1 << SCK);
  _delay_loop_2(sck_delay_value);
  PORTB   &=  ~(1 << SCK);

  SPCR=spcr_save;
  SPSR=spsr_save;
}

uint8_t spi_cmd(uint8_t cmd, uint16_t address, uint8_t data)
{
    spi_inout(cmd);
    spi_inout(address>>8);
    spi_inout(address);
    return spi_inout(data);
}

void spi_out(char data) {
  spi_inout(data);
}
char spi_in(void) {
  return spi_inout(0);;
}

void program_fsm(uint8_t* buffer, uint8_t eeprom)
{
  uint8_t databytes = 64;
  static uint8_t *ptr;

  if (usbprog.cmdpackage) {
    // skip the header bytes
    buffer += 10;
    databytes -= 10;
    
    if (eeprom) {
      answer[0] = CMD_PROGRAM_EEPROM_ISP;
      ptr = (uint8_t*)answer +_TMP_OFFSET;  // reserve some space at beginning of the buffer to handle
                                            // answer packets during programming if necessary
      if (pgmmode.numbytes > sizeof(answer) - _TMP_OFFSET) {
        answer[1] = STATUS_CMD_FAILED;      // we are not able to program more than this
                                            // in one cycle, because we haven't enough RAM
                                            // AVR-Studio sends max. 128 Bytes in one USB-Packet
                                            // so this should never happen...
      } else {
        answer[1] = STATUS_CMD_OK;
      }
    }
  }
  #if DEBUG_ON
  UARTWrite("pgm num ");
  SendHex(pgmmode.numbytes);
  UARTWrite("\r\n ");
  #endif


  if (pgmmode.numbytes>databytes) {
    pgmmode.numbytes-=databytes;
    usbprog.longpackage=1;        //Expect more data
  } else {
    databytes=pgmmode.numbytes;   //The number of valid bytes in this packet
    pgmmode.numbytes=0;           //No more data left
    usbprog.longpackage=0;        //Expect no more data
  }

  if (eeprom && answer[1] == STATUS_CMD_OK) {
    // copy the datas to our temp buffer
    memcpy(ptr, buffer, databytes);
    ptr += databytes;
  }
  if (!eeprom || pgmmode.numbytes == 0)
  {
    uint8_t poll;
    uint8_t i;
    uint8_t loop;
    uint8_t tmp;

    if (eeprom) {
      if (answer[1] != STATUS_CMD_OK) {
        // we got a buffer overflow, 
        // we must eat up all bytes before we can return an error
        pgmmode.status = STATUS_CMD_OK;
        pgmmode.poll_address_valid = 0;
        QueueFirstAnswerByte(CMD_PROGRAM_EEPROM_ISP);
        QueueLastAnswerByte(answer[1]);
        return;
      }
      // set the pointer to the saved datas  
      buffer = (uint8_t*)answer + _TMP_OFFSET;
      databytes = ptr - buffer; 
      poll = pgmmode.poll2;
    } else {
      poll = pgmmode.poll1;
    }

    for (i = 0; i < databytes; i++, buffer++) {
      if (pgmmode.large_flash && (pgmmode.address >> 16) != pgmmode.ext_address){
        // set the extended page address
        pgmmode.ext_address = pgmmode.address >> 16;
        spi_cmd(0x4d, pgmmode.ext_address, 0x00);
      }
      if (!eeprom) {
        if (i&1){
          pgmmode.cmd1 |= 8;
        }else{
          pgmmode.cmd1 &= ~8;
        }
      }
      spi_cmd(pgmmode.cmd1, pgmmode.address, *buffer);
      if (!(pgmmode.mode & 1)) {
        // byte/word mode
        loop = 200; // 200*250usec = 50msec
        if (pgmmode.mode & 8) {
          // RDY/BSY polling
          do {
            _delay_us(250);
            tmp = spi_cmd(0xf0, 0, 0);
          }
          while ((tmp & 1) && --loop);

          if (tmp & 1) {
            pgmmode.status = STATUS_RDY_BSY_TOUT;
          }
        }else if ((pgmmode.mode & 4) && *buffer != poll) {
          // value polling
          if (!eeprom) {
            if (i&1){
              pgmmode.cmd3 |= 8;
            }else{
              pgmmode.cmd3 &= ~8;
            }
          } 
          do{
            _delay_us(250);
            tmp = spi_cmd(pgmmode.cmd3, pgmmode.address, 0);
          }while(tmp != *buffer && --loop);

          if (tmp != *buffer) {
            pgmmode.status = STATUS_CMD_TOUT;
          }
        } else{
          wait_ms(pgmmode.delay);
        }
      } else { 
        if (*buffer != poll && !pgmmode.poll_address_valid) {
          pgmmode.poll_address = pgmmode.address;
          pgmmode.poll_address_odd = i&1; 
          pgmmode.poll_address_valid = 1;
        }
      }
      if (eeprom || (i&1)) {
        pgmmode.address++;
      }
    }

    if (pgmmode.numbytes==0) {
      if ((pgmmode.mode & 0x81) == 0x81) {
        // page mode
        loop = 200; // 200*250usec = 50msec
        spi_cmd(pgmmode.cmd2, pgmmode.pageaddress, 0);

        if (pgmmode.mode & 0x40){
          // RDY/BSY polling
          do {
            _delay_us(250);
            tmp = spi_cmd(0xf0, 0, 0);
          }
          while ((tmp & 1) && --loop);

          if (tmp & 1) {
            pgmmode.status = STATUS_RDY_BSY_TOUT;
          }
        }else if ((pgmmode.mode & 0x20) && pgmmode.poll_address_valid) {
          // value polling
          if (!eeprom) {
            if (pgmmode.poll_address_odd) {
              pgmmode.cmd3 |= 8;
            }else{
              pgmmode.cmd3 &= ~8;
            }  
          }
          do{
            _delay_us(250);
            tmp = spi_cmd(pgmmode.cmd3, pgmmode.poll_address, 0);
          }while(tmp == poll && --loop);

          if (tmp == poll) {
            pgmmode.status = STATUS_CMD_TOUT;
          }
        }else {
          // timed delay
          wait_ms(pgmmode.delay);
        }
      }
      QueueFirstAnswerByte(eeprom ? CMD_PROGRAM_EEPROM_ISP : CMD_PROGRAM_FLASH_ISP);
      QueueLastAnswerByte(pgmmode.status);
      pgmmode.status = STATUS_CMD_OK;
      pgmmode.poll_address_valid = 0;
    }
  }
}

void USBToglAndSend(void)
{
  uint8_t sreg = SREG;
  cli();
  if(usbprog.datatogl == 1) {
    USBNWrite(TXC1, TX_LAST+TX_EN+TX_TOGL);
    usbprog.datatogl = 0;
  } else {
    USBNWrite(TXC1, TX_LAST+TX_EN);
    usbprog.datatogl = 1;
  }
  SREG = sreg;
}

void SendCompleteAnswer(void)
{
  uint8_t size, sreg = SREG;
  cli();

  if(usbprog.send_pos >= usbprog.fill_pos) {
    SREG = sreg;
    return;
  }

  USBNWrite(TXC1, FLUSH);
  if (usbprog.fill_pos > usbprog.send_pos + 64)
  {
    size = 64;
  }
  else
  {
    size = usbprog.fill_pos - usbprog.send_pos;
  }
  USBNWriteBlock(TXD1, (unsigned char*)answer + usbprog.send_pos, size, 0);
  usbprog.send_pos += size;

  pgmmode.numbytes = 0;
  USBToglAndSend();
  
  SREG = sreg;
}

#if 0
void NackEvent(unsigned int number)
{
  if(number & 0x20) 
    USBNWrite(TXC1, FLUSH);

  if(number & 0x02) 
    USBNWrite(RXC1, FLUSH+RX_EN);
    USBNWrite(TXC1, FLUSH);
    if(usbprog.datatogl == 1) {
      USBNWrite(TXC1, TX_LAST+TX_EN+TX_TOGL);
      usbprog.datatogl=0;
    } else {
      USBNWrite(TXC1, TX_LAST+TX_EN);
      usbprog.datatogl=1;
    }
  }
}
#endif

void QueueAnswerByte(uint8_t data)
{
  uint8_t sreg;

  sreg = SREG;
  cli();

  answer[usbprog.fill_pos++] = data;
  if (usbprog.ready_to_transmit && usbprog.fill_pos >= usbprog.send_pos + 64) {
    CommandAnswer(64);
  }

  SREG = sreg;
}

void QueueFirstAnswerByte(uint8_t data)
{
  uint8_t sreg;

  sreg = SREG;
  cli();

  usbprog.ready_to_transmit = 1;
  usbprog.complete = 0;
  usbprog.fill_pos = 0;
  usbprog.send_pos = 0;

  SREG = sreg;

  QueueAnswerByte(data);

}

void QueueLastAnswerByte(uint8_t data)
{
  uint8_t sreg;
  uint16_t size;

  QueueAnswerByte(data);

  sreg = SREG;
  cli();

  usbprog.complete = 1;
  if (usbprog.ready_to_transmit) {
    size = usbprog.fill_pos - usbprog.send_pos;
    CommandAnswer(size > 64 ? 64 : size);
  }

  SREG = sreg;
}

void CommandAnswer(uint8_t length)
{
  uint8_t sreg = SREG;
  cli();
  USBNWrite(TXC1, FLUSH);
  USBNWriteBlock(TXD1, (uint8_t*)answer + usbprog.send_pos, length, 0);
  USBToglAndSend(); /* control togl bit */
  usbprog.send_pos += length;
  usbprog.ready_to_transmit = 0;
  SREG = sreg;
}

/** Enter ISP programming mode
 */
void cmd_enter_progmode(struct cmd_enter_progmode_s *cmd) {
  #if DEBUG_ON
  UARTWrite("enter\r\n");
  #endif
  #if DEBUG_ON
  int i;
  for (i=0;i<12;i++) {
    SendHex(*((char *)cmd+i));
    UARTPutChar(' ');
  }
  SendHex(cmd->cmd1);
  #endif
  pgmmode.address = 0;
  pgmmode.status = STATUS_CMD_OK;
  pgmmode.ext_address = 0xffff;
  pgmmode.large_flash = 0;
  pgmmode.poll_address_valid = 0;
  spi_active();
  LED_on;

  PORTB &= ~(1<<SCK);

  if(usbprog.reset_pol==1)
  {
    PORTB &= ~(1<<RESET_PIN);
    wait_ms(10);
    PORTB |= (1<<RESET_PIN);  // give reset a positive pulse
    wait_ms(10);
    PORTB &= ~(1<<RESET_PIN);
    wait_ms(10);
    
    #ifdef AT89MODE 
    PORTB |= (1<<RESET_PIN);  // give reset a positive pulse
    wait_ms(10);
    #endif
  }
  else
  {
    PORTB |= (1<<RESET_PIN);  // give reset a positive pulse
    wait_ms(10);
    PORTB &= ~(1<<RESET_PIN);
    wait_ms(10);
    PORTB |= (1<<RESET_PIN);  // give reset a positive pulse
    wait_ms(10);
  }

  QueueFirstAnswerByte(CMD_ENTER_PROGMODE_ISP);

  wait_ms(cmd->cmdexedelay);

  int syncloops = cmd->synchloops;
  unsigned char result3,result4;
  for (;syncloops > 0; syncloops--) {
    spi_out(cmd->cmd1);
    wait_ms(cmd->bytedelay);
    spi_out(cmd->cmd2);
    wait_ms(cmd->bytedelay);
    result3 = spi_inout(cmd->cmd3);
    wait_ms(cmd->bytedelay);
    result4 = spi_inout(cmd->cmd4);
    wait_ms(cmd->bytedelay);

    if ((cmd->pollindex==0) ||
        ((cmd->pollindex==3) && (result3==cmd->pollvalue)) ||
        ((cmd->pollindex==4) && (result4==cmd->pollvalue))) {
      QueueLastAnswerByte(STATUS_CMD_OK);
      return;
    }

    //Apparently, we're not in sync. Pulse SCK once to get in sync
    #if DEBUG_ON
    UARTPutChar('#');
    #endif
    spi_pulseclockonce();
  };

  QueueLastAnswerByte(STATUS_CMD_FAILED);
  return;
}

/** Send/receive multiple spi bytes
 */
void cmd_spi_multi(struct cmd_spi_multi_s *cmd) {
  char send,receive;
  /*numsent *must* be int because char may overflow if numRx+rxStart
    becomes too large to fit in char */

  int numsent=0,numrecv=0;
  if (cmd->numTx>60||cmd->numRx>60) {
    //Not implemented
    QueueFirstAnswerByte(CMD_SPI_MULTI);
    QueueLastAnswerByte(STATUS_CMD_UNKNOWN);
  } else {
    QueueFirstAnswerByte(CMD_SPI_MULTI);
    QueueAnswerByte(STATUS_CMD_OK);
    for(numsent=0;(numsent<cmd->numTx)||(numrecv<cmd->numRx);numsent++) {
      if (numsent<cmd->numTx) send=cmd->txData[numsent]; else send=0;
      receive=spi_inout(send);
      if (numsent>=cmd->rxStart) {
        //past this point, the data received from the AVR must be
        //sent to the USB
        QueueAnswerByte(receive);
        numrecv++;
      }
    }
    QueueLastAnswerByte(STATUS_CMD_OK);
  }
}
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
int main(void)
{
#ifdef DEBUG
  initTimer();
  initUart();
  initDebug();
#endif


  spi_init();
  spi_idle();

  USBNInitMC();

  USBNInit((struct usb_device_descriptor*)&avrispmk2klonDevice,
           (struct usb_configuration_descriptor_tab*)&avrispmk2klonConfigTab, 
           (struct usb_wstring_descriptor_tab*)&avrispmk2klonStringTab);

  usbprog.longpackage = 0;
  usbprog.avrstudio = 1;   // 1 no
  usbprog.send_pos = 0;
  usbprog.reset_pol = 1;  // 1= avr 0 = at89
  usbprog.datatogl=0; 

  DDRA = (1 << PA4);
  LED_off;
  RESET_high;

  USBNAddInEndpointCallback(1, RequestTransmit);




  sei();

  DPRINT1(PSTR("=========== AVRISP mk2 Clone ===========\n"));

  // start usb chip
  USBNStart();

  while(1)
  {
#if 0
    Worker();  
    _delay_us(250);
#else
    if (USBNGetRxStatus(1))
    {
        uint8_t Buffer[64];
        uint8_t size;
        size = USBNGetRxData(1, Buffer, 64);
        memset(Buffer + size, 0, sizeof(Buffer) - size);

#if defined(DEBUG) && !defined(NDEBUG) 

        DPRINT(PSTR("=====================================================\n"));

        for (uint8_t i = 0; i < size; i += 16)
        {
            uint8_t buf_len = 0;
            char line[100];
            for (uint8_t j = 0; j < 16 && i + j < size; j++)
            {
                buf_len += sprintf_P(line + buf_len, PSTR("%02x "), Buffer[i + j]);
            }
            DPRINT(PSTR("%s\n"), line);

        }
        DPRINT(PSTR("=====================================================\n"));
#endif
        USBFlash((char*)Buffer);
    }
    else
    {
//        _delay_us(100);
    }
#endif    
  }
}

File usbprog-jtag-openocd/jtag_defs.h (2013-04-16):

#ifndef __JTAG_DEFS_H__
#define __JTAG_DEFS_H__

	//jtag i/o pins
	#define JTAG_OUT PORTB
	#define JTAG_IN  PINB
	#define JTAG_DIR DDRB

	//ouput pins
	#define JTAG_PIN_TDI  0
	#define JTAG_PIN_TMS  1
	#define JTAG_PIN_TRST 2
	#define JTAG_PIN_SRST 3
	#define JTAG_PIN_TCK  4
	//input pins
	#define JTAG_PIN_TDO  5
	#define JTAG_PIN_EMU  6
	#define JTAG_PIN_RTCK 5

	//JTAG usb commands
	//TODO: ADD commands to deal with RTCK ?
	//TODO: maybe add commands to query some firmware info...
	#define JTAG_CMD_TAP_OUTPUT     0x0
	#define JTAG_CMD_SET_TRST       0x1
	#define JTAG_CMD_SET_SRST       0x2
	#define JTAG_CMD_READ_INPUT     0x3
	#define JTAG_CMD_TAP_OUTPUT_EMU 0x4
	#define JTAG_CMD_SET_DELAY      0x5
	#define JTAG_CMD_SET_SRST_TRST  0x6

	//JTAG usb command mask
	#define JTAG_CMD_MASK       0x0f
	#define JTAG_DATA_MASK      0xf0

	//JTAG pins masks
	#define JTAG_OUTPUT_MASK ((1<<JTAG_PIN_TDI)|(1<<JTAG_PIN_TMS)|(1<<JTAG_PIN_TRST)|(1<<JTAG_PIN_SRST)|(1<<JTAG_PIN_TCK))
	#define JTAG_INPUT_MASK  ((1<<JTAG_PIN_TDO)|(1<<JTAG_PIN_EMU)|(1<<JTAG_PIN_RTCK))
	#define JTAG_SIGNAL_MASK ((1<<JTAG_PIN_TDI)|(1<<JTAG_PIN_TMS))

	#define JTAG_CLK_LO  ~(1<<JTAG_PIN_TCK)
	#define JTAG_CLK_HI   (1<<JTAG_PIN_TCK)

	//additional delay to make clk hi and lo approximately the same length, not sure if this is really needed
	#define JTAG_DELAY2 20

#endif //__JTAG_DEFS_H__

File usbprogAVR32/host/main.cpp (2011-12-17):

#include <stdio.h>
#include <string.h>
#include <time.h>
#include <ctype.h>
#include "cmd.h"
#include "cmd_tap_jtag.h"
#include "cmd_flash.h"

#define COMMAND_DETECT						1
#define COMMAND_READ						2
#define COMMAND_BLINK						3
#define COMMAND_PROG						4
#define COMMAND_TEST						5

#define BUFFER_SIZE							512


char g_file_name[256] = ""; //".\\flash.bin";
int  g_size = -1;
int  g_address = 0;
int  g_verify = 0;
int  g_command = COMMAND_BLINK;
FLASH_STR * g_flash = NULL;

void welcome(void);
void help(void);
int parse_options(int argc, char* argv[]);
int option_l(char* param);
int option_s(char* param);
int option_f(char* param);
int parse_command(int argc, char* argv[]);
int check(void);
int detect(void);
int read(void);
int program(void);
int test(void);
int blink(void);
void swap(char* buf, int num);

#pragma argsused
int main(int argc, char* argv[])
{
	int r, ver;
	U8 state;

	welcome();
	if (argc == 1) {
		help();
		return STATUS_OK;
	}

	if (parse_options(argc, argv) != STATUS_OK)
		return STATUS_ERROR;
	if (parse_command(argc, argv) != STATUS_OK)
		return STATUS_ERROR;
	if (check() != STATUS_OK)
		return STATUS_ERROR;

	/* Open the USBProg */
	if (usbprog_open() != USBPROG_STATUS_OK)
		return STATUS_ERROR;
	if (cmd_comm_firmware_version(&ver) != CMD_STATUS_OK) {
		puts("Could not get the firmware version.");
		return STATUS_ERROR;
    }
	printf("Firmware version is %d.\n", ver);

	//test();

	/* Execute */
	cmd_comm_init();
	cmd_tap_set_srst(0);
	if (detect() != STATUS_OK)
		return STATUS_ERROR;
	switch (g_command) {
	case COMMAND_BLINK:
		blink();
		break;
	case COMMAND_DETECT:
		/* Have done before */
		break;
	case COMMAND_READ:
		read();
		break;
	case COMMAND_PROG:
		program();
		break;
	case COMMAND_TEST:
		test();
		break;
	default:
		break;
	}

	cmd_tap_reset(100);
	cmd_tap_set_srst(0);

	usbprog_close();
	return 0;
}

void welcome(void)
{
	puts("USBProg AVR32 programmer\n");
}

void help(void)
{
	puts(
		"Usage: avr32prog [options] command\n"\
		"command:\n"\
		"  detect  detect some target information\n"\
		/*"  id      read target's idcode\n"\*/
		/*"  erase   erase the flash chip\n"\*/
		"  prog    program the flash\n"\
		"  read    read from the flash\n"\
		/*"  verify  program the flash chip\n"\*/
		"  help    show this help\n"\
		"options:\n"\
		/*"  -l [start btye address in decimal]  default=0\n"\*/
		"  -s [size in decimal]\n"\
		"  -f [binary_file_name]"\
		/*"  -v  verify\n"\*/
	);
}

int parse_options(int argc, char* argv[])
{
	int i = 0;
	char *str;

	for (i = 1; i < argc; i++) {
		str = argv[i];
		if ( *str == '-' ) {
			switch ( *(++str) ) {
			case 'l':
				if (option_l(argv[++i]) != STATUS_OK)
					return STATUS_ERROR;
				break;
			case 's':
				if (option_s(argv[++i]) != STATUS_OK)
					return STATUS_ERROR;
				break;
			case 'f':
				if (option_f(argv[++i]) != STATUS_OK)
					return STATUS_ERROR;
				break;
			case 'v':
				g_verify = 1;
				break;
			default:
				printf("Error: invalid option \'%s\'!", argv[i]);
				return STATUS_ERROR;
			}
			*argv[i] = '-';	// 让options的参数第一字符变为'-'以防函数parse_command再作处理
		}
	}

	return STATUS_OK;
}

int option_f(char* param)
{
	if ( (param == NULL) || (strlen(param) == 0) ) {
		puts("Error: no parameter with option \'-f\'!");
		return STATUS_INVALID_PARAM;
	}
	if (strlen(param) > 256) {
		puts("Error: parameter of option \'-f\' is too long!");
		return STATUS_INVALID_PARAM;
	}

	strcpy(g_file_name, param);

	return STATUS_OK;
}

int option_l(char* param)
{
	char *endptr;
	U32  addr;

	if ( (param == NULL) || (strlen(param) == 0) ) {
		puts("Error: no parameter with option \'-l\'!");
		return STATUS_INVALID_PARAM;
	}

	addr = (U32)strtod(param, &endptr);
	if ( *endptr != '\0' ) {
		puts("Error: parameter of option \'-l\' should be a decimal integral number!");
		return STATUS_INVALID_PARAM;
	}
	if ( addr <= 0 ) {
		puts("Error: address should be positive!");
		return STATUS_INVALID_PARAM;
	}
	if ( (addr % 2) != 0 ) {
		puts("Error: address should be 2 bytes aligned!");
		return STATUS_INVALID_PARAM;
	}
	g_address = addr;

	return STATUS_OK;
}

int option_s(char* param)
{
	char *endptr;
	U32  size;

	if ( (param == NULL) || (strlen(param) == 0) ) {
		puts("Error: no parameter with option \'-s\'!");
		return STATUS_INVALID_PARAM;
	}

	size = (U32)strtod(param, &endptr);
	if ( *endptr != '\0' ) {
		puts("Error: parameter of option \'-s\' should be a decimal integral number!");
		return STATUS_INVALID_PARAM;
	}
	if ( size <= 0 ) {
		puts("Error: size should be positive!");
		return STATUS_INVALID_PARAM;
	}
	if ( (size % 2) != 0 ) {
		puts("Error: size should be 2 bytes aligned!");
		return STATUS_INVALID_PARAM;
	}
	g_size = size;

	return STATUS_OK;
}

int parse_command(int argc, char* argv[])
{
	int r;
	char* cmdl = NULL;

	for (r = 1; r < argc; r++) {
		cmdl = argv[r];
		if ( *cmdl != '-' )		// if not options then command
			break;
	}

	if ( cmdl == NULL ) {
		puts("There is not any command, program exited.");
		return STATUS_ERROR;
	}

	for (r = 0; r < (int)strlen(cmdl); r++)
		cmdl[r] = (char)tolower(cmdl[r]);

	if ( !strcmp(cmdl, "help") ) {
		help();
		r = STATUS_ERROR;		// let the programm exit
	} else {
		r = STATUS_OK;
		if ( !strcmp(cmdl, "blink") ) {
			g_command = COMMAND_BLINK;
		} else if ( !strcmp(cmdl, "detect") ) {
			g_command = COMMAND_DETECT;
		} else if ( !strcmp(cmdl, "read") ) {
			g_command = COMMAND_READ;
		} else if ( !strcmp(cmdl, "prog") ) {
			g_command = COMMAND_PROG;
		} else if ( !strcmp(cmdl, "test") ) {
			g_command = COMMAND_TEST;
		} else {
			printf("Error: invalid command \'%s\'!", cmdl);
			r = STATUS_ERROR;
		}
	}
/*
	if (r == STATUS_OK) {
		printf("    command: \'%s\'\n", cmdl);
		printf("       file: \'%s\'\n", g_file_name);
		printf("  file size: %d\n", g_file_size);
		printf("       size: %d\n", g_size);
	}
*/
	return r;
}

int check(void)
{
	return STATUS_OK;
}
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

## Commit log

2011-12-17 copy all from berlios
    [Levelshifter.brd, Levelshifter.sch, levelshifter.brd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]
2013-04-16 add usbprog v4
    [usbprog_v4.brd, usbprog_v4.sch]

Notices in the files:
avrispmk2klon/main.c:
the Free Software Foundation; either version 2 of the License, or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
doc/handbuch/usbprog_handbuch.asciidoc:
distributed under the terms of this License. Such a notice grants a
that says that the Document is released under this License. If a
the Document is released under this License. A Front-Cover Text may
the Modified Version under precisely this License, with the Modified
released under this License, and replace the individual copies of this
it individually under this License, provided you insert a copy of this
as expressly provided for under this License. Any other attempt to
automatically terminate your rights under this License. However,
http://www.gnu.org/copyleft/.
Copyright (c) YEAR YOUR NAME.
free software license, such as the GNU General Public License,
